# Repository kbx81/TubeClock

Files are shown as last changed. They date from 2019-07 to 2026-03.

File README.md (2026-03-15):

# kbx's Nixie Clock

Nixie Clock project files - PCB and source

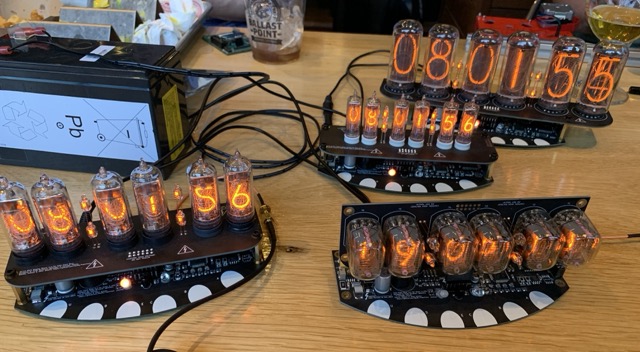
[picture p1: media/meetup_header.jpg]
Nixie clocks!


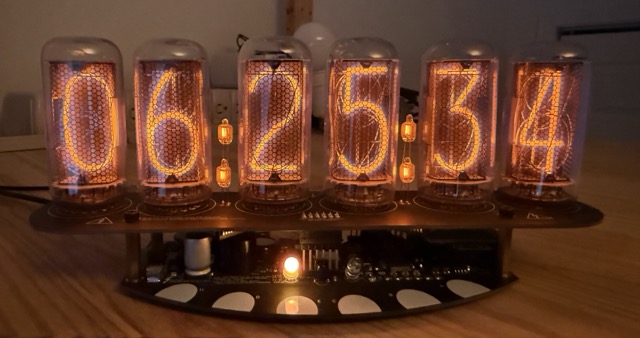
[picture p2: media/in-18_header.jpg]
IN-18


For more pictures, see the [gallery](GALLERY.md).

## Another nixie tube clock? Why?

I have to start by giving credit where credit is due. The
[Boldport Club](http://boldport.club), over the last couple of years, has
motivated me to dwell back into the world of electronics, at least as a
hobbyist. Both the kits themselves and the other members in the club are
amazing and helped inspire me to make something...so I began working on this
project. Some inspiration is taken from
[Touchy, BPC Project #7](https://www.boldport.com/products/touchy); this kit
enabled me to learn more about and actually experiment with capacitive touch.
It was clear early on that this would be a nice touch (pun intended) to add to
this project; visually, it is cleaner, it reduces the number of parts and, as a
result, it reduces the cost.

That said, the world probably doesn't need another tube clock. There are
plenty of them--all different shapes and sizes--so why build another one?

Last year, I built this lovely
[binary clock](https://github.com/kbx81/RGBBinaryClock). Some ten-plus years
ago I had built some IN-18 nixie clocks. Earlier this year (2019) one of them
became a little troublesome. I fixed it but, in the interim, became motivated
to build my own. As I already had a wonderful foundation for some clock
hardware, this seemed a natural progression. Overall I'm quite happy with the
results if I may say so myself. :)

_Sooo...another nixie clock? What's special about it?_

**Time & display**
- Shows time, date, and temperature — with a timer/counter mode, too
- 12/24-hour format and °C/°F selectable
- Smooth digit crossfades with configurable animations and effects
- Auto-dims based on ambient light — great for a bedside clock :)

**Time sources** _(all optional — mix and match)_
- GPS sync via a soldered-on LIV3F module or an
  [Adafruit GPS breakout](https://www.adafruit.com/product/746)
- External DS3234 precision RTC
- CR2032 battery or supercapacitor backup to keep time through a power outage

**Control & connectivity**
- Capacitive touch keys
- IR remote control
- [Serial remote protocol](docs/SERIAL_API.md) over UART or USB (CDC-ACM
  virtual serial port)
- Optional Wi-Fi add-on board for wireless control -- I even built an
  [ESPHome external component](https://github.com/kbx81/esphome_external_components/tree/main/components/tube_clock)
- DMX-512 via RS-485 — control each tube individually from a lighting console

**Alarms & audio**
- Up to 8 configurable alarm times with optional display blink
- Hourly binary chime — hear the time from another room!
- RTTTL melody playback
- External alarm trigger via expansion pin header

## What makes it tick?

The brain is an **STM32F072** microcontroller — capable enough on its own, but
with optional add-ons for those who want more:

- **DS3234** — high-accuracy external RTC (also has a built-in temperature sensor)
- **DS1722 / LM74** — dedicated external temperature sensors
- **LIV3F** or **[Adafruit GPS module](https://www.adafruit.com/product/746)**
  for synchronizing time from GPS

The display boards use **HV5622** high-voltage shift registers to drive the
tubes, an **RGB status LED** for at-a-glance info, and a **piezo beeper**
capable of playing RTTTL tunes. An onboard phototransistor handles ambient
light sensing for automatic brightness control.

## How do I get or build one?

In this repository you'll find everything needed to put one together. It is
divided into two major parts: hardware and software (source). The `hardware`
directory contains the [KiCad](http://kicad.org) project files used to create
the printed circuit board. The `src` directory contains the source code needed
to compile and run the application on the microcontroller. It is built on top
of [libopencm3](http://libopencm3.org). Finally, then `bin` directory contains
compiled binary files you may flash directly onto the microcontroller...great
for folks who want to solder something together but don't want to be bothered
with compiling code!

Additional details regarding the hardware and software can be found in the
`README.md` files located in each respective directory.

**That's all for now...thanks for visiting!**

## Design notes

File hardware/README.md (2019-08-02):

# kbx's Tube Clock

Tube Clock PCB project files for KiCad (v5)

## How do I get PCBs made for this?

Detailing the process is a bit outside of what I plan to discuss here. There are
 plenty of resources out around the web already that will do a better job of
 explaining this process than I can. That said, there's not much to it -- the
 files you need are here and all you need to do (more or less) is upload them
 to your PCB fabricator of choice and, after a few days, they'll ship them
 to you. I've used [Elecrow](http://elecrow.com) for the prototypes and I can
 assure you that they've turned out fantastic boards given the price.

As the vast majority of the components on this board are surface-mount parts,
 hot air is a fun approach for soldering it all together. If you go this route
 (and especially if you plan to build more than one of them), you'll likely want
 to have a stencil made to help with the placement of solder paste onto the
 board. I ordered a stencil with my board from [Elecrow](http://elecrow.com).

## If I get boards made, how do I build it?

All the components are listed in the KiCad project files here; one will also
 find bill of materials (BoM) files named `TubeClock.BoM.md` or `IN-1x.BoM.md`
 containing these lists. For "unusual" parts (things that aren't resistors or
 capacitors) I've noted a suggested part number that should serve as a point of
 reference to help you find your own.

Before you order parts, be sure to read through the build notes below!

Once you have your boards and parts, there are at least a couple of different
 ways you can build the clock base. Below are build notes.

## Build notes

### Before you begin...

...you need to determine:
1. What will your time source be -- the STM32's RTC, the DS3234, or a GPS
 module? The GPS will provide the best accuracy, followed by the DS3234. That
 said, these ICs will add approximately $10 to $20 USD to the cost of the
 device. If you're purchasing them, double-check those part numbers before
 ordering!
1. What temperature sensor will you use -- the STM32's internal sensor, the
 DS3234's sensor, or a dedicated sensor? The DS1722 or LM74 dedicated sensors
 will provide the best accuracy; however, if one of these ICs is not installed
 but a DS3234 *is* installed, the app will use the DS3234's sensor. Note that,
 while the PCBs have footprints for more than one temperature sensor, only
 **one** of them may be installed at a time. Do not install both!
1. Solder-bridge/jumper settings. These are explained below...but don't forget
 about these!

Once you've settled on the items above, read on (below) for more detail and
 specifics regarding the build.

### Build details

#### GPS:

The clock's application will accept and decode NMEA sentences from an attached
 GPS module. The PCBs will accept a plug-in module from
 [Adafruit](https://www.adafruit.com/product/746) or a Teseo-LIV3F module can
 be installed for a more permanent solution. Testing reveals that both of these
 modules work extremely well and will provide the most accurate time for the
 clock. Note that the LIV3F module will require some additional components to
 operate; several of these parts are 0402-sized (which means that they are very,
 very tiny!) and, as such, are challenging to work with. This approach is best
 for experienced builders with tooling available to work on such tiny parts.

#### External RTC:

The external RTC--the DS3234--adds a level of precision to the clock that is
 likely difficult to achieve with the STM32's internal RTC alone. These RTC ICs
 are designed to drift less than two minutes _per year_. It's possible that your
 STM32 hardware could end up being this accurate, but such accuracy is unlikely.
 Install this IC if you want a clock that is as accurate as is reasonably
 possible without depending on GPS. Note that this IC also has a built-in
 temperature sensor (that's part of how it maintains its precision) that the
 application will use if it is installed and the other external temperature
 sensor (below) is _not_ installed.

If you install a DS3234 on your clock, **do not install** these components:
 - `C23`
 - `R16`

#### External temperature sensors:
**U6 and U7**

A challenge with using the STM32's internal temperature sensor is that the
 sensor typically reads a few degrees higher than the temperature around the
 MCU itself. This is because the die, where the sensor is located, is usually
 just a little bit warmer then the package around it. An easy workaround is to
 just subtract a few degrees from the reading -- hence the calibration item
 you'll find in the application's menu structure. It works, but it requires
 someone to tweak it as each chip is likely to be a little different. Naturally,
 this takes away from its accuracy.

Installing an external temperature sensor is a great solution to this problem.
 The application will prefer an external sensor if one is installed; it first
 prefers one of the dedicated temperature sensors. If not installed, it will try
 to use the sensor integrated into the DS3234, should one be installed. If these
 all fail, it will use the STM32's internal sensor as a last resort.

**IMPORTANT NOTE: the PCBs (all hardware versions) have footprints for two
 external temperature sensor ICs. ONLY INSTALL ONE of them. DO NOT INSTALL
 BOTH.** If you install both, neither of them will work and you may cause damage
 to them or to other ICs on the board.

#### RS-485 transceiver:
**U8**

This part will enable the the second USART in the STM32 MCU to be used to
 communicate on an RS-485 bus. The original intention for this feature was to
 enable the device to receive a DMX-512 signal from an entertainment lighting
 console. With some development, it could also be used (for example) to
 synchronize a number of clocks with each other. This interface is more of a toy
 and has no impact on how the clock itself will function. You'll likely want to
 leave it off of the board unless you have a specific plan to use it for
 something.

#### Infrared (IR) receiver module:
**U4**

If the infrared remote control is not needed, this component may be left off of
 the board.

#### Buzzer/beeper components:
**BZ1, D6, Q6, R29**

If you don't want your clock to be able to make any noise at all, it is safe to
 leave these parts off of your board. It'll be sad, but it'll work just fine.

#### Status LED components:
**LED1, LED2, Q3 through Q5, R23 through R28**

The status LED is not typically used during normal operation, however it can be
 enabled as an AM/PM indicator if/when the clock is set in 12-hour mode. It can
 also provide troubleshooting information if your clock doesn't seem to be
 working. That said, it's not necessary unless you like LEDs as much as I do.

#### Reset/Boot buttons:

The reset and boot buttons are of course not required, but it is convenient if
 you plan to do any development with this platform on your own.

### Other requirements

#### 32.768 kHz crystal installation and connection:

A footprint for a 32.768 kHz crystal exists on the PCB. It is used to drive the
 STM32's internal RTC mechanism. This crystal is particularly important if the
 DS3234 IC is **not** installed; in this case, it must be connected to the MCU
 by creating a solder bridge across the appropriate two pads on `SB2`. Failure
 to do so--and if the DS3234 is not installed--means the clock won't run
 (although things otherwise may seem to work).

If the DS3234 **is** installed, `SB2` may be bridged so as to connect the
 DS323x's 32.768 kHz signal output to the STM32's OSC32 input. This is not
 required but it is recommended so that this MCU input isn't left floating. In
 addition, if `SB2` is bridged in this manner, the 32.768 kHz crystal (and its
 drive capacitors) should **not** be installed.

#### Phototransistor series resistors:
 **Q2, RV2, R7 and R10**

The phototransistor enables the application to determine the amount of ambient
 light around the clock so it can adjust the overall display intensity
 accordingly. There is a variable resistor in series with a fixed resistor which
 allows some manual adjustment over the sensitivity of this mechanism. There is
 also a single fixed resistor in parallel with this configuration. It is not
 necessary to install all of these, however it won't hurt anything if you do.
 If the specified phototransistor is used, a single 100K to 150K resistor
 installed for `R10` will probably work well.

#### Status LED:

If installing a status LED, install only LED1 **or** LED2. Do not install both.

### Solder Bridge Jumpers

#### Pulse-Per-Second (PPS) input selection
**SB1**

This jumper determines which peripheral will provide the pulse-per-second input
 to the processor (and application). This enables more precise refreshing of the
 display and allows the application to operate more efficiently. If neither of
 these peripherals is installed, this jumper is not used.

#### 32.768 kHz Oscillator jumper
**SB2**

This jumper determines if the 32.768 kHz oscillator or the DS3234's 32.768 kHz
 output pin is connected to the STM32's OSC32_IN pin. If a DS3234 is **not**
 installed on the board, it must be bridged so that the crystal's pin is
 connected to the OSC32_IN pin. Otherwise, it's best to bridge it to the
 DS3234's 32.768 kHz output pin. Labels on the PCB indicate which position is
 which.

#### USART 1/USB VBUS jumpers
**SB3, SB4**

These jumpers allow the configuration of which USART1 pin on the MCU is
 connected to the six-pin serial header. Because the processor's USB hardware
 expects USB VBUS on PA9, if you plan to use the USB port, SB4 should be bridged
 and SB3 should be bridged to put PB6 on the on the six-pin header. If you do
 not want/need to use the USB port and wish to flash the MCU via the six-pin
 header, SB4 must be left **open** and SB3 should be bridged to put PA9 on the
 six-pin header.

#### Reset Supervisor jumper
**SB5**

 This jumper determines if the DS3234's reset supervisor output pin is connected
  to the STM32's NRST (not-reset) pin. This should be connected if the DS3234 is
  installed, however it sometimes causes issues with flashing the MCU. If you
  installed a DS3234 and are having difficulty flashing the MCU, try
  disconnecting this jumper until the flashing process is complete. Don't forget
  to reconnect it, though!

#### RS-485 Terminator jumper
**SB6**

Bridge this jumper to connect the terminating resistor across the RS-485
 transceiver's input/output pins. This is useful if the board is at the end of
 a RS-485 link.

#### GPS receive and transmit lines
**SB7, SB8**

Bridge these jumpers to connect the GPS module's receive (Rx) and transmit (Tx)
 lines to the STM32 processor's USART1 interface. These jumpers are provided as
 a convenient way to disconnect the serial data lines in the event that USART1
 must be used for programming or debugging after the board has been built,
 particularly with the LIV3F module.

## Before powering it on for the first time...

WAIT! you didn't plug it in yet, did you? Let's do some pre-flight checks to get
 ready to bring up your board!

It's important that we go over the board with a DMM (or at least a continuity
 tester) and check for any nasty shorts. Solder bridges and poor part placement
 are the typical causes of this and it's not uncommon to have them, particularly
 with so many surface-mount parts. We don't want our brand-new clock to let out
 the magic smoke before we even get to use it, do we? :)

Generally, it will suffice to check a few key areas for shorts. Since these are
 surface-mount ICs, it's not uncommon to have solder bridges between some of the
 pins after you've soldered it all together. Don't worry, we can get away
 without checking _all_ of them, but we _do_ need to check a few. Let's make a
 list so we can check them off:
* **Check for shorts between the output of the LDO and ground.** Put one of your
 DMM probes on the power connector's ground pin and the other on the LDO's
 heatsink (the top fin soldered to the board -- this is its 3.3-volt output). If
 you see they're shorted, you'll have to go hunting for the short. Start by
 checking the power pins around the STM32 processor. All of its Vcc and ground
 pins are right next to each other so this is the best place to look first.
* **Check for shorts on the display pin header.** Note that there are multiple
 ground pins on this header so they will naturally appear to be shorted. It is
 important to check for shorts between the pins that supply the various voltages
 to the display board (3.3, 12, and 170 volts). Shorts between any of these pins
 will be disastrous!
* **Check that the solder bridge "jumpers" are set correctly.** You didn't
 forget to bridge these as appropriate, did you? :) See the "Jumpers" section
 above for information on how they should be set.

Once you've confirmed everything above looks good, it should be reasonably safe
 to proceed to the next step -- flashing the firmware onto the STM32 processor!
 After we do this, we'll be able to more effectively identify any other
 soldering-related issues that could be affecting the clock's operation.

After you power on your board for the first time--and if nothing blows
 up--you'll need to flash the firmware onto the STM32 MCU. Use either the USB
 interface, the SWD connection on P1, or the serial interface on J5. You'll need
 an appropriate adapter and/or cable to do so. You will find the source code and
 flashing instructions in the `src` folder one level up in the repo's hierarchy.
 The `bin` directory contains complied binary files for folks who do not wish to
 compile the source code. With the right tools in hand, this can be done in a
 couple of minutes.

If you're having trouble flashing the MCU, please see the next section.

## Troubleshooting

What's that? You couldn't flash the MCU? Or maybe it isn't working perfectly
 after you flashed the MCU? Uh oh...

As I've built...a few...of these to date, here is a list of common issues I've
 stumbled across as well as some notes on how to fix them.

If you're having trouble flashing the MCU, check these items first:
* If a DS3234 is installed, is the reset supervisor jumper bridged? If so, this
 may be holding the STM32 in a reset state too long and your programmer is
 giving up. Open this jumper and try again.
* If there is no DS3234 installed and/or the jumper is already open, check the
 data lines between the port you're using (six-pin serial, USB, or SWD) and the
 processor. Perhaps there is another nasty solder bridge somewhere that's
 shorting one or more of the lines to Vcc, ground, or another adjacent pin. If
 you're using the USB interface, take a close look at D5 and the physical USB
 port itself, as well. The pins on the USB connector are prone to bridging.

If you flashed the MCU and it's now doing...something...but it doesn't seem
 right, here are some more common symptoms and how to fix them:

* **Status LED blinks orange/off but the tubes are blank or flickering
 erratically.** This is indicative of some soldering problem on the SPI1 pins
 of the MCU or on one or more of the HV5622 drivers. Take a close look at these
 pins and rework them as necessary. Also be sure the socket on the display board
 is seated sufficiently onto the logic board's display pin header.
* **One or more of the touch keys don't work.** Check the 1K resistors that sit
 between the touch keys and the MCU as well as the 47 nF sense capacitors.
 Again, also check the relevant pins on the MCU itself for shorts to adjacent
 pins (this is the most common issue).
* **It keeps making a ticking sound.** There's a problem with one or more of the
 touch keys -- see the item above.
* **The status LED alternates red and yellow.** You did not install a DS3234 (or
 maybe you did and it's not working) and the STM32's RTC/LSE oscillator did not
 start within the expected amount of time. Check that `SB2` is bridged correctly
 and that the 32.768 kHz crystal and its bypass capacitors are installed and
 soldered correctly. Also check that the respective pins on the STM32 processor
 aren't shorted to adjacent pins (or to each other).

## Known Issues and Noteworthy Items

Heat from the boost converter (the part that generates the high voltage for the
 tubes) or GPS module can skew the temperature reading from the sensor on the
 board. This becomes more noticeable as the tubes become brighter. The PCBs
 include footprints for additional 2.54mm pin headers which could be used for
 mounting the temperature sensor(s) off of the main board.

## Legal stuff and License

The circuit schematics and PCBs found here are licensed under the
 [Creative Commons Attribution-ShareAlike 4.0 International License](http://creativecommons.org/licenses/by-sa/4.0/).



_Happy building!_

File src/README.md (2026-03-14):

# kbx's Tube Clock

Tube Clock firmware source files

## What's going on here?

Here you will find the C++ source code files for the Tube Clock. It is
modularized so that its various parts can be broken out and potentially re-used
for other projects. It's not perfect but it works well and the plan is to
continue to update and improve it over time.

The firmware implements all of the clock's functionality from the simple display
of the time and date through animation selection and management, alarms, and
even DMX-512 control for the display tubes. It could be easily modified to
provide a variety of other capabilities if desired.

## More specifics

The code is written for the STM32F072 microcontroller used on the Tube
clock. With a little effort, it should be relatively easy to port it to another
STM32Fx-series MCU. It relies on [libopencm3](http://libopencm3.org) as the
underlying platform to interface with the MCU. If you wish to do some hacking
with this platform, a nice guide can be found
[here](https://github.com/libopencm3/libopencm3-examples#reuse) which explains
how to clone libopencm3 for (re)use within your own (or this) project. Note
that if you do so, it may be necessary to tweak some paths in the Makefile(s),
but otherwise things should work without much trouble. You'll also (of course)
need a (gcc) compiler to build the code base. (At the time of this writing,
I've been building it with gcc on macOS.)

The STM32F072 microcontroller is a rich device with a lot of peripherals. Many
of these peripherals are leveraged in the code to enable it work as efficiently
as possible. For posterity, here is a list of the peripherals used:

- ADC - the analog to digital converter, used for sensing light level from the
  attached phototransistor
- CRC - used to compute a checksum for settings data stored in FLASH
- DMA - direct memory access controller, used to speedily move data to/from
  other I/O peripherals such as I2C, SPI, and USARTs
- FLASH controller - erases and writes settings to a dedicated block of FLASH so
  settings are retained across power failures and do not depend on the battery
- GPIO - because how else do you toggle pins on/off or read input signals?
- IWDG - the watchdog timer makes sure the MCU gets reset in the event of some
  catastrophic software crash/failure
- NVIC - none of this would be possible without interrupts.
- RTC - the real time clock is used if the DS3234 is not installed. Since it's a
  clock, you need a clock...sooooo...
- SPI - this is the interface (via DMA) to the tube driver ICs. It is also the
  interface to the DS3234 and other temperature sensors.
- Timers - Timers 1 and 3 are used to generate PWM for the buzzer and for the
  status LEDs, respectively. Timers 15 and 16 are used to supervise DMX-512
  communication. Timer 7 times pulses from the IR receiver and timer 2 generates
  an interrupt (at ~15.4 KHz) to trigger a refresh of the tubes, emulating PWM
  and thus enabling the digit dimming/fading effect.
- TSC - the touch sensing controller is used to sense touches on the touch keys.
- USARTs:
  - USART1 is a general serial interface connected to an optional GPS module; it
    also participates in the [serial remote control protocol](../docs/SERIAL_API.md)
    (see below).
  - USART2 is connected to an RS-485 transceiver; the firmware receives DMX-512
    signals on USART2 so that the tubes can be individually controlled remotely.
  - USART3 (RX) and USART4 (TX) form a secondary serial interface which supports
    the clock's bidirectional [serial remote control protocol](../docs/SERIAL_API.md).
  - Serial remote commands and responses are handled on both the USART1 and
    USART3/4 interfaces simultaneously. The same serial remote control protocol
    is also accessible via a USB CDC-ACM (virtual serial port) interface. See
    the [Serial Remote Control API](../docs/SERIAL_API.md) for the full protocol
    reference.

## Important!

When compiling (with gcc), you'll need to add `-DHARDWARE_VERSION=X` to the
command line, where `X` is the major version number of the hardware (PCB)
you're targeting. At the time of this writing, there is only one major hardware
version. Note that this switch has already been added to the included
Makefile. Please be aware of this if you choose to build it yourself and/or do
some hacking!

## I want to hack. Where do I start?

`TubeClock.cpp` is where it all begins. This connects the various
interrupts to the appropriate functions for processing them, initializes the
hardware, initializes the main application, then passes control to the main
application loop. See `Application.cpp` and `Hardware.cpp` and work your way
through the rest from there.

To build the code, there is a basic Makefile in the `src/v1` directory; simply
run `make` and it'll build what you need. Then, you can write the resulting
binary to the STM32 via an ST-Link with:

```shell
st-flash write TubeClock.bin 0x08000000
```

For more advanced debugging, you can use GDB. Run `st-util --n` followed by
`arm-none-eabi-gdb TubeClock.elf --init-eval-command="target remote 127.0.0.1:4242"`
to connect.

Please don't hesitate to reach out with any questions or comments -- it is nice
to hear feedback. Happy hacking!

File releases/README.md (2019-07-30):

# kbx's Tube Clock

Tube Clock compiled binary files

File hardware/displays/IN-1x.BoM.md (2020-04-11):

# Nixie Tube Display Board Bill of Materials (BoM)

## Parts

|Reference |Quantity|Value |Footprint |
|---|---|---|---|
|C2 C1 C3 C4 C5 |5 |100 nF, 16 V |Capacitor_SMD:C_0805_2012Metric |
|D1 |1 |1N4148 |Diode_SMD:D_SOD-123 |
|J1 |1 |Conn_02x06_Odd_Even |Connector_PinSocket_2.54mm:PinSocket_2x06_P2.54mm_Vertical|
|J2 |1 |Conn_02x06_Odd_Even |Connector_PinHeader_2.54mm:PinHeader_2x06_P2.54mm_Vertical|
|NE4 NE3 NE1 NE2 |4 |Lamp_Neon |Connector_PinHeader_2.54mm:PinHeader_1x02_P2.54mm_Vertical|
|R10 R9 R8 R7 |4 |470K |Resistor_SMD:R_1206_3216Metric |
|R11 R12 R13 R14 R15 R16 R17 R18 R19 R20 R21 R22 R23 |13 |10K |Resistor_SMD:R_0805_2012Metric |
|R6 R3 R5 R4 R2 R1 |6 |10K (2K2 for IN-18) .25 W|Resistor_SMD:R_1206_3216Metric |
|T1 T2 T3 T4 T5 T6 |6 |IN-1x_Nixie_Tube |TubeClock:Nixie_IN-1x |
|U1 |1 |CD40109B |Package_SO:SOIC-16W_5.3x10.2mm_P1.27mm |
|U2 U3 U4* |3 |HV5622 |Package_LCC:PLCC-44_16.6x16.6mm_P1.27mm |

## Additional parts you may need

For IN-12 and IN-18 boards, machine pin sockets are highly recommended -- **do not** solder the tubes into the boards! `Mill-Max` part number `0327-0-15-01-34-27-10-0` is a perfect fit for these tubes!

For the seperator/colon indicator lamps (NE1 through NE4), any "A1B" neon indicator lamp should suffice. I used `VCC` part number `A1B`. Some `INS-1` tubes should also work well, particularly on the IN-12 boards.

## IMPORTANT!

**Pay extra super close attention to the polarity of D1!** Bad things will happen if it is installed backwards. :(

### Notes

For IN-12 and IN-18 tubes, use machine pin sockets suggested above. Since IN-14 and IN-16 tubes have wire leads, they should be soldered directly into the boards.

*U4 is not present on IN-18 display boards. On the other boards, it is not required if you don't care about the lovely decimal points in the smaller tubes. :) **Bridge the solder jumper if U4 is *not* installed** on these boards.

R12 through R23 are additional series resistors for tube decimal points. They are not present on IN-18 boards and are otherwise not necessary if decimal points will not be used.

## Are you shopping?

I've created an [Octopart](https://www.octopart.com) BoM [here](https://octopart.com/bom-tool/LsrgprMy)!

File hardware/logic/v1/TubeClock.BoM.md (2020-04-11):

# Tube Clock Logic Board Bill of Materials (BoM)

## Parts

|Reference |Quantity|Value |System Component |Datasheet |Part Number |Notes |Suggested Part |Manufacturer|Footprint |
|---|---|---|---|---|---|---|---|---|---|
|BT1 |1 |CR2032 |Backup Power |[Datasheet](http://www.keyelco.com/product.cfm/product_id/719) |103 | |3034 |Keystone |TubeClock:BatteryHolder_Keystone_3034_1x20mm |
|BZ1 |1 |Buzzer |Alarm |[Datasheet](https://product.tdk.com/en/search/sw_piezo/sw_piezo/em-buzzer/info?part_no=SD1614TT-B1) |TDK SD1614TT-B1 | | | |TubeClock:Buzzer_16x14RM7.6 |
|C1 |1 |100 uF 16 V | |[Datasheet](https://industrial.panasonic.com/ww/products/capacitors/polymer-capacitors/os-con/svf/25SVF100M) |25SVF100M | | | |Capacitor_SMD:CP_Elec_8x10 |
|C10 |1 |100 uF 6.3 V | | | | | | |Capacitor_SMD:CP_Elec_5x5.3 |
|C12 |1 |470 mF 5 V | |[Datasheet](http://www.cooperindustries.com/content/dam/public/bussmann/Electronics/Resources/product-datasheets/Bus_Elx_DS_4327_KR_Series.pdf) |KR-5R5C474-R | | | |TubeClock:CP_Radial_D13.0mm_P5.00mm_HD1.5mm |
|C13 |1 |10 nF | | | | | | |Capacitor_SMD:C_0805_2012Metric |
|C14 |1 |1 uF | | | | | | |Capacitor_SMD:C_0805_2012Metric |
|C16 C20 |2 |4.7 uF | | | | | | |Capacitor_SMD:C_0805_2012Metric |
|C2 |1 |100 uF 20 V |Boost converter | | |Tantalum, EU 7343 case, polarized |TPSD107M020R0085 | |Capacitor_Tantalum_SMD:CP_EIA-7343-31_Kemet-D |
|C21 C22 |2 |47 nF | | | | | | |Capacitor_SMD:C_0805_2012Metric |
|C24 C25 |2 |10 pF | | | | | | |Capacitor_SMD:C_0805_2012Metric |
|C26 C27 |2 |12.5 pF | | | | | | |Capacitor_SMD:C_0805_2012Metric |
|C3 |1 |4.7 uF 250 V |Boost converter | | |Electrolytic, polarized, up to 10 uF is ok |EEV-EB2E100Q | |Capacitor_SMD:CP_Elec_10x10 |
|C33 C43 |2 |1 nF |GPS antenna power/FE | | | | | |Capacitor_SMD:C_0805_2012Metric |
|C34 C35* C36* |3 |120 pF |GPS antenna power/FE | | |GPS antenna front end | | |Capacitor_SMD:C_0402_1005Metric |
|C38 C37 C39 C40 C41 |5 |3.9 pF |GPS antenna front end | | |DNF! (Do Not Fit) | | |Capacitor_SMD:C_0402_1005Metric |
|C4 |1 |10 uF 25 V |Boost converter | | |Tantalum, EU 7343 case, polarized |TPSD106K035R0300 | |Capacitor_Tantalum_SMD:CP_EIA-7343-31_Kemet-D |
|C7 |1 |100 nF 250 V |Boost converter | | |Optional |ECWU2104KC9 | |TubeClock:C_2420_HandSoldering |
|C8 C11 C5 C6 C23 C17 C15 C18 C19 C28 C29 C31 C32 C30 |14 |100 nF | | | | | | |Capacitor_SMD:C_0805_2012Metric |
|C9 C42 |2 |10 uF | | | | | | |Capacitor_SMD:C_0805_2012Metric |
|D1** |1 |S3A |Reverse polarity protection |[Datasheet](http://www.onsemi.com/pub/Collateral/S3N-D.PDF) |S3A | | | |Diode_SMD:D_SMC |
|D2 |1 |ES2F |Boost converter | | | | | |Diode_SMD:D_SMB |
|D3 |1 |BAT64-04 |Backup Power |[Datasheet](https://www.infineon.com/dgdl/Infineon-BAT64SERIES-DS-v01_01-en.pdf?fileId=db3a304314dca3890115191757980ead) | | | | |Package_TO_SOT_SMD:SOT-23 |
|D4 |1 |BAT64-02V |Backup Power |[Datasheet](https://www.infineon.com/dgdl/Infineon-BAT64SERIES-DS-v01_01-en.pdf?fileId=db3a304314dca3890115191757980ead) | | | | |Diode_SMD:D_0603_1608Metric |
|D5 |1 |USBLC6 |USB | | | | | |Package_TO_SOT_SMD:SOT-23-6 |
|D6 |1 |1N4148 |Alarm |[Datasheet](https://www.diodes.com/assets/Datasheets/ds30086.pdf) | | | | |Diode_SMD:D_SOD-123 |
|F1 |1 |~500mA | |[Datasheet](http://m.littelfuse.com/~/media/electronics/datasheets/resettable_ptcs/littelfuse_ptc_2920l_datasheet.pdf.pdf) |2920L050DR | | | |Fuse:Fuse_2920_7451Metric |
|FL1 |1 |B39162B4327P810 |GPS antenna front end |[Datasheet](https://en.rf360jv.com/inf/40/ds/ae/B4327.pdf) | |GPS antenna front end* | | |TubeClock:Filter_1411-5_1.4x1.1mm |
|J1 |1 |Jack-DC | | | | | | |Connector_BarrelJack:BarrelJack_Horizontal |
|J2 |1 |Conn_02x08_Odd_Even |GPIO | | | | | |Connector_PinHeader_2.54mm:PinHeader_2x08_P2.54mm_Vertical |
|J3 |1 |Conn_02x05_Odd_Even |GPIO-SPI | | | | | |Connector_PinHeader_2.54mm:PinHeader_2x05_P2.54mm_Vertical |
|J4 |1 |Conn_02x06_Odd_Even |Display header | |DW-06-09-T-D-500 |~14 mm height, board stacking connector |DW-06-09-T-D-500 |Samtec |Connector_PinHeader_2.54mm:PinHeader_2x06_P2.54mm_Vertical |
|J5 |1 |Conn_01x06 |USART1 header | | | | | |Connector_PinHeader_2.54mm:PinHeader_1x06_P2.54mm_Vertical |
|J6 |1 |Conn_02x03_Odd_Even |RS-485 header | | | | | |Connector_PinHeader_2.54mm:PinHeader_2x03_P2.54mm_Vertical |
|J7 |1 |Conn_01x07 |GPS plug-in module | | | | | |Connector_PinSocket_2.54mm:PinSocket_1x07_P2.54mm_Vertical |
|J8 |1 |Conn_Coaxial |GPS antenna | | | | | |Connector_Coaxial:U.FL_Molex_MCRF_73412-0110_Vertical |
|L1 |1 |100µH 2A |Boost converter | | |SMT power inductors |Epcos B82479-A1-104M| |TubeClock:L_EPCOS_B82479A1_Handsoldering |
|L2 |1 |100 nH |GPS antenna power | |LQG15HNR10J02D |GPS antenna front end |LQG15HNR10J02D |Murata |Inductor_SMD:L_0402_1005Metric |
|L3 |1 |5.6 nH |GPS antenna front end | |0402CS-5N6XJLU |GPS antenna front end* |0402CS-5N6XJLU |CoilCraft |Inductor_SMD:L_0402_1005Metric |
|LED1 |1 |LED_RGB_COMMON_ANODE|Status LED |[Datasheet](https://www.adafruit.com/product/302) | |Install LED1 **or** LED2. Do not install both! | | |LED_THT:LED_D5.0mm-4_RGB |
|LED2 |1 |LED_Dual_AACC |Status LED |[Datasheet](https://www.vcclite.com/product/led-smt-1206-1-72-1v-20ma-redgreen-2k/) |CMD1522SRUGCTR8 |Install LED1 **or** LED2. Do not install both! | | |LED_SMD:LED_Cree-PLCC4_3.2x2.8mm_CCW |
|P1 |1 |STM32_SWD_USART |SWD header |[Datasheet](https://www.harwin.com/products/M50-3600542R/) |M50-3600542R | | | |Connector_PinHeader_1.27mm:PinHeader_2x05_P1.27mm_Vertical_SMD|
|P2 |1 |CONN_MICRO_USB_B |USB | | | | | |Connector_USB:USB_Micro-B_Molex-105017-0001 |
|Q1 |1 |IRF644PBF |Boost converter |[Datasheet](http://www.vishay.com/docs/91039/sihf644.pdf) | | | | |Package_TO_SOT_THT:TO-220-3_Horizontal_TabDown |
|Q2 |1 |Q_Photo_NPN |ALS |[Datasheet](https://www.vishay.com/docs/84768/tept5600.pdf) |TEPT5600 | | | |LED_THT:LED_D5.0mm_Clear |
|Q4 Q3 Q6 Q5 |4 |2N7002 |Alarm, Status LEDs |[Datasheet](https://www.diodes.com/assets/Datasheets/ds11303.pdf) | | | | |Package_TO_SOT_SMD:SOT-23 |
|R1 R32 |2 |100K | | | |Use any generic resistor | | |Resistor_SMD:R_0805_2012Metric |
|R10 R23 R24 R29 R25 |5 |1M | | | | | | |Resistor_SMD:R_0805_2012Metric |
|R17 |1 |68K |USB | | | | | |Resistor_SMD:R_0805_2012Metric |
|R18 |1 |47K |USB | | | | | |Resistor_SMD:R_0805_2012Metric |
|R2 |1 |1.5M | | | |1 watt 5% | | |Resistor_SMD:R_2512_6332Metric |
|R21 |1 |120 |RS-485 | | | | | |Resistor_SMD:R_0805_2012Metric |
|R22 |1 |0 |RS-485 | | | | | |Resistor_SMD:R_0805_2012Metric |
|R3 |1 |56Ω 0.5W |Backup Power | | | | | |Resistor_SMD:R_0805_2012Metric |
|R30 R31 |2 |0 |GPS antenna FE bypass | | |GPS antenna front end | | |Resistor_SMD:R_0402_1005Metric |
|R4 R16 R13 R14 R7 R15 R20 R19 R33 |9 |10K | | | |Use any generic resistor | | |Resistor_SMD:R_0805_2012Metric |
|R5 R6 R8 R9 R11 R12 R27 R26 R28 |9 |1K | | | | | | |Resistor_SMD:R_0805_2012Metric |
|RSENSE1 |1 |.05 |Boost converter | | |2A current rating - 1 Watt in a 2010 package |Welwyn LR2010-R05FW | |Resistor_SMD:R_2010_5025Metric |
|RV1 |1 |5K |Boost converter | | |Multi-turn - Any similar will do |Bourns 3214W-1-502E | |Potentiometer_SMD:Potentiometer_Bourns_3214W_Vertical |
|RV2 |1 |100K |ALS |[Datasheet](http://www.bourns.com/docs/Product-Datasheets/TC33.PDF) |TC33X-2-104E | | | |Potentiometer_SMD:Potentiometer_Vishay_TS53YJ_Vertical |
|SW2 SW1 |2 |SW_Push | |[Datasheet](https://www.ckswitches.com/media/1479/kmr2.pdf) |KMR221G LFS | | | |Button_Switch_SMD:SW_Push_1P1T_NO_CK_KMR2 |
|U1 |1 |MAX1771 |Boost converter | | | | | |Package_SO:SOIC-8_3.9x4.9mm_P1.27mm |
|U10 |1 |Teseo-LIV3F |GPS module |[Datasheet](https://www.st.com/resource/en/datasheet/teseo-liv3f.pdf) | |GPS receiver | |ST |TubeClock:LCC-18 |
|U11 |1 |TPS22943 |GPS antenna power |[Datasheet](http://www.ti.com/lit/ds/symlink/tps22929d.pdf) | |GPS antenna front end | | |Package_TO_SOT_SMD:SOT-353_SC-70-5 |
|U2 |1 |LD1117DT33CTR | |[Datasheet](http://www.st.com/content/ccc/resource/technical/document/datasheet/a5/c3/3f/c9/2b/15/40/49/CD00002116.pdf/files/CD00002116.pdf/jcr:content/translations/en.CD0000211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)|LD1117DT33CTR | | | |Package_TO_SOT_SMD:TO-252-2 |
|U3 |1 |STM32F072RBTx |Processor | | | | | |Package_QFP:LQFP-64_10x10mm_P0.5mm |
|U4 |1 |TSOP382xx |Infrared Remote |[Datasheet](http://www.vishay.com/docs/82491/tsop382.pdf) | | | | |OptoDevice:Vishay_MINICAST-3Pin |
|U5 |1 |DS3234 |RTC |[Datasheet](https://datasheets.maximintegrated.com/en/ds/DS3234.pdf) | |Optional; fit for better long-term accuracy | |Maxim |Package_SO:SO-20_12.8x7.5mm_P1.27mm |
|U6 |1 |LM74 |Temperature sensor |[Datasheet](http://www.ti.com/lit/ds/symlink/lm74.pdf) |LM74CIMX-3/NOPB |Optional; install U6 **or** U7. Do not install both!| | |Package_SO:SOIC-8_3.9x4.9mm_P1.27mm |
|U7 |1 |DS1722 |Temperature sensor |[Datasheet](https://datasheets.maximintegrated.com/en/ds/DS1722.pdf) | |Optional; install U6 **or** U7. Do not install both!| | |Package_SO:SOIC-8_3.9x4.9mm_P1.27mm |
|U8 |1 |MAX485E |RS-485 |[Datasheet](http://www.st.com/content/ccc/resource/technical/document/datasheet/81/93/fa/ed/87/47/46/00/CD00003136.pdf/files/CD00003136.pdf/jcr:content/translations/en.CD0000313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)|ST1480ACDR | | | |Package_SO:SOIC-8_3.9x4.9mm_P1.27mm |
|U9 |1 |BGA824N6 |GPS antenna front end |[Datasheet](https://www.infineon.com/dgdl/Infineon-BGA824N6-DS-v03_00-en.pdf?fileId=db3a30433f764301013f7b53cdd02721) | |GPS antenna front end* | | |TubeClock:TSNP-6-2_1.2x0.8mm |
|Y1 |1 |8 MHz | |[Datasheet](http://www.abracon.com/Resonators/abm3b.pdf) |ABM3B-8.000MHZ-10-1UT| | | |Crystal:Crystal_SMD_5032-4Pin_5.0x3.2mm |
|Y2 |1 |32.768 KHz | |[Datasheet](https://www.ecsxtal.com/store/pdf/ECX-.327-CDX-1293.pdf) |ECX-.327-CDX-1293 |Not required if DS3234 (U5) is installed | | |Crystal:Crystal_SMD_3215-2Pin_3.2x1.5mm |

## Notes

*Parts flagged with a `*` are optional based on desired GPS configuration

**Carefully check polarity when installing -- the silkscreen on the board may be reversed!

Capacitors `C1`, `C5`, `C6` and `C8` must be rated for 16 to 25 volts! Other capacitors may be rated for 6.3 to 10 volts unless otherwise noted.

## Additional recommended items

* The [Adafruit Ultimate GPS Module](https://www.adafruit.com/product/746) may be used as an easy "plug and go" alternative to the `LIV3F` solder-on GPS module (and related components). This makes assembly quicker and easier for folks who do not wish to contend with the tiny 0402 parts necessary (only four are required!) to accommodate the GPS antenna front end required for the LIV3F module. **See the [TubeClock.GPS.md](TubeClock.GPS.md) file for more detail.**
* Any GPS module will require an antenna. Active antennas will yield the best performance (and might even work indoors!). Adafruit's [GPS antenna](https://www.adafruit.com/product/960) and the `Taoglas AA.162.301111` both work very well with either suggested module. A [u.FL to SMA adapter](https://www.adafruit.com/product/851) cable will be necessary to use either of these. If the LNA, SAW filter and related components are installed, it is possible to use a passive antenna; a DC blocker is recommended in this case.
* For infrared (IR) remote control, the [Adafruit Mini Remote Control](https://www.adafruit.com/product/389) is recommended. Other remotes may be used, however it may be necessary to modify the source code to accommodate them. `U4` might also need to be replaced if different modulation is used.

## Are you shopping?

I've created an [Octopart](https://www.octopart.com) BoM [here](https://octopart.com/bom-tool/HoR7eT6U)!

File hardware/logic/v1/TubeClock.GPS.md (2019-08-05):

# Tube Clock Logic Board GPS Build Guide

## Why GPS on a clock?

While explaining how GPS works is a bit outside of the scope of this document,
 it should suffice to say that, due to how it works, the GPS is an extremely
 accurate source of time. See this
 [brief article](http://www.physics.org/article-questions.asp?id=55) for a bit
 more detail. If nothing else, it allows your clock to set itself!

## Build Options

The tube clock logic board and application have the ability to decode NMEA
 messages sent into the USART1 serial interface. There are three possible ways
 to accomplish this:
1. Connect an external GPS module/device to the six-pin serial interface. Note
   that the USART1 receive line on the STM32's PA10 pin is a 5-volt tolerant
   pin. Therefore, the connected GPS device may output a 5-volt maximum signal.
   **Do not connect a device that outputs an RS-232-level signal!**
1. Connect the [Adafruit Ultimate GPS Module](https://www.adafruit.com/product/746)
   to the pin header on `J7`. This is arguably the easiest path.
1. Install the Teseo LIV3F module on the `U10` footprint.

## Which GPS option is right for me?

For most builders, the determining factor will be their ability to work with
 extremely tiny parts (the ones you need a microscope for). If this isn't for
 you, the [Adafruit Ultimate GPS Module](https://www.adafruit.com/product/746)
 is likely the best approach.

For builders with appropriate tooling, experience, and willingness, (or perhaps
 you're feeling a little crazy and just want to try your hand at these super
 small parts) the on-board LIV3F module is a less expensive approach. There are
 two possible build configurations when using the LIV3F module:
1. Active antenna only: this requires four 0402-sized surface mount parts to be
   soldered onto the underside of the logic board -- one capacitor, one
   inductor, and two zero-ohm jumpers. As these are not polarity-sensitive
   parts, placing them and soldering them is a bit easier. Still, the process is
   more tedious than it is with the larger parts on the top side of the board.
1. Active or passive antenna support: this requires a full suite of components
   on the underside of the board, including a LNA and a SAW filter. The LNA and
   SAW filter are more challenging to place as they have multiple pins and must
   be oriented correctly. A microscope of some sort will be required to identify
   the pin-1 marking on the LNA. Ideally testing equipment is also available to
   confirm its operation after soldering, although continuity testing is likely
   sufficient.

## What parts are necessary on the BoM for my chosen GPS configuration?

### For the Adafruit Ultimate GPS module

None of the parts flagged as "GPS" on the BoM are necessary. Only the pin header
 for `J7` is required so that the module may be plugged in. These parts are:
 `J8`, `C33` through `C43`, `L2`, `L3`, `U9`, `U10`, `U11`, `FL1`, and `R30`
 through `R33`. Do not install these if using this module.

### For the LIV3F module with active antenna support only

Only the following parts are required: `J8`, `C34`, `C42`, `C43`, `L2`, `U10`,
 `U11`, and `R30` through `R33`.

### For the LIV3F module with active or passive antenna support

The following parts are all required: `J8`, `C33` through `C43`, `L2`, `L3`,
 `U9`, `U10`, `U11`, `FL1`, and `R30` through `R33`.

## Anything else I should know?

A word of caution for those who wish to use the LIV3F module with active and
 passive antenna support: The LNA and SAW filter have pins that are *under* the
 device (somewhat similar to a BGA-style package). They simply cannot be
 soldered with a soldering pencil. Soldering them will require either a hot-air
 soldering station or a reflow oven.

While the tiny parts are challenging to work with, it's quite satisfying to see
 them operating after completing the build. They're so tiny! The end result is
 quite pleasing and worth the effort, if you dare!

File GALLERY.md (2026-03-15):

# kbx's Tube Clock — Gallery



## PCBs/Assembly

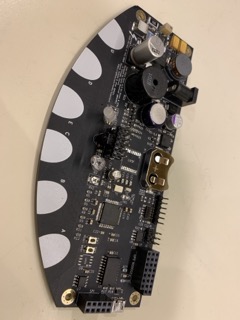
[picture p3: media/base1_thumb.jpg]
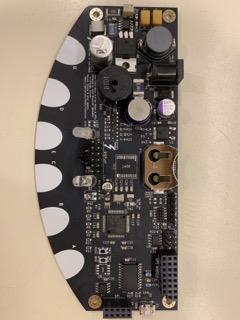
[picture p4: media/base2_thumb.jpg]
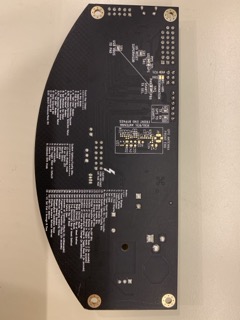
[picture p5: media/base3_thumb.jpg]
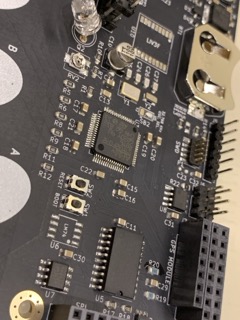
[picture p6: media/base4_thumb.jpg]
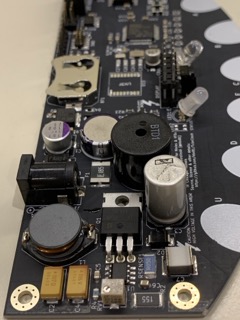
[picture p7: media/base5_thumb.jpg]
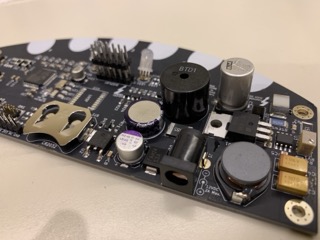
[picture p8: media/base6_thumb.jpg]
     

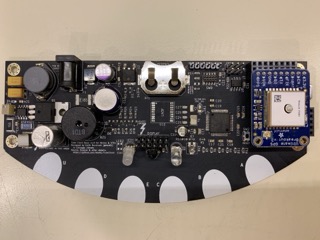
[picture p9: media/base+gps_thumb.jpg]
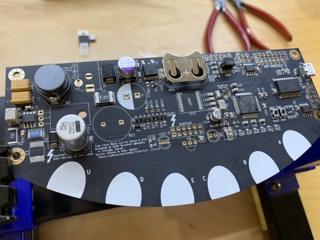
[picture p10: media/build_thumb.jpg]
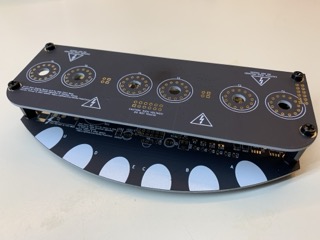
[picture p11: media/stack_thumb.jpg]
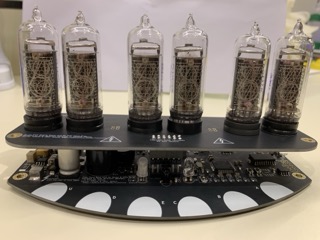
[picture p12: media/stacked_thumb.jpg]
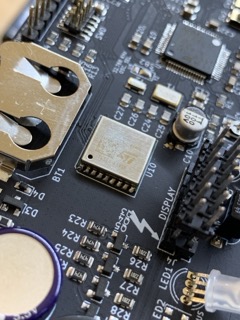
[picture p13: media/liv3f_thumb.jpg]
    

## PCBs

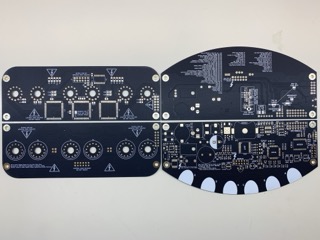
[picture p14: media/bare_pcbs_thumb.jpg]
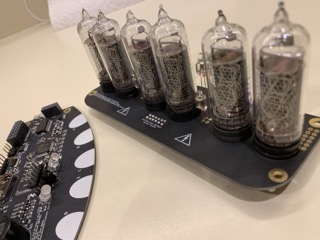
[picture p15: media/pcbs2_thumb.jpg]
 

## IN-12 Tubes

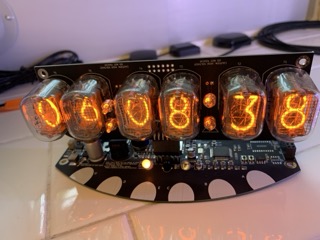
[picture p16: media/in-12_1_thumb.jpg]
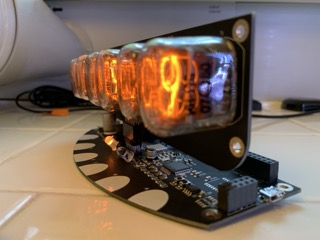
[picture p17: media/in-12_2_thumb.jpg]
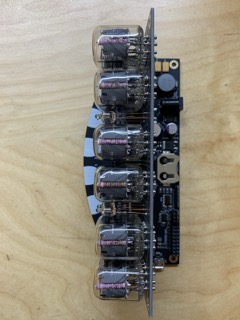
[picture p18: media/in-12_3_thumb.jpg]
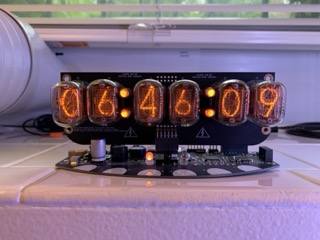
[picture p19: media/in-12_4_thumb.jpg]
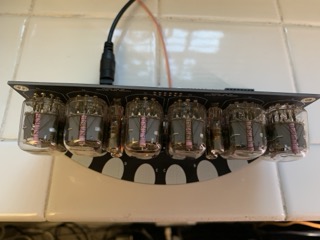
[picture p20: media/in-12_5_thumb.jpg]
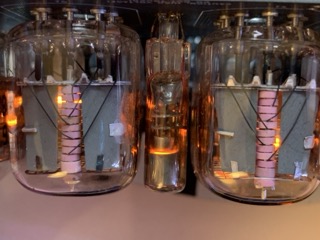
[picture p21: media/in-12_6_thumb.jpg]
     

## IN-14 Tubes

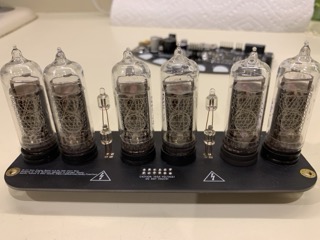
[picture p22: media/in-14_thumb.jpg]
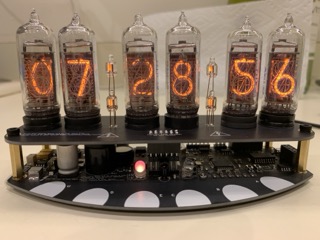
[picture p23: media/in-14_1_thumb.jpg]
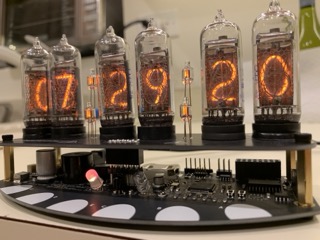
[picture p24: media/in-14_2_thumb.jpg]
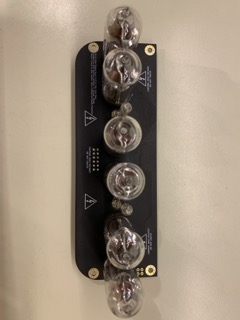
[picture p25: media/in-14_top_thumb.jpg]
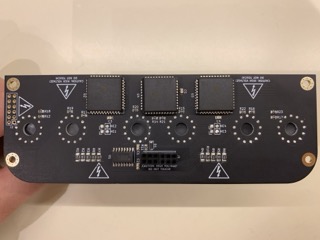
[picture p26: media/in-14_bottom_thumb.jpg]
     

## IN-18 Tubes

 

## Features



  



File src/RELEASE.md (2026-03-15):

# Release Process

## Versioning

Releases use calendar-based versioning: `YY.MM.patch`

- **Major** — 2-digit year (e.g. `26`)
- **Minor** — month, no leading zero (e.g. `3` for March)
- **Patch** — sequential release within the month, starting at `1`

Version is defined in [src/v1/version.h](src/v1/version.h).

## Cutting a Release

1. **Update the version** in `src/v1/version.h` if needed (bump `FIRMWARE_VERSION_PATCH`, or major/minor for a new month/year).

2. **Commit any outstanding changes** — the release script requires a clean working tree.

3. **Run the release script** from the project root:
   ```
   ./scripts/release.sh
   ```
   The script will:
   - Build all four profiles cleanly (`make clean && make PROFILE=N`)
   - Copy the `.bin` files into `releases/<version>/`
   - Create a git commit and tag

4. **Review the output** in `releases/<version>/`:
   | File | Profile |
   |------|---------|
   | `TubeClock-<version>-us.bin` | 0 — US/North America (12h, °F, DST) |
   | `TubeClock-<version>-eu.bin` | 1 — European (24h, °C, no DST) |
   | `TubeClock-<version>-minimal.bin` | 2 — Minimal (silent, basic display) |
   | `TubeClock-<version>-kbx.bin` | 3 — kbx preferred |

5. **Push** the commit and tag:
   ```
   git push && git push --tags
   ```

## Flashing

Flash the appropriate `.bin` to the STM32F072 using your preferred SWD/JTAG tool. For example:

```
st-flash write releases/<version>/TubeClock-<version>-us.bin 0x08000000
```

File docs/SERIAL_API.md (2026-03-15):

# Serial Remote Control API

This document describes the serial protocol used to monitor and control the TubeClock from an external microcontroller (for example, ESP32 or RP2040). The interface enables remote access to all major clock functions: display mode selection, time/date, temperature, intensity, settings, hardware status, and key events.

## Physical Layer

| Parameter | Value |
|---|---|
| Baud rate | 115200 |
| Data bits | 8 |
| Parity | None |
| Stop bits | 1 |
| Logic level | 3.3V |

### USART Channels

The clock uses three USARTs for the serial remote interface:

| USART | Direction | Pin | Notes |
|---|---|-----|---|
| USART1 | TX + RX | TX: PB6, RX: PA10 | Shared with GPS. GPS uses `$GP` prefix; serial remote uses `$TC`. Both parsers operate independently on every received byte. |
| USART3 | RX only | PB10 | Dedicated serial remote input. Uses `USART_CR2_SWAP` (PB10 is normally a TX pin but is hardware-swapped to function as RX). |
| USART4 | TX only | PA0 | Dedicated serial remote output. |

**Recommended wiring:** Connect the external MCU's TX to USART3 RX (PB10) and the external MCU's RX to USART4 TX (PA0). This avoids contention with GPS traffic on USART1. USART1 may also be used for bidirectional communication if GPS is not connected.

All responses are transmitted simultaneously on both USART1 TX and USART4 TX.

## Protocol Format

The protocol uses NMEA-style ASCII sentences:

```
$TC{C|S}<category><action>[<data>]*XX\n
```

| Field | Description |
|---|---|
| `$TC` | Protocol header (4 bytes including direction) |
| `C` | **Command** -- external MCU to clock |
| `S` | **Status** -- clock to external MCU (solicited response or unsolicited notification) |
| `<category>` | Single character identifying the command category |
| `<action>` | Category-specific action and data |
| `*` | Checksum delimiter |
| `XX` | XOR checksum as two uppercase hex digits |
| `\n` | Sentence terminator (newline, 0x0A) |

### Checksum Calculation

The checksum is the XOR of all bytes between `$` (exclusive) and `*` (exclusive). For example, for the sentence `$TCCP*XX\n`, the checksum covers the bytes `T`, `C`, `C`, `P`.

```
checksum = 'T' ^ 'C' ^ 'C' ^ 'P'
         = 0x54 ^ 0x43 ^ 0x43 ^ 0x50
         = 0x54 ^ 0x50       (0x43 ^ 0x43 = 0x00)
         = 0x04
```

Result: `$TCCP*04\n`

Sentences received without a checksum (terminated by `\n` before `*`) are also accepted.

### Error Responses

When a `$TC` command is received but the category character is not recognized, or the payload is too short to parse, the clock sends an error response:

```
$TCSE<category>*XX\n
```

where `<category>` is the unrecognized category character echoed back. If the payload is too short to contain a category, `?` is used instead.

Examples:
```
-> $TCCZTEST*XX\n      (unknown category 'Z')
<- $TCSE Z*XX\n

-> $TCC*XX\n           (payload too short)
<- $TCSE?*XX\n
```

If a checksum is present but does not match, the clock sends a checksum error response:

```
$TCSECHK*XX\n
```

Malformed headers and other framing errors are silently discarded with no response.

### Numeric Values

All numeric values in commands and responses are decimal ASCII. Leading zeros may be present in fixed-width fields (for example, time: `093015` for 09:30:15). Negative values are prefixed with `-`.

## Command Reference

### P -- Page/Mode

Controls the clock's current display mode (operating mode) and optional sub-page (view mode).

#### Get Current Page

```
-> $TCCP*04\n
<- $TCSP1*42\n
```

The response includes the current operating mode number. If the view mode (sub-page) is non-zero, it is appended:

```
<- $TCSP8P2*XX\n     (page 8, sub-page 2)
```

#### Set Page

```
-> $TCCP3*XX\n        (switch to page 3)
<- $TCSP3*XX\n        (confirmation)
```

#### Set Page with Sub-Page

```
-> $TCCP8P1*XX\n      (switch to page 8, sub-page 1)
<- $TCSP8P1*XX\n      (confirmation)
```

#### Operating Mode Values

| Value | Mode | Description |
|---|---|---|
| 0 | MainMenu | Main menu navigation |
| 1 | FixedDisplay | Fixed time/date/temp display |
| 2 | ToggleDisplay | Auto-toggling display |
| 3 | TimerCounter | Timer/counter |
| 4 | Dmx512Display | DMX-512 controlled display |
| 5 | SetClock | Set time |
| 6 | SetDate | Set date |
| 7 | SetTimerResetValue | Set timer reset value |
| 8 | SystemStatusView | System status/diagnostics |
| 9 | SetSystemOptions | System options (binary flags) |
| 10 | SlotBeepConfig | Per-slot beep enable/disable |
| 11 | SlotBlinkConfig | Per-slot blink enable/disable |
| 12 | SlotOnOffConfig | Per-slot color change enable/disable |
| 13 | SlotPMIndicatorRGBConfig | PM indicator LED RGB color |
| 14 | SetDurationClock | Clock display duration |
| 15 | SetDurationDate | Date display duration |
| 16 | SetDurationTemp | Temperature display duration |
| 17 | SetDurationFade | Digit fade duration |
| 18 | DstBeginMonth | DST start month |
| 19 | DstBeginDowOrdinal | DST start day ordinal |
| 20 | DstEndMonth | DST end month |
| 21 | DstEndDowOrdinal | DST end day ordinal |
| 22 | DstSwitchDayOfWeek | DST switch day of week |
| 23 | DstSwitchHour | DST switch hour |
| 24 | SetEffectDuration | Display effect duration |
| 25 | SetEffectFrequency | Display effect frequency |
| 26 | SetMinimumIntensity | Minimum display intensity |
| 27 | SetBeeperVolume | Beeper volume |
| 28 | SetTempCalibration | Temperature calibration |
| 29 | SetIdleTimeout | Idle timeout |
| 30 | SetDateFormat | Date format |
| 31 | SetTimeZone | Time zone |
| 32 | SetColonBehavior | Colon/separator behavior |
| 33 | SetDMX512Address | DMX-512 address |
| 34-41 | Slot1Time-Slot8Time | Set slot 1-8 time |

#### View Mode (Sub-Page) Values

| Value | Mode |
|---|---|
| 0 | ViewMode0 (default) |
| 1 | ViewMode1 |
| 2 | ViewMode2 |
| 3 | ViewMode3 |
| 4 | ViewMode4 |
| 5 | ViewMode5 |
| 6 | ViewMode6 |
| 7 | ViewMode7 |
| 8 | ViewMode8 |
| 9 | ViewMode9 |

The meaning of each view mode is context-dependent on the active operating mode.

---

### K -- Keys

Queries the current state of the capacitive touch keys.

#### Get Key State

```
-> $TCCK*XX\n
<- $TCSK<bitmask>*XX\n
```

The response is a decimal bitmask of currently pressed keys:

| Bit | Key |
|-----|-----|
| 0 (1) | U (Up) |
| 1 (2) | D (Down) |
| 2 (4) | E (Enter/Exit) |
| 3 (8) | C |
| 4 (16) | B |
| 5 (32) | A |

Example: `$TCSK5*XX\n` means keys U (1) and E (4) are pressed simultaneously.

A response of `$TCSK0*XX\n` means no keys are pressed.

---

### H -- Hardware

Hardware status queries and control.

#### Get ADC Data

```
-> $TCCHADC*XX\n
<- $TCSHADC<light>,<vdda>,<vbatt>*XX\n
```

Returns three comma-separated decimal values:
- **light**: Ambient light level (raw ADC, phototransistor)
- **vdda**: VddA supply voltage in millivolts
- **vbatt**: Battery voltage in millivolts

Example: `$TCSHADC1782,3300,2791*XX\n`

This response is also sent as an **unsolicited status notification** whenever a new ADC reading is obtained and at least one value has changed. See [ADC Update](#adc-update) in the Unsolicited Notifications section.

#### Get Connected Components

```
-> $TCCHCON*XX\n
<- $TCSHCON<bitmask>*XX\n
```

Returns a decimal bitmask of detected hardware:

| Bit | Component |
|-----|---|
| 0 (1) | DS3234 temperature sensor |
| 1 (2) | DS1722 temperature sensor |
| 2 (4) | LM74 temperature sensor |
| 3 (8) | GPS connected |
| 4 (16) | GPS fix valid |

Example: `$TCSHCON24*XX\n` means GPS connected (8) + GPS valid (16).

#### Get HV State

```
-> $TCCHV*XX\n
<- $TCSHV<0|1>*XX\n
```

Returns the current state of the high-voltage supply: `1` = enabled, `0` = disabled.

#### HV Power On

```
-> $TCCHVON*XX\n
<- $TCSHV1*XX\n
```

Enables the high-voltage supply for the Nixie tubes.

#### HV Power Off

```
-> $TCCHVOF*XX\n
<- $TCSHV0*XX\n
```

Disables the high-voltage supply for the Nixie tubes.

#### Bootloader Control

```
-> $TCCHBOOT0*XX\n      Disable: clear bootloader-on-next-boot flag
-> $TCCHBOOT1*XX\n      Enable:  set flag; bootloader runs on next reset
-> $TCCHBOOT2*XX\n      Enter:   set flag then reset immediately

<- $TCSHBOOT0*XX\n
<- $TCSHBOOT1*XX\n
<- $TCSHBOOT2*XX\n      (ACK sent before reset fires)
```

Controls entry into the STM32F072 factory bootloader. The clock may be
re-flashed via USART1 (PA9 TX / PA10 RX) or USART2 (PA14 TX / PA15 RX)
using the standard STM32 bootloader protocol.

- **BOOT0** clears the bootloader flag, cancelling a previously armed BOOT1.
- **BOOT1** arms the flag. The clock operates normally until the next reset (for example,
  via the external MCU asserting NRST), at which point it jumps to the bootloader
  instead of running the application.
- **BOOT2** arms the flag and triggers a system reset immediately after the ACK
  is transmitted. Equivalent to BOOT1 followed by a NRST pulse.

Normal operation resumes on the next power cycle or reset with BOOT0 low.

---

### T -- Time

Get or set the current date and time.

#### Get Time

```
-> $TCCT*XX\n
<- $TCST<HHMMSSYYYYMMDD>*XX\n
```

Returns 14 digits: hours (2), minutes (2), seconds (2), year (4), month (2), day (2).

Example: `$TCST234520260211*XX\n` = 23:45:20 on 2026-02-11.

#### Set Time

```
-> $TCCT<HHMMSSYYYYMMDD>*XX\n
<- $TCST<HHMMSSYYYYMMDD>*XX\n
```

Sets the clock to the specified time and date. The response confirms the new time.

Example: `$TCCT120000202602120A*XX\n` sets the time to 12:00:00 on 2026-02-12.

The payload must contain exactly 14 digits starting at the data position:
- `HH` -- Hours (00-23)
- `MM` -- Minutes (00-59)
- `SS` -- Seconds (00-59)
- `YYYY` -- Year (for example, 2026)
- `MM` -- Month (01-12)
- `DD` -- Day (01-31)

---

### M -- Temperature

Get or set the current temperature. Responses include a value for every sensor type.

#### Get Temperature

```
-> $TCCM*XX\n
<- $TCSM<adc>,<ds3234>,<ds1722>,<lm74>,<external>*XX\n
```

Returns temperatures from all sensor types as comma-separated signed decimal integers in **tenths of degrees Celsius** (Celsius x10). The fields correspond to the `TempSensorType` enum values in order:

| Index | Sensor | Notes |
|---|---|---|
| 0 | STM32ADC | STM32 internal ADC temperature (always present) |
| 1 | DS3234 | DS3234 RTC integrated temperature sensor |
| 2 | DS1722 | External DS1722 SPI temperature sensor |
| 3 | LM74 | External LM74 SPI temperature sensor |
| 4 | ExternalSerial | Externally set via Set Temperature command |

Undetected or unavailable sensors report `32767` (sentinel value).

Example: `$TCSM235,237,32767,32767,32767*XX\n` (internal ADC reads 23.5°C, DS3234 reads 23.7°C, no other sensors detected).

This response is also sent as an **unsolicited status notification** whenever a new temperature reading is obtained from hardware.

#### Set Temperature

```
-> $TCCM<value>*XX\n
<- $TCSM<adc>,<ds3234>,<ds1722>,<lm74>,<external>*XX\n
```

Sets the temperature from an external source. The value is in **tenths of degrees Celsius** (Celsius x10, signed). Once set, this external value takes precedence over all auto-detected hardware temperature sensors (DS1722, LM74, DS3234, STM32 internal ADC) and persists until changed or until reboot.

The response returns all sensor values in the same format as Get Temperature.

Examples:
- `$TCCM235*XX\n` sets temperature to 23.5°C
- `$TCCM-50*XX\n` sets temperature to -5.0°C

Setting a temperature value automatically sets the temperature source to `ExternalSerial` (4).

#### Get Temperature Source

```
-> $TCCMS*XX\n
<- $TCSMS<n>*XX\n
```

Returns the active temperature sensor type as a decimal integer (see table below).

Example: `$TCSMS4*XX\n` (ExternalSerial is the active source).

#### Set Temperature Source

```
-> $TCCMS<n>*XX\n
<- $TCSMS<n>*XX\n       (success)
<- $TCSMSE*XX\n          (error: sensor not available)
```

Selects the temperature source. If the requested sensor was not detected at startup, an error response is returned and the source is not changed.

Example: `$TCCMS0*XX\n` switches to the internal STM32 ADC.

#### Temperature Source Values

| Value | Source | Notes |
|---|---|---|
| 0 | Internal STM32 ADC | Always available |
| 1 | DS3234 | Available if DS3234 RTC is connected |
| 2 | DS1722 | Available if detected at startup |
| 3 | LM74 | Available if detected at startup |
| 4 | ExternalSerial | Always available; temperature set via M command |

---

### L -- Status LED

Get or set the RGB status LED color, intensity, gamma mode, and auto-brightness state. Color values are 0–255 per channel; internally the LED uses 12-bit resolution (0–4095), so the serial interface scales by a factor of 16 in each direction. Intensity is 0–255. The LED has its own auto-brightness flag, independent of the nixie tube auto-brightness (see [I -- Intensity](#i----intensity)).

#### Get LED State

```
-> $TCCL*XX\n
<- $TCSL<i>,<r>,<g>,<b>,<gamma>,<auto>*XX\n
```

Returns six comma-separated values:
- **i**: LED intensity (0–255)
- **r**, **g**, **b**: Red, green, blue channel values (0–255 each)
- **gamma**: Gamma correction mode — `1` = firmware applies gamma correction; `0` = values are already gamma-corrected (correction skipped)
- **auto**: LED auto-adjust enabled (`1`) or disabled (`0`)

Example: `$TCSL128,255,0,0,1,0*XX\n` (red LED at intensity 128, gamma correction on, auto-adjust off).

#### Set LED State

```
-> $TCCL<i>,<r>,<g>,<b>[,<gamma>[,<auto>]]*XX\n
<- $TCSL<i>,<r>,<g>,<b>,<gamma>,<auto>*XX\n
```

Sets the LED intensity and color. The optional `<gamma>` field (`0` or `1`) controls whether the firmware applies gamma correction to the received values. The optional trailing `<auto>` field (`0` or `1`) sets the LED auto-brightness flag. The response confirms the new state.

- `gamma=1` (default when omitted): color values are linear; the firmware applies `gammaCorrect12bit()` during rendering for perceptually linear brightness.
- `gamma=0`: color values are already gamma-corrected; the firmware skips its internal gamma correction step. Use this when your controller has pre-applied gamma (for example, from a lighting control system).

**Note:** The gamma flag applies only to the values in this command. Any subsequent write to the LED — from an internal view or a new TCCL command — resets to `gamma=1` (apply correction) unless explicitly specified otherwise.

Example: `$TCCL255,255,128,0*XX\n` sets the LED to orange at full intensity (gamma applied by firmware).
Example: `$TCCL200,186,0,0,0*XX\n` sets the LED to red at intensity 200 with pre-corrected values (firmware skips gamma).
Example: `$TCCL50,0,255,0,1,1*XX\n` sets the LED to green at intensity 50, gamma on, auto-adjust enabled.

**Note:** Setting the LED intensity with this command disables LED auto-adjust (unless the optional `<auto>` field is included and set to `1`). Tube auto-adjust is not affected.

**Breaking change:** The `<auto>` field has shifted from position 5 to position 6. Senders using the old `$TCCL<i>,<r>,<g>,<b>,<auto>` form must insert the `<gamma>` field before `<auto>`.

#### Set LED Auto-Adjust

```
-> $TCCLA<0|1>*XX\n
<- $TCSL<i>,<r>,<g>,<b>,<gamma>,<auto>*XX\n
```

Enables (`1`) or disables (`0`) automatic LED intensity adjustment based on ambient light. This flag is independent of tube auto-adjust (`$TCCIA`). The response reports the current LED state.

Example: `$TCCLA1*XX\n` enables LED auto-adjust.

**Note:** When LED auto-adjust is enabled, the LED intensity tracks the nixie tube intensity as the ambient light changes. When the AM/PM indicator feature is enabled (`StatusLedAsAmPm` system option), the clock manages LED auto-adjust automatically: it is enabled during PM time and disabled when the indicator is off (AM or non-time display), preventing auto-brightness from turning the LED on when it should be off.

**Note:** The LED color and intensity set via this command persist until a view that manages the LED internally changes the color (for example, a PM indicator transition in `TimeDateTempView`, or entering `MainMenuView`).

This response is also sent as an **unsolicited status notification** whenever the LED color, intensity, gamma mode, or auto-adjust state changes from any source (internal views, external commands, or auto-brightness).

---

### B -- Buzzer (RTTTL Playback)

Play, stop, or query RTTTL (Ring Tone Text Transfer Language) melodies through the clock's buzzer.

[RTTTL format](https://en.wikipedia.org/wiki/Ring_Tone_Transfer_Language): `Name:d=<dur>,o=<oct>,b=<bpm>:<notes>`

| Field | Description |
|---|---|
| `Name` | Song name (up to ~15 characters, ignored during playback) |
| `d=` | Default note duration: 1=whole, 2=half, 4=quarter, 8=eighth, 16=sixteenth, 32=thirty-second |
| `o=` | Default octave (4–7) |
| `b=` | BPM (beats per minute, in quarter notes) |
| notes | Comma-separated sequence of `[dur][note][#][oct][.]` |

Note characters: `c`, `d`, `e`, `f`, `g`, `a`, `b` (or `h`), `p` (pause). Append `#` for sharp, a digit for octave override, `.` for dotted (50% longer).

#### Play RTTTL

```
-> $TCCBPName:d=4,o=5,b=120:4e,4d,4c*XX\n
<- $TCSBP*XX\n
```

The RTTTL string begins immediately after the `P` action character. The response reports current playback status: `P` (playing) or `S` (stopped). If playback is already in progress, it is interrupted and the new song starts immediately.

Maximum RTTTL string length: 251 bytes (within the 255-byte payload limit, minus the 3-byte `CBP` prefix).

Example: play two notes (E and C in octave 5 at 120 BPM):
```
-> $TCCBPTwo:d=4,o=5,b=120:e,c*XX\n
<- $TCSBP*XX\n
```

#### Stop Playback

```
-> $TCCBS*XX\n
<- $TCSBS*XX\n
```

Stops RTTTL playback immediately. The current note (already in the hardware tone queue) may finish playing. The response reports `S` (stopped).

#### Play Hourly Chime

```
-> $TCCBC*XX\n           (play chime for current displayed hour)
-> $TCCBC<hh>*XX\n       (play chime for hour hh, 0–23)
<- $TCSBP*XX\n
```

Plays the hourly chime melody. With no argument, uses the current displayed hour — identical to the chime that fires automatically at the top of each hour. With an explicit `hh` argument (0–23), encodes that hour as the chime; the 12-hour display setting is applied when active (for example, `0` → 12, `13` → 1).

The chime encodes the hour as a binary sequence of beeps (LSb first): a low note for a 0-bit and a high note for a 1-bit, with 16th-note rests between notes. Hour 0 produces a single low beep.

If playback is already in progress, it is interrupted and the chime starts immediately. The response reports current buzzer playback status (same as [Query Status](#query-status)).

#### Query Status

```
-> $TCCBQ*XX\n
<- $TCSB<status>*XX\n
```

Returns the current playback status: `P` (playing) or `S` (stopped).

#### RTTTL Playback Complete Notification

```
<- $TCSBOK*XX\n
```

Sent as an unsolicited notification when RTTTL playback completes. This fires when the last note has been accepted into the hardware tone queue; the final note(s) may still be audible for a short time after the notification is received.

---

### I -- Intensity

Get or set the nixie tube display brightness. The status LED has its own independent intensity and auto-brightness flag, both controlled via the [L -- Status LED](#l----status-led) command.

#### Get Intensity

```
-> $TCCI*XX\n
<- $TCSI<intensity>,<auto>*XX\n
```

Returns two comma-separated values:
- **intensity**: Current brightness level (0-255)
- **auto**: Auto-adjust enabled (`1`) or disabled (`0`)

Example: `$TCSI128,1*XX\n` = intensity 128, auto-adjust on.

#### Set Intensity

```
-> $TCCI<nnn>*XX\n
<- $TCSI<intensity>,<auto>*XX\n
```

Sets the display intensity to `nnn` (0-255). The response confirms the new state.

Example: `$TCCI200*XX\n` sets intensity to 200.

**Note:** Setting intensity with this command disables automatic brightness adjustment (`auto` will be `0` in the response). Use `$TCCIA1*XX\n` to re-enable it.

#### Set Auto-Adjust

```
-> $TCCIA<0|1>*XX\n
<- $TCSI<intensity>,<auto>*XX\n
```

Enables (`1`) or disables (`0`) automatic intensity adjustment based on ambient light.

Example: `$TCCIA1*XX\n` enables auto-adjust.

**Note:** `$TCCIA` controls tube auto-adjust only. For LED auto-adjust, use `$TCCLA`. When tube auto-adjust is active and the intensity changes automatically, an unsolicited `$TCSI` notification is sent. See [Intensity Change](#intensity-change) in the Unsolicited Notifications section.

---

### S -- Settings

Get or set individual clock settings by index number.

#### Get Setting

```
-> $TCCS<nn>*XX\n
<- $TCSS<nn>,<value>*XX\n
```

Returns the current value of setting `nn`.

Example: `$TCCS10*XX\n` queries setting 10 (FadeDuration); response: `$TCSS10,500*XX\n`.

#### Set Setting

```
-> $TCCS<nn>,<value>*XX\n
<- $TCSS<nn>,<value>*XX\n
```

Sets setting `nn` to `value` (unsigned 16-bit integer). The response confirms the new value. After setting a value, the clock's active settings are refreshed immediately.

Example: `$TCCS20,5*XX\n` sets BeeperVolume (20) to 5.

**Note:** Set Setting updates the in-memory settings only. Use Save Settings to persist changes across power cycles.

#### Save Settings

```
-> $TCCSW*XX\n
<- $TCSSW<result>*XX\n
```

Saves the current in-memory settings to flash. To prevent unnecessary flash wear, the write is skipped if the in-memory settings are identical to the copy already stored in flash (compared by CRC).

- **result**: `1` = saved successfully (or already up to date), `0` = flash write error

Example: `$TCSSW1*XX\n` — settings saved (or unchanged).

#### Erase Settings (Factory Reset)

```
-> $TCCSERASE*XX\n
<- $TCSSERASE<result>*XX\n
```

Erases the settings flash area, removing all user preferences. On the next reboot the clock will load factory defaults.

- **result**: `1` = erased successfully, `0` = erase error

**Note:** The in-memory settings are not modified by this command. The clock continues running with its current in-memory settings until restarted. To apply factory defaults immediately, reset the clock.

Example: `$TCSSERASE1*XX\n` — settings flash erased.

#### Setting Index Reference

| Index | Setting | Description |
|---|---|---|
| 0 | SystemOptions | Bitfield of system option flags (see below) |
| 1 | BeepStates | Per-slot beep enable bitmask |
| 2 | BlinkStates | Per-slot blink enable bitmask |
| 3 | OnOffStates | Per-slot on/off enable bitmask |
| 4 | PMIndicatorRedValue | PM indicator LED red channel (0–4095) |
| 5 | PMIndicatorGreenValue | PM indicator LED green channel (0–4095) |
| 6 | PMIndicatorBlueValue | PM indicator LED blue channel (0–4095) |
| 7 | TimeDisplayDuration | Duration of time display (toggle mode) |
| 8 | DateDisplayDuration | Duration of date display (toggle mode) |
| 9 | TemperatureDisplayDuration | Duration of temperature display (toggle mode) |
| 10 | FadeDuration | Digit crossfade duration |
| 11 | DstBeginMonth | DST start month |
| 12 | DstBeginDowOrdinal | DST start day-of-week ordinal |
| 13 | DstEndMonth | DST end month |
| 14 | DstEndDowOrdinal | DST end day-of-week ordinal |
| 15 | DstSwitchDayOfWeek | DST switch day of week |
| 16 | DstSwitchHour | DST switch hour |
| 17 | EffectDuration | Display effect duration |
| 18 | EffectFrequency | Display effect frequency |
| 19 | MinimumIntensity | Minimum display intensity |
| 20 | BeeperVolume | Beeper volume |
| 21 | TemperatureCalibrationSTM32 | Temperature calibration offset (STM32 internal ADC) |
| 22 | TemperatureCalibrationDS3234 | Temperature calibration offset (DS3234) |
| 23 | TemperatureCalibrationDS1722 | Temperature calibration offset (DS1722) |
| 24 | TemperatureCalibrationLM74 | Temperature calibration offset (LM74) |
| 25 | IdleTimeout | Idle timeout (seconds, 10–600) |
| 26 | DateFormat | Date format |
| 27 | TimeZone | Time zone offset |
| 28 | ColonBehavior | Colon/separator behavior during time display |
| 29 | TimerResetValue | Timer/counter reset value |
| 30 | DmxAddress | DMX-512 base address |

#### SystemOptions Bit Flags (Setting 0)

| Bit | Flag | Description |
|-----|---|---|
| 0 | Display12Hour | 12-hour time format |
| 1 | StatusLedAsAmPm | Use status LED for AM/PM indication |
| 2 | HourlyChime | Enable hourly chime |
| 3 | DstEnable | Enable automatic DST adjustment |
| 4 | DisplayFahrenheit | Display temperature in Fahrenheit |
| 5 | AutoAdjustIntensity | Enable auto brightness adjustment |
| 6 | StartupToToggle | Boot into toggle display mode |
| 7 | DmxExtended | DMX-512 extended mode |
| 8 | MSDsOff | Turn off most-significant digits when zero |
| 9 | TriggerEffectOnRotate | Trigger display effect on time/date/temperature toggling |

---

### A -- Alarm Slot Time

Get or set the time for alarm slots 1–8. These are the time-of-day triggers used by `AlarmHandler`. Only the time portion (HH, MM, SS) is stored; the date is ignored during alarm comparison.

#### Get Alarm Slot Time

```
-> $TCCA<n>*XX\n
<- $TCSA<n>,<HHMMSS>*XX\n
```

Returns the current alarm time for slot `n` (1–8) as 6 digits.

Example: `$TCCA1*XX\n` → `$TCSA1,013000*XX\n` (slot 1 set to 01:30:00)

#### Set Alarm Slot Time

```
-> $TCCA<n>,<HHMMSS>*XX\n
<- $TCSA<n>,<HHMMSS>*XX\n
```

Sets the alarm time for slot `n` (1–8). The response confirms the new value.

- `n`: Slot number, 1–8
- `HH`: Hours (00–23)
- `MM`: Minutes (00–59)
- `SS`: Seconds (00–59)

Invalid slot numbers or out-of-range time values produce no response.

Example: `$TCCA3,083000*XX\n` sets slot 3 to 08:30:00.

**Note:** This command updates in-memory settings only. Use `$TCCSSW*XX\n` to persist changes across power cycles. Whether each slot triggers a beep and/or display blink is controlled by the `BeepStates` (setting 1) and `BlinkStates` (setting 2) bitmasks.

---

### R -- Timer/Counter

Control the timer/counter (operating mode 3: `TimerCounter`). All commands except `RA` (clear alarm) automatically switch to `OperatingModeTimerCounter`.

#### Run Up

```
-> $TCCRU*XX\n
<- $TCSRU,<value>*XX\n
```

Sets count direction to up and starts the timer counting from its current value. The response includes the state character and current timer value (see Response Format below).

#### Run Down

```
-> $TCCRD*XX\n
<- $TCSRD,<value>*XX\n
```

Sets count direction to down and starts the timer counting from its current value.

#### Stop

```
-> $TCCRS*XX\n
<- $TCSRS,<value>*XX\n
```

Pauses the timer at its current value.

#### Reset

```
-> $TCCRR*XX\n
<- $TCSRR,<value>*XX\n
```

Reloads the timer from the `TimerResetValue` setting (index 29): if counting up, resets to 0; if counting down, resets to the setting value. Same behavior as pressing key C. The response state will be `R` briefly (timer is in reset sub-mode), then the view transitions to stopped.

#### Reset to N Seconds

```
-> $TCCRR<seconds>*XX\n
<- $TCSRS,<seconds>*XX\n
```

Loads an arbitrary value `<seconds>` into the timer (range 0–999999) and stops without changing the current count direction. The response state is `S` (stopped).

Example: `$TCCRR30*XX\n` loads 30 into the timer and stops.

#### Clear Alarm

```
-> $TCCRA*XX\n
<- $TCSRA<0|1>*XX\n
```

Clears any active timer/counter alarm. Does **not** change the operating mode. The response value is:
- `1` — alarm was active and has been cleared
- `0` — no alarm was active

#### Response Format

Timer command responses (U/D/S/R actions):

```
$TCSR<state>,<value>*XX\n
```

| Field | Description |
|---|---|
| `<state>` | `U` = running up, `D` = running down, `S` = stopped, `R` = reset (transient) |
| `<value>` | Current timer value as a decimal integer (live at dequeue time) |

Examples:
```
$TCSRU,45*XX\n    (running up, timer at 45)
$TCSRD,30*XX\n    (running down, timer at 30)
$TCSRS,0*XX\n     (stopped at 0)
```

---

### D -- Diagnostics

Read-only queries for system health and identity. These commands return live state at the time the response is sent; none modify any clock state except `DOTR` (on-time reset).

#### Get Firmware Version

```
-> $TCCDF*XX\n
<- $TCSDF<version>,<build>*XX\n
```

Returns the firmware version string and build number. The response fields are identical to those in the `$TCSBOOT` notification sent at startup.

| Field | Type | Description |
|---|---|---|
| `version` | string | Calendar-based version `"YY.MM.PP"` (always 8 characters, zero-padded) |
| `build` | decimal | Monotonically incrementing build counter (uint16) |

Example:
```
-> $TCCDF*5C\n
<- $TCSDF26.03.01,42*XX\n
```

#### Get HV On-Time (Tube Lifetime)

```
-> $TCCDOT*XX\n
<- $TCSDOT<seconds>*XX\n
```

Returns the total number of seconds the HV (high-voltage nixie tube supply) has been active. The counter persists across power cycles via the RTC backup register and DS3234 SRAM (if available). Can be reset with `$TCCDOTR`.

| Field | Type | Description |
|---|---|---|
| `seconds` | decimal | Accumulated HV on-time in seconds (uint32) |

Example:
```
-> $TCCDOT*XX\n
<- $TCSDOT432000*XX\n   (120 hours)
```

#### Reset HV On-Time Counter

```
-> $TCCDOTR*XX\n
<- $TCSDOTR*XX\n
```

Resets the HV on-time counter to zero and acknowledges the reset. This is the same reset triggered by pressing C in the System Status view.

#### Get RTC Info

```
-> $TCCDRTC*XX\n
<- $TCSDRTC<type>,<startResult>*XX\n
```

Returns the active RTC source and the result of RTC initialization at startup.

| Field | Type | Description |
|---|---|---|
| `type` | decimal | Active RTC: `0` = STM32 internal, `1` = DS323x external |
| `startResult` | decimal | Startup result: `0` = UnknownError, `1` = Ok, `2` = OscStopped (reinitialized), `3` = OscTimeout |

Example (DS3234 found, started normally):
```
-> $TCCDRTC*XX\n
<- $TCSDRTC1,1*XX\n
```

#### Get Settings Load Source

```
-> $TCCDS*XX\n
<- $TCSDS<source>*XX\n
```

Returns which source settings were loaded from at the last boot.

| Field | Type | Description |
|---|---|---|
| `source` | decimal | `0` = Compiled-in defaults (no stored settings found), `1` = Flash, `2` = DS3234 SRAM |

Example:
```
-> $TCCDS*XX\n
<- $TCSDS1*XX\n   (loaded from flash)
```

#### Get GPS Status

```
-> $TCCDGPS*XX\n
<- $TCSDGPS<connected>,<valid>,<sats>*XX\n
```

Returns detailed GPS receiver status. `connected` indicates the module is responding (GPRMC sentences received); `valid` indicates an active position fix with a valid date/time. Note: this is a more granular view of the GPS data already partially exposed via `$TCCHCON`.

This response is also sent as an **unsolicited status notification** whenever any GPS status field changes. See [GPS Status Change](#gps-status-change) in the Unsolicited Notifications section.

| Field | Type | Description |
|---|---|---|
| `connected` | `0`/`1` | GPS module is responding (valid or invalid fix character received) |
| `valid` | `0`/`1` | GPS has a valid fix and date/time (`GPRMC` status `A`) |
| `sats` | decimal | Number of satellites currently in view (uint8) |

Example (connected, fix acquired, 8 satellites):
```
-> $TCCDGPS*XX\n
<- $TCSDGPS1,1,8*XX\n
```

---

## Unsolicited Notifications

The clock sends these notifications automatically when state changes occur, without a preceding command. Notifications are buffered in a transmit queue and sent when the TX path becomes idle (after both USART output channels finish transmitting the previous message). Unsolicited notification types are coalesced — at most one pending entry per type is kept in the queue, so only the latest state is sent when the queue drains. Key events are an exception and are never coalesced; each press and release is individually queued. If the queue is full (capacity 8), new entries are silently dropped. The external MCU can always poll for current state if a notification is missed.

### Boot

```
<- $TCSBOOT<version>,<build>*XX\n
```

Sent once immediately after the clock finishes initialization, before any other unsolicited notifications. `<version>` is the firmware version string. Calendar-based versioning is used: `YY.MM.patch` with each field having two-digits, zero-padded when necessary. `<build>` is the monotonically incrementing build counter.

Example: `$TCSBOOT26.03.01,12*XX\n`

---

### Mode Change

```
<- $TCSP<nn>*XX\n
<- $TCSP<nn>P<m>*XX\n     (with non-zero view mode)
```

Sent when the operating mode or view mode changes (for example, user navigates menus, alarm triggers a mode switch).

### Key Event

```
<- $TCSK<bitmask>*XX\n
```

Sent whenever the set of pressed keys changes. **bitmask** is a decimal bitmask of **all currently pressed keys** (see Keys table above). A value of `0` means all keys have been released. The external MCU can compare successive bitmasks to determine which keys were pressed or released.

Example sequence for pressing U and E simultaneously, then releasing both:
```
<- $TCSK5*XX\n      (U=1 and E=4 both pressed, bitmask=5)
<- $TCSK0*XX\n      (all keys released)
```

Example sequence for pressing U, then also pressing E, then releasing U:
```
<- $TCSK1*XX\n      (U pressed)
<- $TCSK5*XX\n      (E also pressed; bitmask now 5 = U+E)
<- $TCSK4*XX\n      (U released; E still held, bitmask=4)
<- $TCSK0*XX\n      (E released)
```

### LED State Change

```
<- $TCSL<i>,<r>,<g>,<b>,<auto>*XX\n
```

Sent whenever the LED color, intensity, or auto-adjust state changes, whether from an external `$TCCL`/`$TCCLA` command, an internal view (for example, AM/PM indicator), or automatic brightness adjustment. Format is identical to the `L` command response. See the L command for field descriptions.

### Temperature Change

```
<- $TCSM<adc>,<ds3234>,<ds1722>,<lm74>,<external>*XX\n
```

Sent whenever a new temperature reading is obtained from hardware and at least one sensor value has changed. Format is identical to the `M` command response. See the M command for field descriptions.

### Intensity Change

```
<- $TCSI<intensity>,<auto>*XX\n
```

Sent when the display intensity changes due to automatic brightness adjustment. Not sent in response to an explicit `$TCCI` or `$TCCIA` command (the command response provides that confirmation). Format is identical to the `I` command response. See the I command for field descriptions.

### ADC Update

```
<- $TCSHADC<light>,<vdda>,<vbatt>*XX\n
```

Sent whenever new ADC readings are obtained and at least one value (light level, VddA, or VBatt) has changed. Format is identical to the `H/ADC` command response. See the H command for field descriptions.

### RTTTL Playback Complete

```
<- $TCSBOK*XX\n
```

Sent when RTTTL playback finishes. Fires when the last note has been accepted into the hardware tone queue; the final note(s) may still be audible briefly. This notification is suppressed if playback is stopped via the `$TCCBS` command.

### HV State Change

```
<- $TCSHV<0|1>*XX\n
```

Sent when the HV supply state is toggled via the IR remote (Play/Pause key). `1` = enabled, `0` = disabled. Format is identical to the `H/HV` command response. This notification is coalesced.

**Note:** This notification is not sent for HV state changes triggered by serial `$TCCHVON`/`$TCCHVOF` commands — those are confirmed by the command response.

---

### Setting Changed

```
<- $TCSS<nn>,<value>*XX\n
```

Sent whenever a setting is changed via the clock's local UI (capacitive touch keys/menu navigation). Format is identical to the `S` command response — see the [Setting Index Reference](#setting-index-reference) for field descriptions.

Unlike other unsolicited notifications, setting change events are **not coalesced**: each setting that changes produces its own notification. The value reflects the live setting state at the time the notification is transmitted. If the notification queue is full, entries are silently dropped (see [TX notification queue](#implementation-notes)).

**Note:** This notification is not sent for settings changed via the serial `$TCCS` command — those are confirmed by the command response.

### GPS Status Change

```
<- $TCSDGPS<connected>,<valid>,<sats>*XX\n
```

Sent whenever any GPS status field changes: `connected` (module responding), `valid` (fix active), or `sats` (satellite count). Format is identical to the `D/GPS` command response. See the D command for field descriptions. This notification is coalesced.

---

### Alarm Active

```
<- $TCSRALM*XX\n
```

Sent (unsolicited) whenever any alarm transitions from inactive to active (rising edge). This fires for the timer/counter alarm when the countdown reaches zero (count-down mode) or the target value (count-up mode). Only the rising edge is reported; no further notification is sent while the alarm remains active.

After receiving this notification, send `$TCCRA*XX\n` to clear the alarm.

---

## Implementation Notes

- **Interrupt-driven I/O**: USART3 and USART4 use interrupt-driven I/O (not DMA). All DMA channels are allocated to other peripherals.
- **Double-buffered RX**: The ISR fills one receive buffer while the main loop processes the other. This prevents data loss if a new sentence arrives while processing.
- **Shared TX buffer**: Both USART1 and USART4 transmit from the same buffer with independent per-USART progress tracking. USART1 and USART4 may complete transmission at different times.
- **GPS coexistence**: On USART1, both the GPS parser and the serial remote parser see every received byte independently. The GPS parser ignores `$TC` sentences and the serial remote parser ignores `$GP` sentences. No special multiplexing is needed.
- **Command processing**: Commands are processed in the main application loop (not in ISR context). One command is processed per loop iteration.
- **TX notification queue**: Command responses and unsolicited notifications share a transmit queue (capacity 8). Messages are held in the queue and sent when both USART output channels are idle. Unsolicited notification types are coalesced in the queue (at most one pending entry per type, so only the latest state is sent). Key events are not coalesced. New entries are silently dropped when the queue is full — an uncommon condition in normal use.
- **Payload size limit**: Maximum payload length between `$TC` header and `*` checksum marker is 255 bytes.
- **Response size limit**: Maximum total response size (including header, checksum, and newline) is 48 bytes.

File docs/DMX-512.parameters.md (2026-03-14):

# kbx's Tube Clock

This document summarizes how DMX-512 channels may be used to control the clock's
display LEDs and beeper.

## Tube Clock DMX-512 parameter list

### Standard mode
- Channel 1: Master intensity
  - 0%: Shut (blackout)
  - 1%-100%: Dim -> Bright
- Channel 2: Tube 1 value (0 -> 9)
- Channel 3: Tube 2 value (0 -> 9)
- Channel 4: Tube 3 value (0 -> 9)
- Channel 5: Tube 4 value (0 -> 9)
- Channel 6: Tube 5 value (0 -> 9)
- Channel 7: Tube 6 value (0 -> 9)

### Extended mode
- Channel 1: Display control
  - 0%-12%: Display DMX-512 per-tube/dot (as below)
  - 13%-24%: Display time
  - 25%-36%: Display date
  - 37%-48%: Display temperature
  - 49%-60%: Display timer/counter (stop)
  - 61%-72%: Display timer/counter (run/count up)
  - 73%-84%: Display timer/counter (run/count down)
  - 85%-100%: Display timer/counter (reset)
- Channel 2: Beeper volume control
  - 0%: Beeper/tone off/muted
  - 1%-100%: Beeper volume low -> high
- Channel 3: Beeper pitch/tone control
  - 0%-100%: Beeper pitch/tone low -> high
- Channel 4: Display Strobe
  - 0%: Strobing off/display normal
  - 1%-100%: Strobe fast -> strobe slow
- Channel 5: Fade rate
  - 0%-100%: Fade fast -> fade slow
- Channel 6: Master intensity
  - 0%: Shut (blackout)
  - 1%-100%: Dim -> Bright
- Channel 7: Tube 1 value (0 -> 9)
- Channel 8: Tube 2 value (0 -> 9)
- Channel 9: Tube 3 value (0 -> 9)
- Channel 10: Tube 4 value (0 -> 9)
- Channel 11: Tube 5 value (0 -> 9)
- Channel 12: Tube 6 value (0 -> 9)
- Channel 13: Tube 1 intensity
- Channel 14: Tube 2 intensity
- Channel 15: Tube 3 intensity
- Channel 16: Tube 4 intensity
- Channel 17: Tube 5 intensity
- Channel 18: Tube 6 intensity
- Channel 19: Dot (colon, lower right)
- Channel 20: Dot (colon, upper right)
- Channel 21: Dot (colon, lower left)
- Channel 22: Dot (colon, upper left)
- Channel 23: Dot (Tube 1, right)
- Channel 24: Dot (Tube 1, left)
- Channel 25: Dot (Tube 2, right)
- Channel 26: Dot (Tube 2, left)
- Channel 27: Dot (Tube 3, right)
- Channel 28: Dot (Tube 3, left)
- Channel 29: Dot (Tube 4, right)
- Channel 30: Dot (Tube 4, left)
- Channel 31: Dot (Tube 5, right)
- Channel 32: Dot (Tube 5, left)
- Channel 33: Dot (Tube 6, right)
- Channel 34: Dot (Tube 6, left)

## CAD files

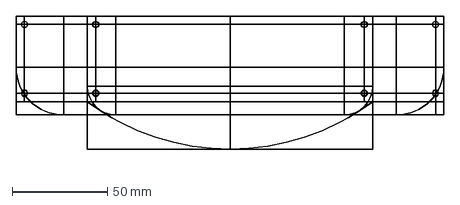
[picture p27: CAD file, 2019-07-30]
hardware/Base.dxf
225.0 x 78.3 mm

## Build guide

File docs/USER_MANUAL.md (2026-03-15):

# kbx's Tube Clock

_So...I built one (or someone gave me one), loaded the firmware and...now what?_

Congratulations! Read on...

## Getting started with your Tube Clock

After confirming everything is working, using the clock is pretty simple! Here's
how it works:

When powered on, the clock is either set or it is not set (such as if the
battery/capacitor drained or this is the first time you've powered it on).
- If the clock is set, it will resume displaying the time (and date and
  temperature, if the "Default to Toggle mode" option is enabled. More on this
  later on).
- If the clock is not set, display animations will run continuously (so the
  digits will just keep changing).

### It's working! Now what?

If you've powered it on and are looking at continuously rotating digits, you'll
first need to set the time and date. To do so, start by touching the `E` touch
key. This will exit the time/date/temperature view and enter into the main menu
view. Alternatively, if your clock has a GPS module installed or connected,
just wait for the GPS device to get a fix and your clock will set itself!

#### The Main Menu view

You can identify the main menu view as you'll see the right-most two digits lit
with a single dot to their right (the lower of the two left colon indicator
lamps) with the selected menu item number displayed on the left two tubes.
Press the `U` key to increase or the `D` key to decrease the selected
menu item number as indicated by the LEDs. To make your selection, touch the
`E` key again to enter into the selected mode/menu item. (Perhaps you are
starting to build the connection that `E` means "Enter"/"Exit".)

#### Setting the time and date

If, when you started, the time and date were not set, entering the main menu
view will automatically select option 5, the "set time" function. If option 5
is not selected, use the `U` and/or `D` keys to select it. Touch the `E` key to
enter into the set time/date view to set the time.

Once you've entered into mode 5, you'll see the set time/date view. This is the
standard view used to set times and dates. In this view, the touch keys work as
follows:

- `U` increases the selected value
- `D` decreases the selected value
- `C` moves the selection left
- `B` moves the selection right
- `A` applies the date/time as set
- `E` exits to the main menu

Use the keys to adjust the values to the correct time and touch the `A` key to
commit the time shown on the display to the clock's hardware. When you're done,
touch the `E` key to exit back to the main menu.

**Important:** You must touch the `A` key to save the time/date as set! If you
do not, the selected values will be lost upon exiting the set time/date view.

Once the time has been set, the date must be set. Upon exiting mode 5 (set
time), mode 6 will be automatically selected if the date has not been set
(that is, if the year is equal to zero, which...yeah...). In any event, mode 6
is the "set date" mode and, once it is selected in the main menu, touch the `E`
key again to enter that mode to set the date.

Setting the date works exactly the same way as setting the time does in terms of
the user interface. Note that, by default, the display shows **year**,
**month**, **day** (see footnote below). Use the keys as described above to
make the appropriate selections and then press the `A` key to apply them. The
`E` key exits back to the main menu view.

#### I set my clock! What's next?

Congratulations! You've now got a working, set clock! At this point, use the
main menu to select either mode 1 (fixed time/date/temperature display) or
mode 2 (auto-toggle time/date/temperature displays) to see the time, date,
and/or temperature.

At this point, we're left with...

## Advanced topics and settings

Your Tube Clock can do more than just show you the time, date, and temperature.
Let's dig in and take a closer look!

### Views

The Tube Clock has a number of configuration options that may be changed,
allowing some customization of the clock's behavior. If you've just gone
through the process of setting the time and date, you've already begun using
some of its simple menu system and "views".

Configuration options/settings are changed by using a number of different views.
These views provide a way to access the various settings so that they may be
modified. Each setting is really nothing more than a number, but this number
determines something: the volume of the beeper, the behavior of the colons when
displaying the time, or the hour in which DST takes effect, as some examples.
The various views simply display this information in a way that makes sense
while providing a means by which to modify the settings.

Entering into any given mode activates a view. Each view presents information on
the display a little differently. In addition, the touch keys are used somewhat
differently in each view. Let's describe the views now, as, later on when we
discuss the various modes, we'll refer back to the views to describe the
expected behavior (what you'll see on the display, what the touch keys will do,
etc.) upon entering into any given mode.

#### Main Menu View

If you've gone through the process to set the time and date, you've already seen
this view. You can identify the main menu view as you'll see only the two
left-most tubes lit along with the lower dot on the left colon. The touch keys
are used as follows:

- `U` increases the selected mode number
- `D` decreases the selected mode number
- `C` enters Time/Date/Temperature view in toggle mode (aka mode 2)
- `B` enters Time/Date/Temperature view in fixed mode (aka mode 1)
- `E` enters into the selected mode (as indicated by the tubes)

#### Time/Date/Temperature View

This is the view that--you guessed it--displays the time, date, and temperature.
This same view is used whether the clock is in mode 1 (fixed display) or mode 2
(toggle/rotate display). This is the view in which your Tube Clock will spend
the vast majority of its time. In this view, the touch keys are used as follows:
- `U` increases the display intensity (if automatic adjustments are disabled)
- `D` decreases the display intensity (if automatic adjustments are disabled)
- `C` displays the temperature
- `B` displays the date
- `A` toggles display of time (hours, minutes, seconds) and seconds-since-midnight
- `E` exits to the main menu

#### Timer/Counter View

This is the view that displays the timer/counter. In this view, the touch keys
work as follows:

- When the timer/counter is stopped:
  - `U` increases the timer/counter value
  - `D` decreases the timer/counter value
- When the timer/counter is running:
  - `U` counts up at next start
  - `D` counts down at next start
- `C` resets the timer/counter
- `B` stops the timer/counter
- `A` starts the timer/counter
- `E` exits to the main menu

#### DMX-512 View

This view displays data being sent to the clock via DMX-512. If no DMX-512
signal is present on the RS-485 serial interface, this view does nothing and
will not activate. See the DMX-512 parameters document for more information.

#### Set Time/Date View

If you've already set your clock, you've seen this view; it was also described
above. This is the view used to set times and dates. The existing values are
shown when the view is entered. One pair of tubes will be "highlighted" at a
time and the value on the highlighted block is what will be modified by
touching the `U` and `D` touch keys. In this view, the touch keys work as
follows:

- `U` increases the selected value
- `D` decreases the selected value
- `C` moves the selection left
- `B` moves the selection right
- `A` applies the date/time as set
- `E` exits to the main menu

#### Set Bits View

This view is used to modify settings that are either on/enabled/`1` or
off/disabled/`0`. This view will display the setting number on the middle pair
of tubes while its state (enabled/disabled) is shown on the right-most tube.
The existing settings are shown when the view is entered. The touch keys can be
used to toggle the various settings on and off as follows:

- `U` selects the next bit
- `D` selects the previous bit
- `C` sets/turns on the bit
- `B` clears/turns off the bit
- `A` applies (saves) the settings
- `E` exits to the main menu

#### Set Value View

This view allows adjusting of various settings values. The existing value is
shown when the view is entered and it appears on the right side of the display.
The mode number is shown on the left side of the display. The touch keys work
as follows:

- `U` increases the displayed value
- `D` decreases the displayed value
- `C` sets the displayed value to the maximum allowed value for the setting
- `B` sets the displayed value to the minimum allowed value for the setting
- `A` applies (saves) the selected value
- `E` exits to the main menu

When this view is used for a group of related settings (for example, RGB color channels
or temperature sensor calibrations), the item number appears on tube 4 and
`B`/`C` cycle through items rather than jumping to the minimum/maximum:

- `C` selects the next item
- `B` selects the previous item
- `A` applies (saves) all values

#### System Status View

This view is unique and is explained in more detail later on below.

### Time Slots

The Tube Clock has the ability to store up to eight "times of significance" --
you can think of it as an alarm clock with eight different alarm times that you
can set. Moving forward, we'll refer to each of these times as a "time slot".

Each of these eight time slots can be configured to trigger any (combination) of
three events:

- An audible alarm
- A blinking display
- Turn the tubes on or off

The timer/counter and external alarm inputs can also trigger the audible alarm
or display blinking.

The first is probably self-explanatory -- when the time matches the time that
was set into the time slot, the alarm will sound. It's just like an alarm clock.

The second is similar to the audible alarm, but instead of beeping, it'll cause
the display to switch to full brightness and blink at 1 Hz.

The third is a bit more unique -- it allows the tubes to be shut down for a time
interval. As an example, this feature could be used to turn the tubes off
during the day while no one is home to view the clock. In theory, this
preserves the life of the tubes and will also save some energy.

### Other modes

At this point, you should have a feel for how to select a given mode by using
the main menu view. (If not, scroll up and (re)read the Main Menu view section
above.) On the back of the PCB you'll find a listing of all of the
clock's various operating modes; the numbers seen in that list correspond
directly to what you can select in the main menu view. Let's go through them
now.

#### Modes 1 and 2: Time/Date/Temperature view

These modes were mentioned briefly above, but left out some detail.

The only difference between these two modes is that mode 2 will automatically
rotate the display between the time, date, and temperature. That aside, they
behave the same, as they both use the Time/Date/Temperature view as described
above.

In mode 2, it is possible to adjust how long the time, date, and temperature
each appear. The duration for each is configured by adjusting the values set in
modes 20, 21, and 22. The values are in seconds and the defaults are 24 (time),
3 (date), and 3 (temperature).

#### Mode 3: Timer/Counter

Mode three allows the use of the clock as a timer or counter. It can count up or
down in seconds. See the Timer/Counter View section above.

An alarm can be triggered when the timer reaches either zero (if counting down)
or the reset value (if counting up). The timer/counter reset value is
determined by the value set in mode 7. This value is applied when the
timer/counter is reset and the timer is set to count down; if set to count up,
resetting the timer sets it to zero.

#### Mode 4: DMX-512 view

This mode displays data being sent to the clock via DMX-512. If no DMX-512
signal is present on the RS-485 serial interface, this mode does nothing and
cannot be selected. See the DMX-512 parameters document for more information.

#### Modes 5 and 6: Set time/date view

View: Set Time/Date View

These modes were described in the "Getting Started" and "Set Time/Date View"
sections above.

#### Mode 7: Set Timer/Counter reset value

View: Set Value View

This mode allows adjusting of the reset value for the timer/counter. Adjust the
value up or down as desired and touch the `A` key to save it; changes are lost
if not saved.

**Important:** You must touch the `A` key to save the new value! If you do not,
the new value will be lost upon exiting the set value view.

#### Mode 8: System Status View

This view is unique from all of the other views; its main purpose is to check
various aspects of the clock's hardware such as the tube lifetime counter.

When entering this mode for the first time after the clock is powered on, it
will display the time (normally in hours) that the tubes have been powered on.
Pressing the `C` touchkey will reset this timer. *For the first hour, the
tube-on time is shown in seconds.*

The `U` and `D` touchkeys may be used to display additional information. A
two-digit value will appear on the right-most pair of tubes as well as the left
colon:

- Mode 1: Displays peripherals the application found. Tube 1 = DS1722, Tube 2 =
  LM74, Tube 3 = DS3234, Tube 4 = GPS module
- Mode 2: Displays the number of satellites the GPS module is reporting.
- Mode 3: CPU voltage (3300 = 3.3 volts)
- Mode 4: Battery/super capacitor voltage (3000 = 3 volts)

Touch the `E` key to exit this view.

#### Mode 10: Set Options Bits

View: Set Bits View

This mode is where we configure a number of options that govern the clock's
behavior. These are options that can be either on or off (enabled or disabled).
As such, bits represent them nicely. Each bit's meaning is described on the
back of the PCB, but we'll document them here, as well:

- Bit 0: 12-hour mode - if set, the time is displayed as a 12-hour clock
  (AM/PM), otherwise it will display as a 24-hour clock.
- Bit 1: Status LED as PM indicator - if set, the status LED will illuminate
  when it is PM, otherwise it will remain off.
- Bit 2: Hourly Chime - if set, at the top of every hour, the clock will
  indicate the current hour in binary audibly using a series of high (1) and low
  (0) beeps.
- Bit 3: DST Enabled - if set, the clock will adjust itself automatically for
  daylight savings time (DST) based on values configured in settings 24 through
  29 (see below).
- Bit 4: Display Fahrenheit - temperature is shown in degrees Fahrenheit if set,
  Celsius otherwise.
- Bit 5: Automatic Intensity Adjustment - if set, the display brightness will
  automatically adjust based on the ambient light level. If clear, manual
  adjustment is enabled when the time, date, or temperature is displayed.
- Bit 6: Startup To Toggle - if set, the clock defaults to mode 2 when powered
  on or when the idle timeout elapses (see mode 35). Otherwise, mode 1 is the default.
- Bit 7: DMX-512 Extended mode - if set, additional DMX-512 channels are used
  enabling enhanced control of the clock via the control protocol.
- Bit 8: MSDs Off - when set, Tubes that would otherwise be leading zeros are
  turned off in the time, date, temperature, and timer/counter views.
- Bit 9: Trigger Effect on Rotate - if set, the clock run an animation to
  prevent cathode poisoning each time the display rotates in mode 2.

#### Modes 11 through 13: Time slot/Alarm behavior bits

View: Set Bits View

Each of these three modes allows enabling or disabling of each of the three
behaviors described in the "Time Slots" section above. Bits 0 through 7
correspond to time slots 1 through 8, bit 8 corresponds to the timer/counter,
and bits 9 and 10 correspond to the external alarm input pins (latching and
momentary, respectively).

Mode 11 allows enabling or disabling the audible alarms/beeping, mode 12 allows
enabling or disabling the display blinking, and mode 13 allows enabling or
disabling the tubes between the selected slot and the next slot.

By default, the tubes remain on for all eight time slots while the audible
alarms and display blinking are disabled for all eight time slots.

#### Mode 14: PM Indicator Color

View: Set Value View

This mode allows adjusting the color of the status LED when it is used as a PM
indicator (see Bit 1 in mode 10). The item number appears on tube 4: channel 1
is red, channel 2 is green, and channel 3 is blue. The selected channel's
intensity value (0–4095) appears on tubes 0–3. Use the `B` and `C` keys to
cycle through the three channels and `U` and `D` to adjust the selected
channel's value.

**Important:** You must touch the `A` key to save the values! If you do not,
the changes will be lost upon exiting.

#### Modes 20 through 22: Time, Date, and Temperature display durations

View: Set Value View

As was described above, these three modes allow the adjustment of how long (in
seconds) the time, date, and temperature will appear when the clock is
operating in mode 2.

#### Mode 23: Fade duration

View: Set Value View

This mode allows the adjustment of the duration of the fading that occurs as
digits change on the display. This effect is used in display modes 1, 2, and 3.
The value set describes the fade duration in milliseconds and the default is 100.

#### Modes 24 through 29: Daylight Savings Time (DST) settings

View: Set Value View

These modes allow the configuration of exactly when clock adjustments occur due
to DST beginning and ending. The default values correspond with DST changes
that occur in the US.

Mode 24 allows setting the month in which DST begins.

Mode 25 allows setting the day of week ordinal (first, second, third, fourth) in
which DST begins.

Mode 26 allows setting the month in which DST ends.

Mode 27 allows setting the day of week ordinal (first, second, third, fourth) in
which DST ends.

Mode 28 allows setting the day of the week on which the DST time change occurs.
Value from 0=Sunday, 1=Monday...6=Saturday.

Mode 29 allows setting the hour at which the DST time change occurs.

#### Mode 30: Effect duration

View: Set Value View

This mode allows the adjustment of the duration of animations that appear to
prevent cathode poisoning. The value is a time in milliseconds and it defaults
to 500.

#### Mode 31: Effect frequency

View: Set Value View

This mode allows the adjustment of the frequency of animations that appear to
prevent cathode poisoning. The value is a time in seconds and it defaults to 300.

#### Mode 32: Minimum Intensity

View: Set Value View

This mode allows the adjustment of the minimum intensity allowed when automatic
intensity adjustments are enabled (see mode 10). It is intended to keep the
display from dimming _too much_.

#### Mode 33: Beeper Volume

View: Set Value View

This mode allows adjusting of the beeper volume. Higher numbers mean a louder
beeper. This setting affects all sounds the beeper produces. Easy enough, yeah?

#### Mode 34: Temperature Calibration

View: Set Value View

This mode allows adjustment of the temperature calibration offset for each of
the supported temperature sensors. The sensor number appears on tube 4 (1–4
corresponding to STM32 ADC, DS3234, DS1722, and LM74) and the current sensor's
calibration offset appears on the right side of the display. The upper dot of
the right colon lights when the value is negative. Use the `B` and `C` keys to
cycle through sensors and `U` and `D` to adjust the offset (in tenths of a
degree Celsius).

#### Mode 35: Idle Timeout

View: Set Value View

This mode allows adjusting of the idle timeout — the duration of inactivity (in
seconds) after which the clock automatically returns to the default display
view (mode 1 or 2). The value may be set from 10 to 600 seconds; the default
is 120 seconds (two minutes).

#### Mode 36: Date Format

View: Set Value View

This mode allows adjusting of the way the year, month, and day are arranged on
the display when the date appears. The possible values are zero (the default),
one, or two, and they correspond to the following arrangements:

- 0: Year, Month, Day
- 1: Day, Month, Year
- 2: Month, Day, Year

Note that this setting affects how the date is displayed both when viewing the
date (mode 1 or 2) **and** when setting the date (in mode 6).

#### Mode 37: Time zone (time offset)

View: Set Value View

This mode allows setting of the local time zone. This value is only used when a
GPS module is attached to the clock. It may be specified in 15-minute
intervals. The upper left colon indicator lights to indicate a negative value.

#### Mode 38: Colon behavior

View: Set Value View

This mode allows adjusting of the colon behavior when the time is displayed. The
behavior is defined by the values as follows:

- 0 = On
- 1 = Off
- 2 = Blink
- 3 = Blink Upper
- 4 = Blink Lower
- 5 = Alternate Upper/Lower

#### Mode 39: DMX-512 Address

View: Set Value View

This mode allows setting of the clock's DMX-512 address. If DMX-512 is not in
use, this setting is irrelevant. See the DMX-512 parameters document for more
information.

#### Modes 40 through 47: Set Slot Times

View: Set Time/Date View

These modes allow setting of the time for each of the eight time slots. See the
"Time Slots" section above for more information.

---

**Footnote:** Yes, I said **year**, **month**, **day**, the way the date is
_supposed_ to be written/displayed. ;) If you don't like it, there is a setting
that can be modified to change it. You're welcome. :p

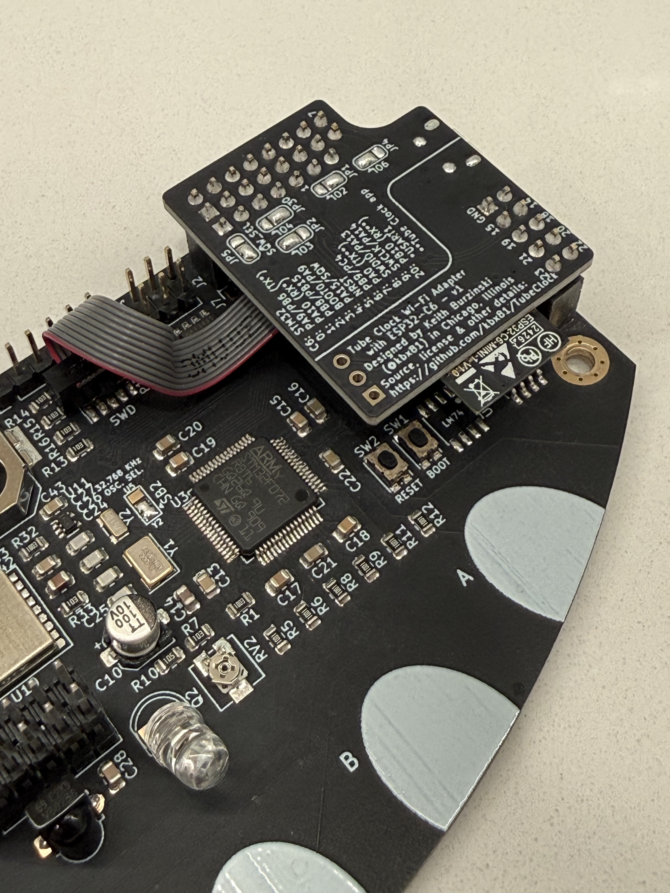
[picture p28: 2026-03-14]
media/wifi_pcb_installed.jpg

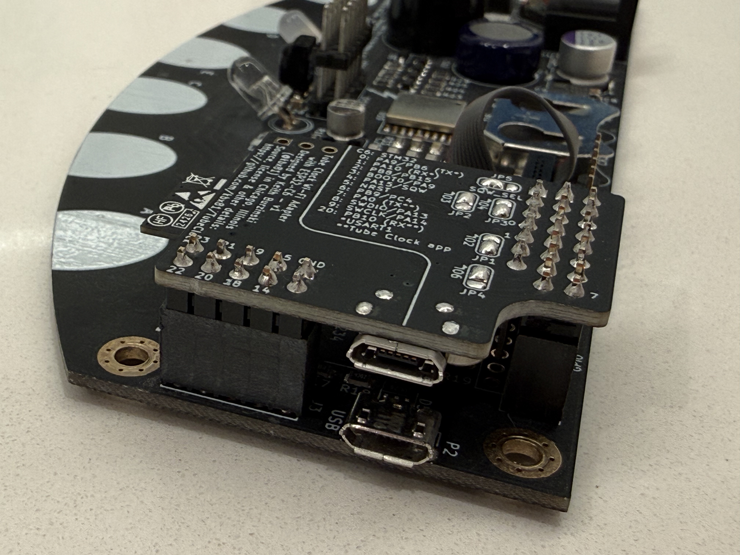
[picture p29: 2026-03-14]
media/wifi_pcb_installed_2.jpg

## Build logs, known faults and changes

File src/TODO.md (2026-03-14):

# kbx's Tube Clock

## TODO List

- [ ] Allow runtime user-defined IR remote control codes
- [ ] Direct digit entry from IR remote
- [ ] Send key presses via `SerialRemote`
- [ ] Animator as a View?
- [ ] More effects/animations
- [ ] Hardware version displayed in View/start-up?
- [ ] DMX-512 Standard mode testing (...and fixes?)
- [ ] Documentation!

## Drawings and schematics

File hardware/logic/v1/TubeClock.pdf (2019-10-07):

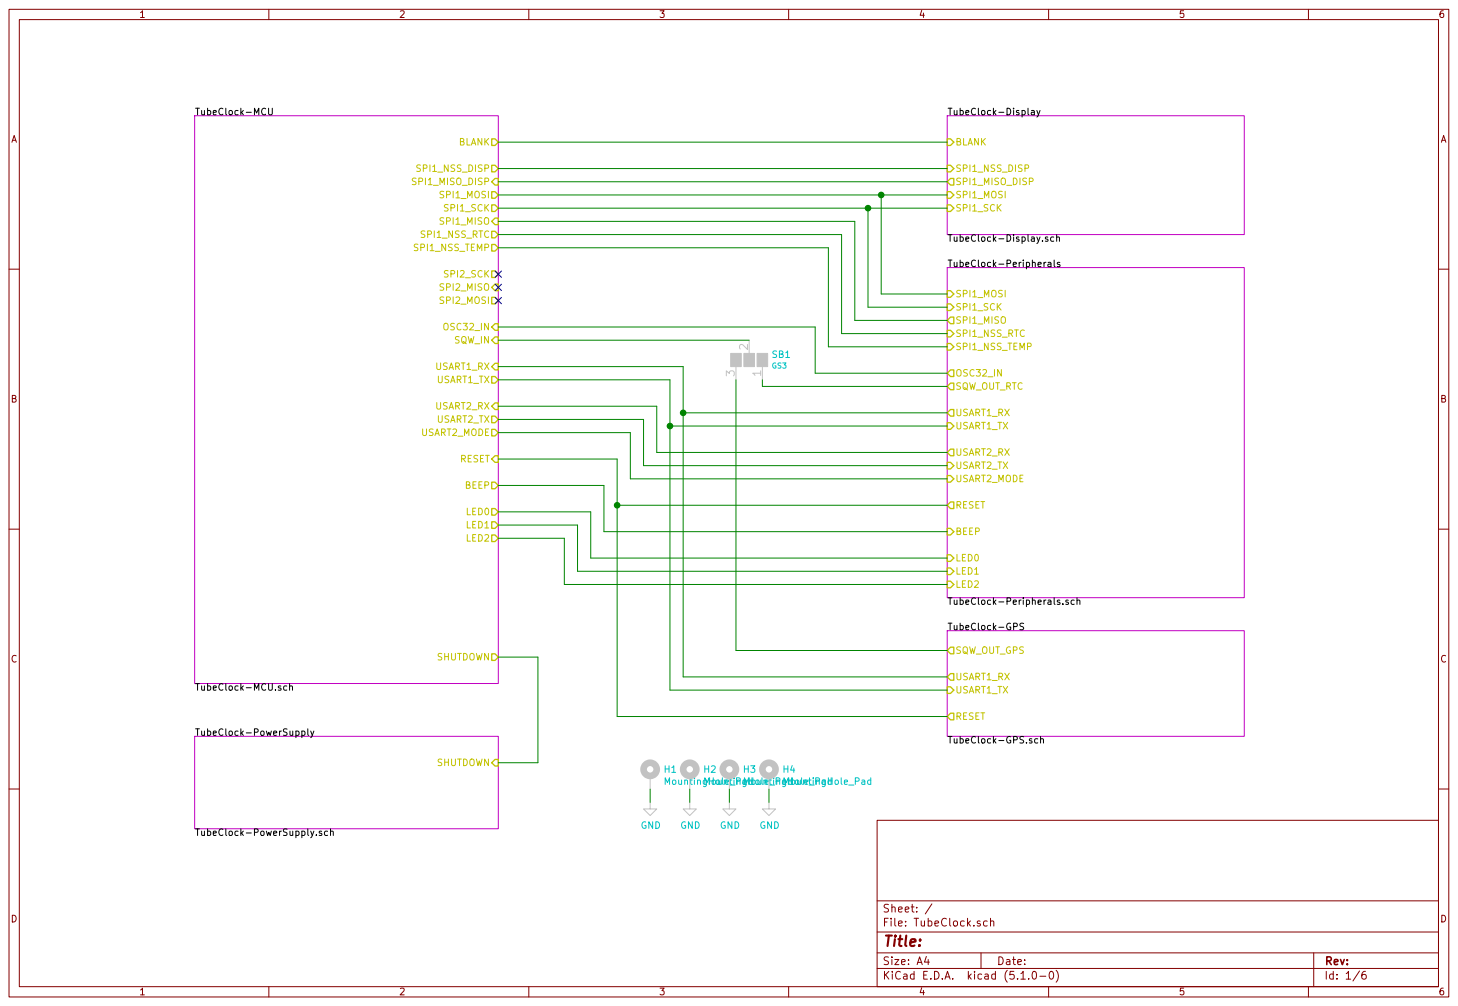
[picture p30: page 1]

TubeClock-GPS.sch RESET USART1_TX USART1_RX

Id: 1/6 Title: File: TubeClock.sch Sheet: / TubeClock-PowerSupply

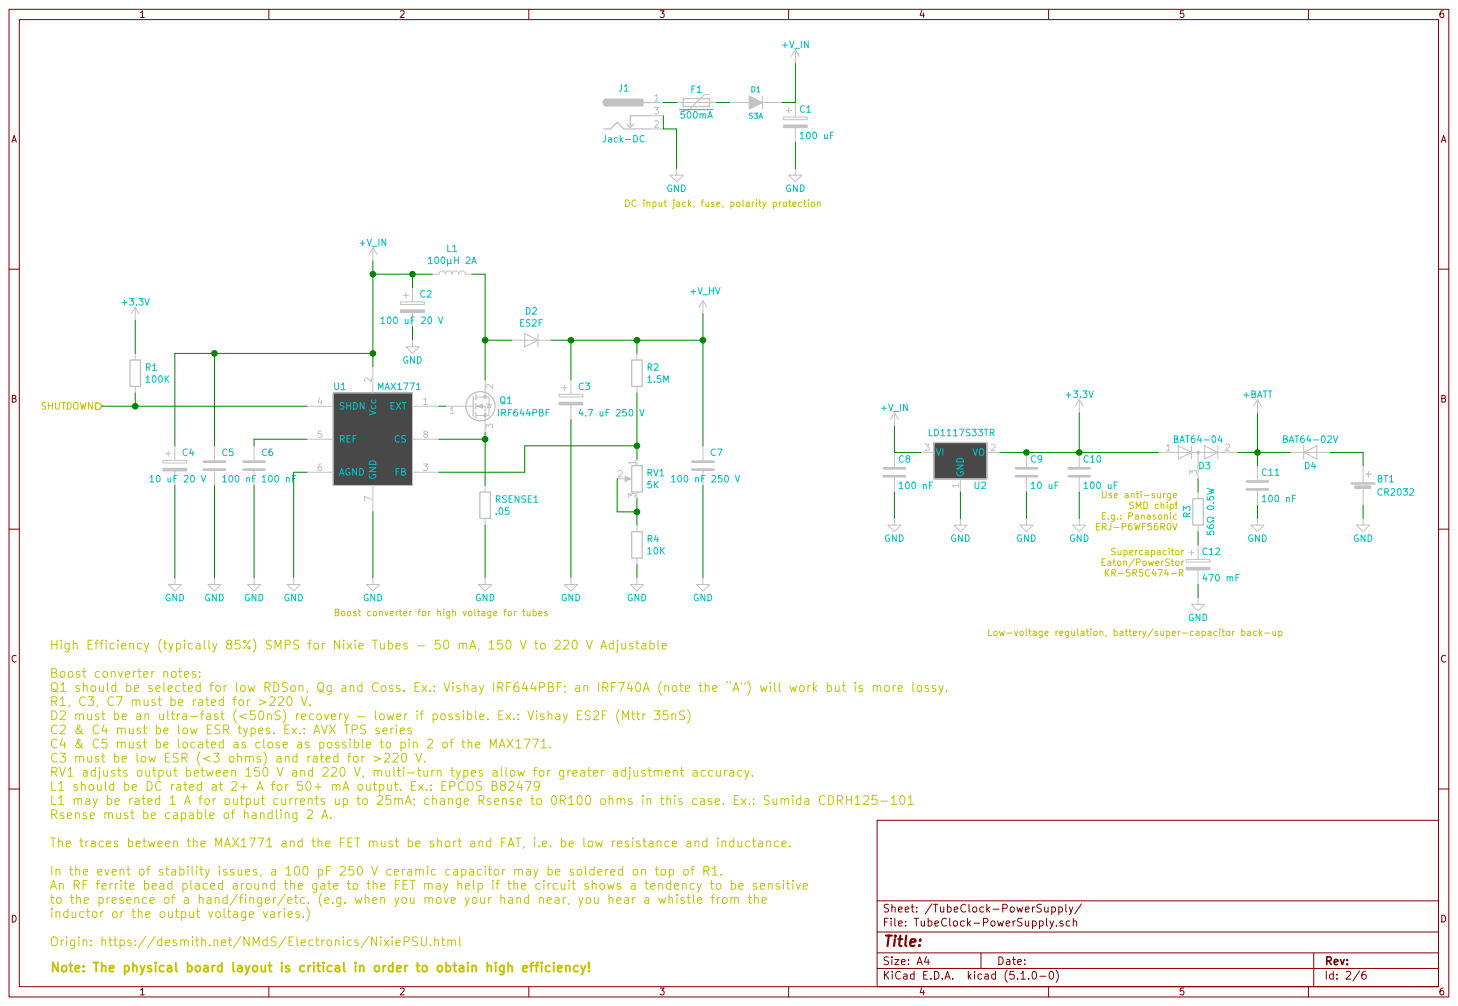
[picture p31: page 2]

DC input jack, fuse, polarity protection

7 CS 8 U1 MAX1771 Note: The physical board layout is critical in order to obtain high efficiency!
+V_IN High Efficiency (typically 85%) SMPS for Nixie Tubes - 50 mA, 150 V to 220 V Adjustable

Supercapacitor Eaton/PowerStor KR-5R5C474-R

Low-voltage regulation, battery/super-capacitor back-up

Boost converter notes:
Q1 should be selected for low RDSon, Qg and Coss. Ex.: Vishay IRF644PBF; an IRF740A (note the A) will work but is more lossy.
R1, C3, C7 must be rated for >220 V.
D2 must be an ultra-fast (<50nS) recovery lower if possible. Ex.: Vishay ES2F (Mttr 35nS)
C2 & C4 must be low ESR types. Ex.: AVX TPS series
C4 & C5 must be located as close as possible to pin 2 of the MAX1771.
C3 must be low ESR (<3 ohms) and rated for >220 V.
RV1 adjusts output between 150 V and 220 V, multi-turn types allow for greater adjustment accuracy.
L1 should be DC rated at 2+ A for 50+ mA output. Ex.: EPCOS B82479
L1 may be rated 1 A for output currents up to 25mA; change Rsense to 0R100 ohms in this case. Ex.: Sumida CDRH125-101
Rsense must be capable of handling 2 A.

The traces between the MAX1771 and the FET must be short and FAT, i.e. be low resistance and inductance.

In the event of stability issues, a 100 pF 250 V ceramic capacitor may be soldered on top of R1.
An RF ferrite bead placed around the gate to the FET may help if the circuit shows a tendency to be sensitive
to the presence of a hand/finger/etc. (e.g. when you move your hand near, you hear a whistle from the
inductor or the output voltage varies.)

Sheet: /TubeClock-PowerSupply/
File: TubeClock-PowerSupply.sch
Id: 2/6 Title:

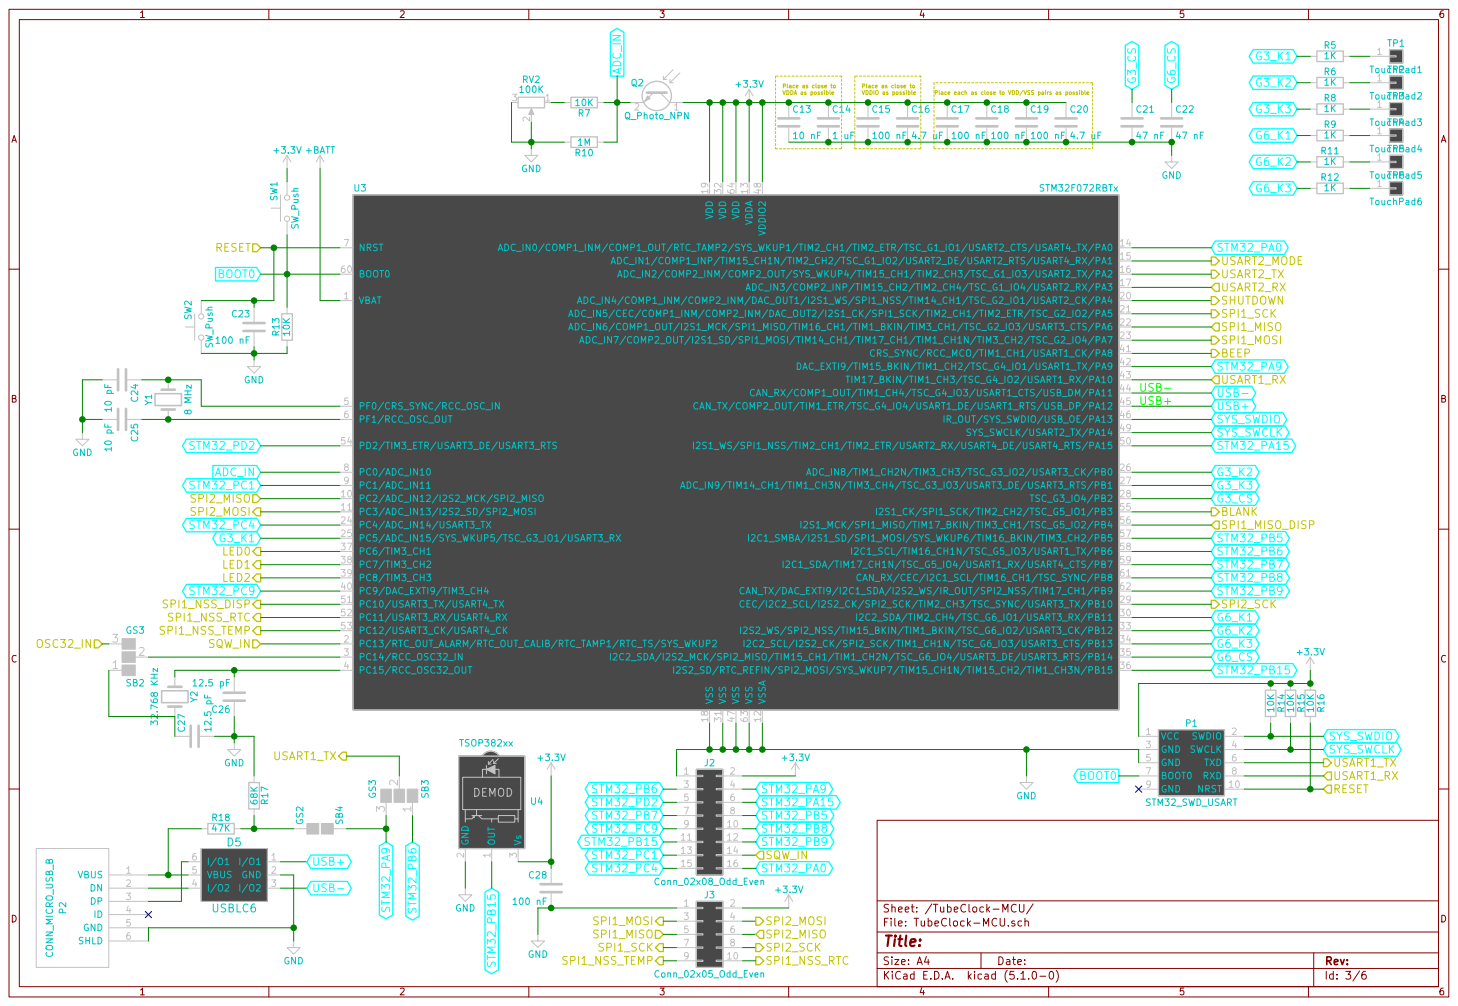
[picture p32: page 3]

Place each as close to VDD/VSS pairs as possible

Id: 3/6 Title: File: TubeClock-MCU.sch Sheet: /TubeClock-MCU/

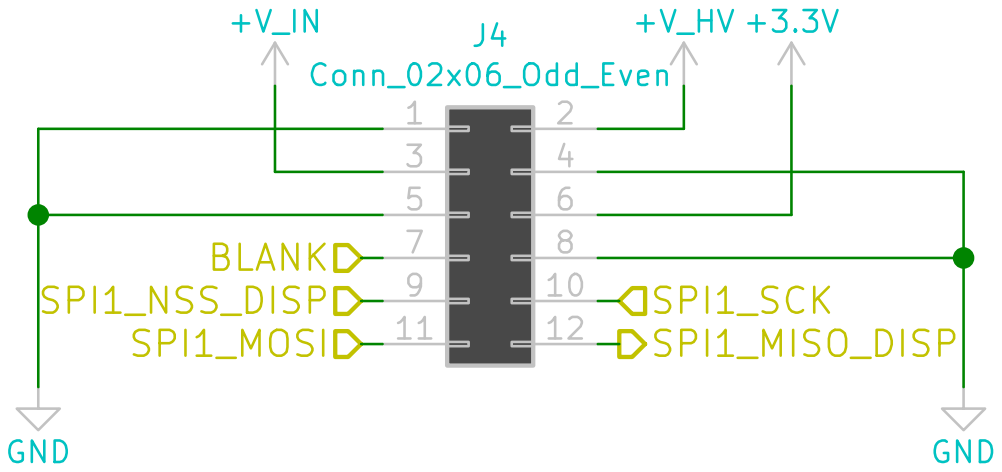
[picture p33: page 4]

Sheet: /TubeClock-Display/
File: TubeClock-Display.sch
Id: 4/6 Title:

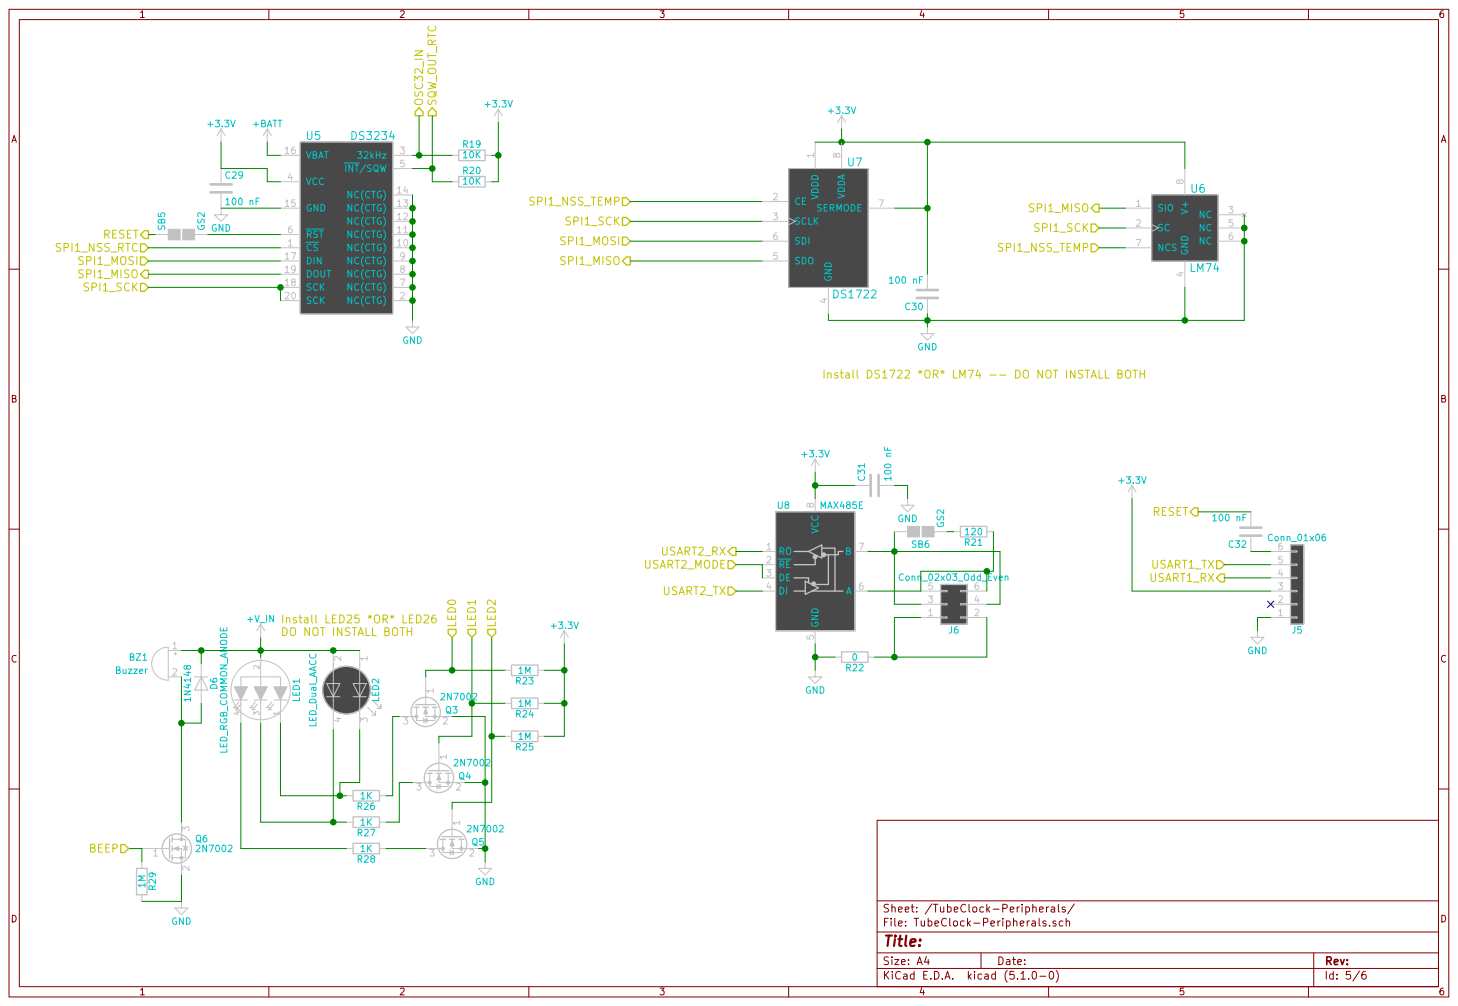
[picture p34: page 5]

4 SDO 5 SDI 6 SERMODE 7 VDDA

Install LED25 *OR* LED26
DO NOT INSTALL BOTH

File: TubeClock-Peripherals.sch
Id: 5/6 Title:

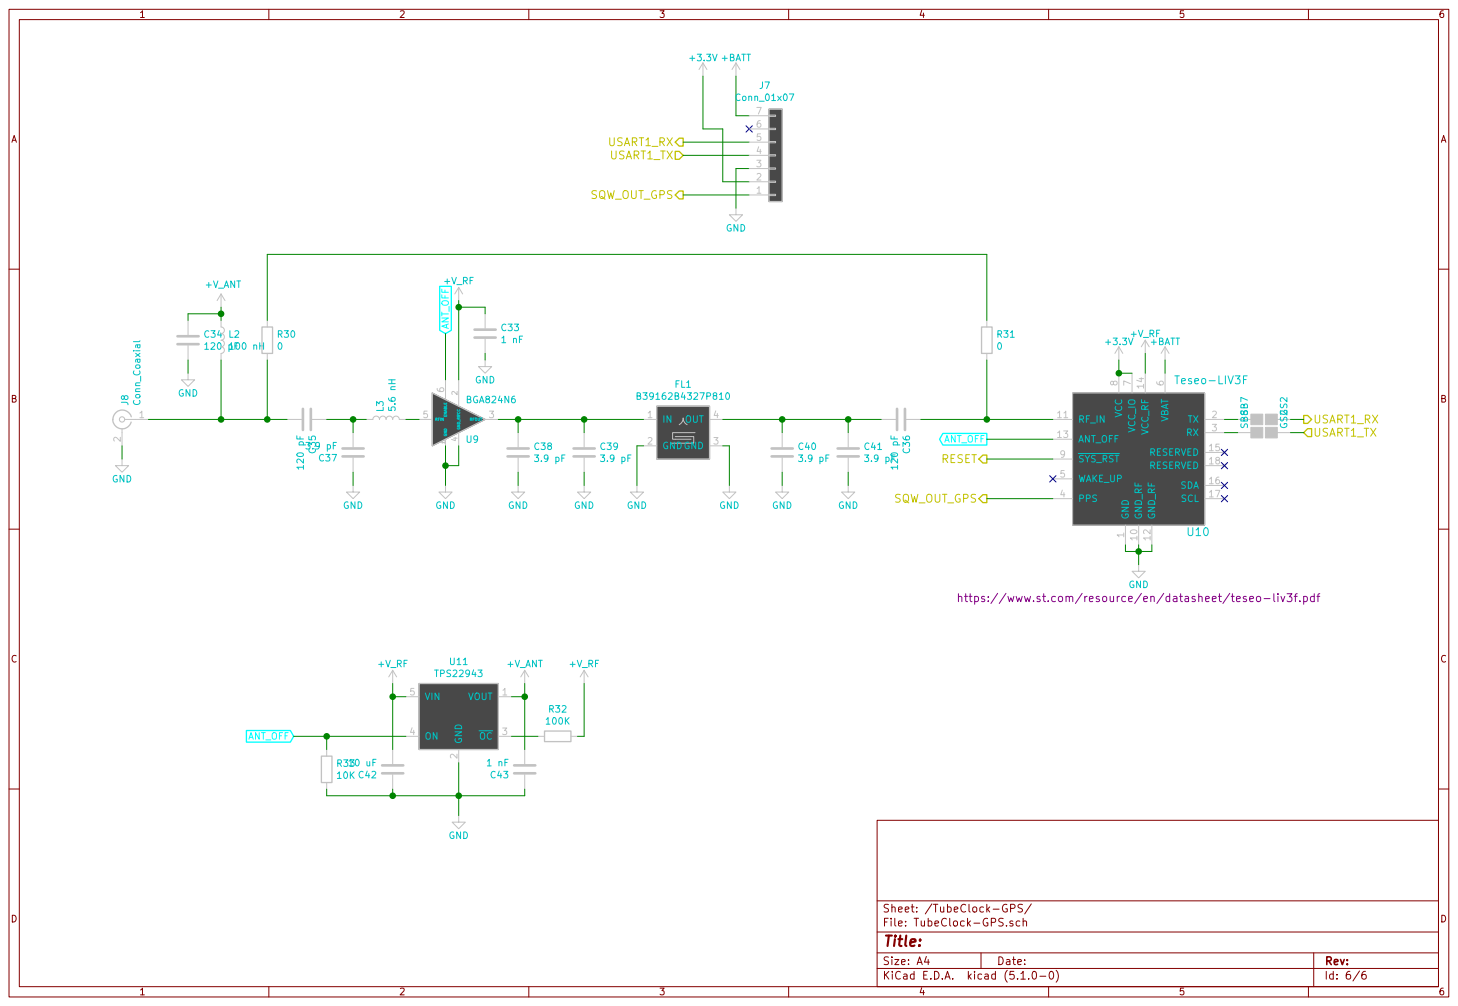
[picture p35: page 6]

1 GND_RF 10 RF_IN 11 GND_RF 12 ANT_OFF 13 VCC_RF 14 RESERVED 15 SDA 16 SCL 17 RESERVED 18 TX 2 RX 3 PPS 4 WAKE_UP 5 VBAT

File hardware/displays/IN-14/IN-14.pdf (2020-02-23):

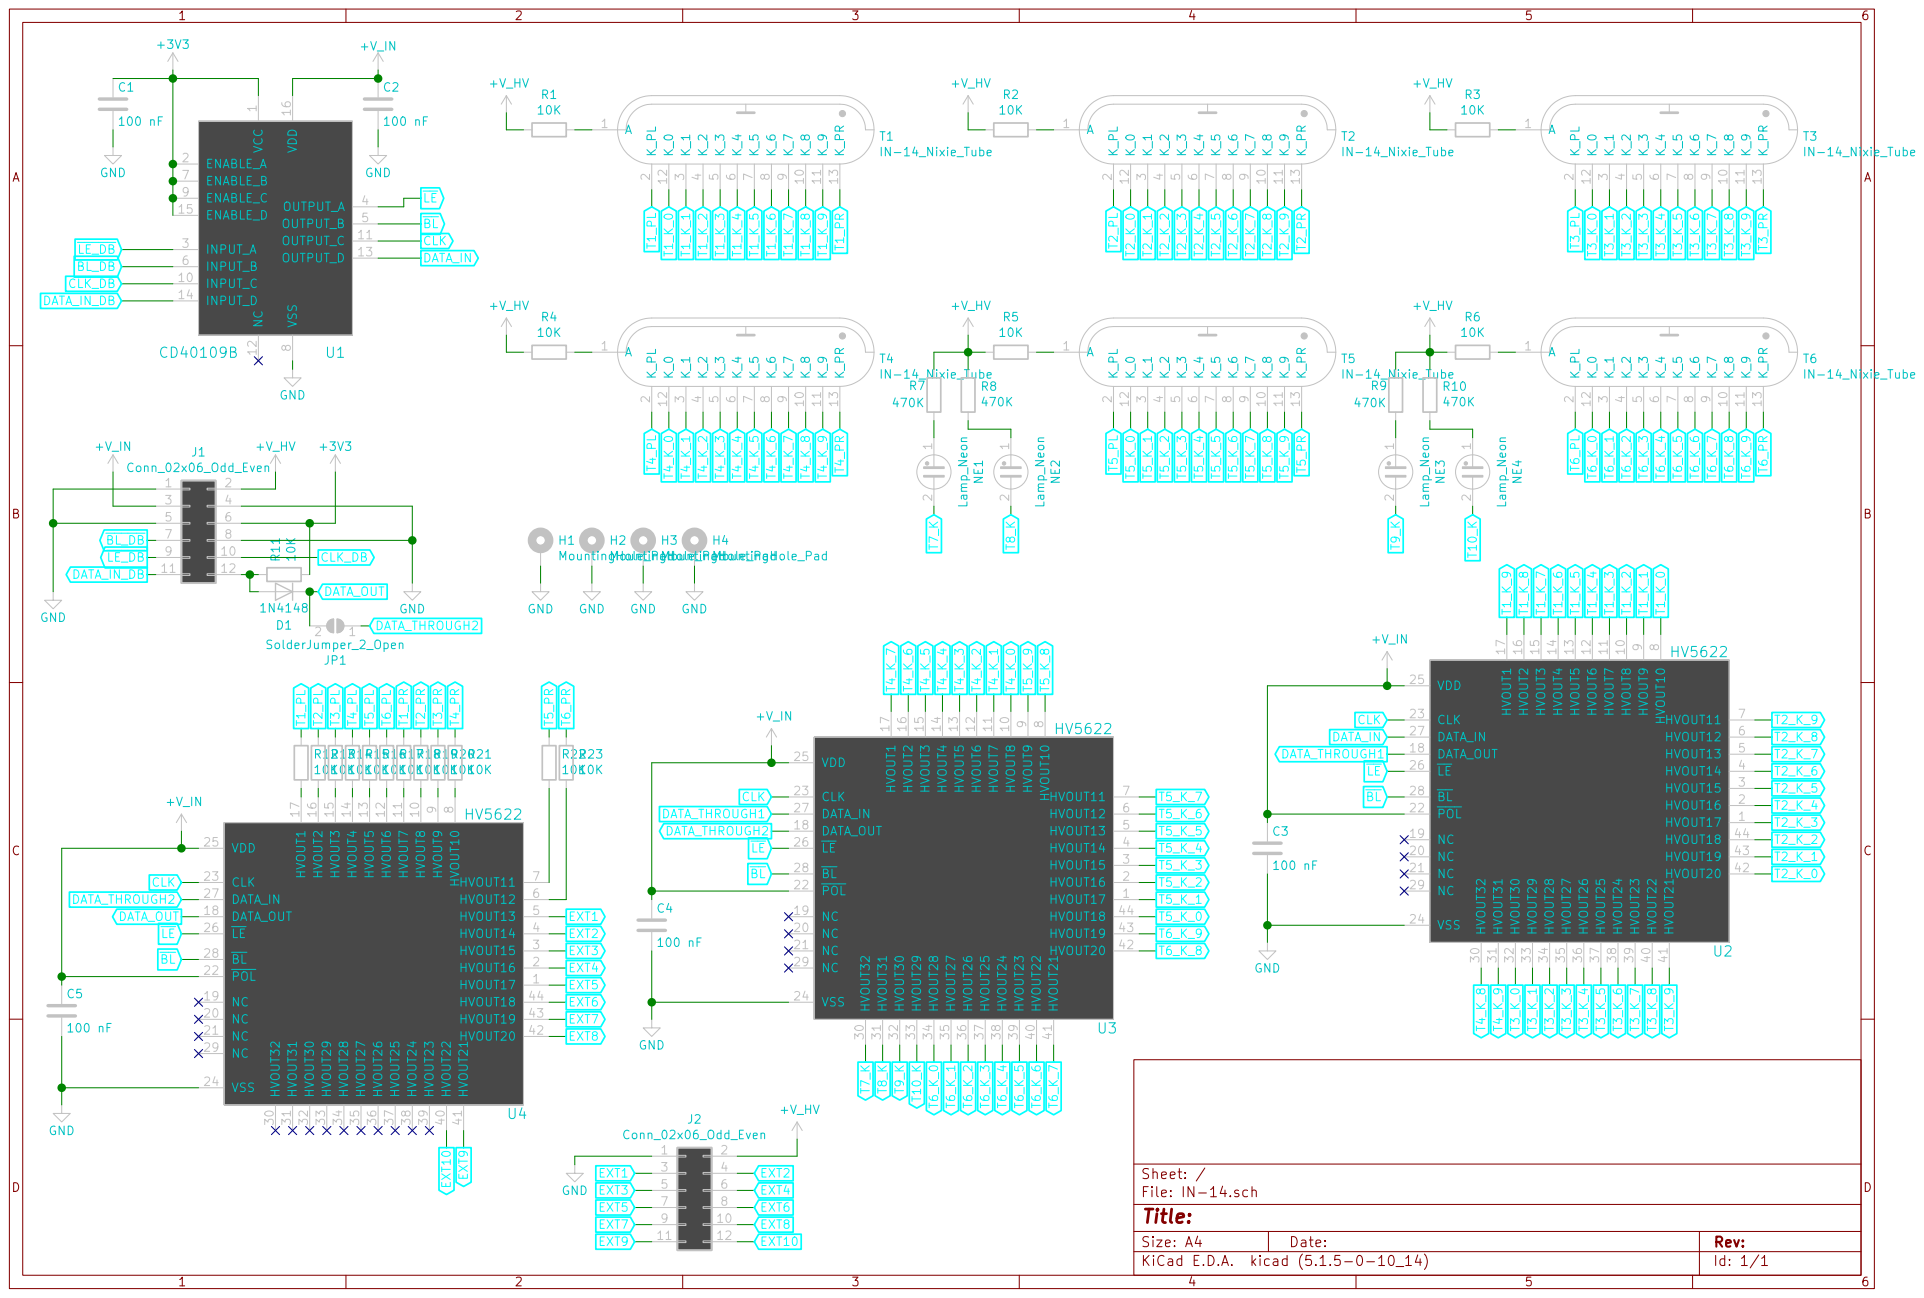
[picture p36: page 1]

Id: 1/1 Title: File: IN-14.sch Sheet: / R11 10K D1

9 U3 HV5622 HVOUT17 1 HVOUT8 10 HVOUT7 11 HVOUT6 12 HVOUT5 13 HVOUT4 14 HVOUT3 15 HVOUT2 16 HVOUT1 17 DATA_OUT 18 NC 19 HVOUT16 2 NC 20 NC 21 POL 22 CLK 23 VSS 24 VDD 25

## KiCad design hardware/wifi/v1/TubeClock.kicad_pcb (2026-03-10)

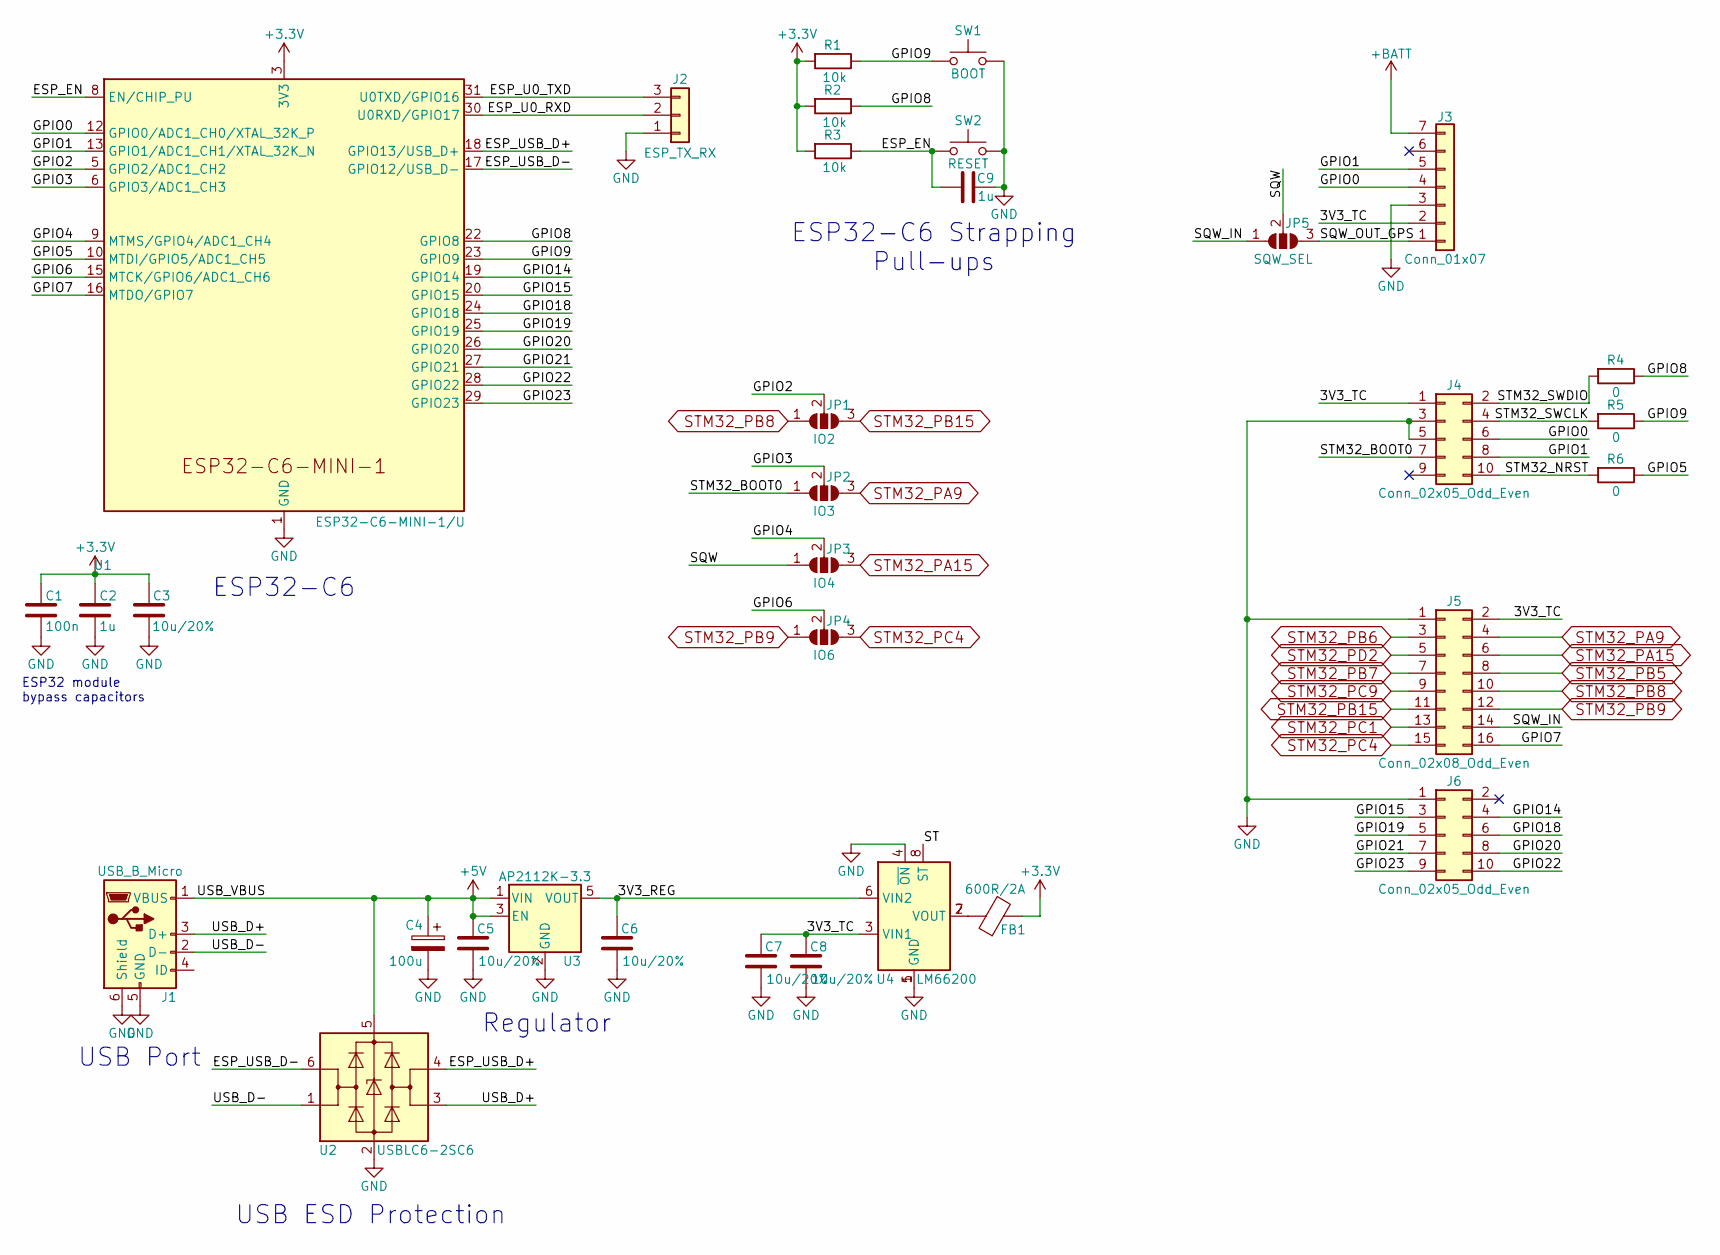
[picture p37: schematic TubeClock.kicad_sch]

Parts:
C1: 100n; C_0402_1005Metric; MPN1 CC0402KRX5R6BB104
C2, C9: 1u; C_0402_1005Metric; MPN1 CC0402KRX5R6BB105
C3, C5, C6, C7, C8: 10u/20%; C_0603_1608Metric; MPN1 CC0603MRX5R6BB106
C4: 100u; CP_Elec_5x5.4; MPN1 UWR1A101MCL1GB
FB1: 600R/2A; L_0603_1608Metric; MPN1 MPZ1608S221ATA00
J1: USB_B_Micro; USB_Micro-B_Molex-105017-0001
J2: ESP_TX_RX; PinSocket_1x03_P2.54mm_Vertical
J3: Conn_01x07; PinSocket_1x07_P2.54mm_Vertical
J4: Conn_02x05_Odd_Even; PinHeader_2x05_P1.27mm_Vertical_SMD
J5: Conn_02x08_Odd_Even; PinSocket_2x08_P2.54mm_Vertical
J6: Conn_02x05_Odd_Even; PinSocket_2x05_P2.54mm_Vertical
JP1: IO2; SolderJumper-3_P1.3mm_Open_RoundedPad1.0x1.5mm
JP2: IO3; SolderJumper-3_P1.3mm_Open_RoundedPad1.0x1.5mm
JP3: IO4; SolderJumper-3_P1.3mm_Open_RoundedPad1.0x1.5mm
JP4: IO6; SolderJumper-3_P1.3mm_Open_RoundedPad1.0x1.5mm
JP5: SQW_SEL; SolderJumper-3_P1.3mm_Open_RoundedPad1.0x1.5mm
R1, R2, R3: 10k; R_0402_1005Metric; MPN1 RC0402JR-0710KL
R4, R5, R6: 0; R_0402_1005Metric; MPN1 RC0402JR-070RL
SW1: BOOT; SW_Push_1P1T_NO_CK_KMR2; MPN1 KMR2
SW2: RESET; SW_Push_1P1T_NO_CK_KMR2; MPN1 KMR2
U1: ESP32-C6-MINI-1/U; ESP32-C6-MINI-1; MPN1 ESP32-C6-MINI-1
U2: USBLC6-2SC6; SOT-23-6; MPN1 USBLC6-2SC6
U3: AP2112K-3.3; SOT-23-5; MPN1 AP2112K-3.3TRG1
U4: LM66200; SOT-583-8; MPN1 LM66200

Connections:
+3.3V: C1.1, C2.1, C3.1, FB1.2, R1.2, R2.2, R3.2, U1.3 (3V3)
+5V: C4.1, C5.1, J1.1 (VBUS), U2.5 (VBUS), U3.1 (VIN), U3.3 (EN)
+BATT: J3.7
/3V3_REG: C6.1, U3.5 (VOUT), U4.6 (VIN2)
/3V3_TC: C7.1, C8.1, J3.2, J4.1, J5.2, U4.3 (VIN1)
/ESP_EN: C9.1, R3.1, SW2.1, U1.8 (EN/CHIP_PU)
/ESP_U0_RXD: J2.2, U1.30 (U0RXD/GPIO17)
/ESP_U0_TXD: J2.3, U1.31 (U0TXD/GPIO16)
/ESP_USB_D+: U1.18 (GPIO13/USB_D+), U2.4 (I/O2)
/ESP_USB_D-: U1.17 (GPIO12/USB_D-), U2.6 (I/O1)
/GPIO0: J3.4, J4.6, U1.12 (GPIO0/ADC1_CH0/XTAL_32K_P)
/GPIO1: J3.5, J4.8, U1.13 (GPIO1/ADC1_CH1/XTAL_32K_N)
/GPIO2: JP1.2 (C), U1.5 (GPIO2/ADC1_CH2)
/GPIO3: JP2.2 (C), U1.6 (GPIO3/ADC1_CH3)
/GPIO4: JP3.2 (C), U1.9 (MTMS/GPIO4/ADC1_CH4)
/GPIO5: R6.1, U1.10 (MTDI/GPIO5/ADC1_CH5)
/GPIO6: JP4.2 (C), U1.15 (MTCK/GPIO6/ADC1_CH6)
/GPIO7: J5.16, U1.16 (MTDO/GPIO7)
/GPIO8: R2.1, R4.1, U1.22 (GPIO8)
/GPIO9: R1.1, R5.1, SW1.1, U1.23 (GPIO9)
/GPIO14: J6.4, U1.19 (GPIO14)
/GPIO15: J6.3, U1.20 (GPIO15)
/GPIO18: J6.6, U1.24 (GPIO18)
/GPIO19: J6.5, U1.25 (GPIO19)
/GPIO20: J6.8, U1.26 (GPIO20)
/GPIO21: J6.7, U1.27 (GPIO21)
/GPIO22: J6.10, U1.28 (GPIO22)
/GPIO23: J6.9, U1.29 (GPIO23)
/SQW: JP3.1 (A), JP5.2 (C)
/SQW_IN: J5.14, JP5.1 (A)
/SQW_OUT_GPS: J3.1, JP5.3 (B)
/ST: U4.8 (ST)
/STM32_BOOT0: J4.7, JP2.1 (A)
/STM32_NRST: J4.10, R6.2
/STM32_SWCLK: J4.4, R5.2
/STM32_SWDIO: J4.2, R4.2
/USB_D+: J1.3 (D+), U2.3 (I/O2)
/USB_D-: J1.2 (D-), U2.1 (I/O1)
GND: C1.2, C2.2, C3.2, C4.2, C5.2, C6.2, C7.2, C8.2, C9.2, J1.5 (GND), J1.6 (Shield), J2.1, J3.3, J4.3, J4.5, J5.1, J6.1, SW1.2, SW2.2, U1.1 (GND), U1.2 (GND), U1.11 (GND), U1.14 (GND), U1.36 (GND), U1.37 (GND), U1.38 (GND), U1.39 (GND), U1.40 (GND), U1.41 (GND), U1.42 (GND), U1.43 (GND), U1.44 (GND), U1.45 (GND), U1.46 (GND), U1.47 (GND), U1.48 (GND), U1.49 (GND), U1.50 (GND), U1.51 (GND), U1.52 (GND), U1.53 (GND), U2.2 (GND), U3.2 (GND), U4.1 (GND), U4.4 (~ON), U4.5 (GND)
unnamed: FB1.1, U4.2 (VOUT), U4.7 (VOUT)
STM32_PA9: J5.4, JP2.3 (B)
STM32_PA15: J5.6, JP3.3 (B)
STM32_PB5: J5.8
STM32_PB6: J5.3
STM32_PB7: J5.7
STM32_PB8: J5.10, JP1.1 (A)
STM32_PB9: J5.12, JP4.1 (A)
STM32_PB15: J5.11, JP1.3 (B)
STM32_PC1: J5.13
STM32_PC4: J5.15, JP4.3 (B)
STM32_PC9: J5.9
STM32_PD2: J5.5

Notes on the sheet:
Regulator
ESP32 module bypass capacitors
ESP32-C6
USB Port
ESP32-C6 Strapping Pull-ups
USB ESD Protection

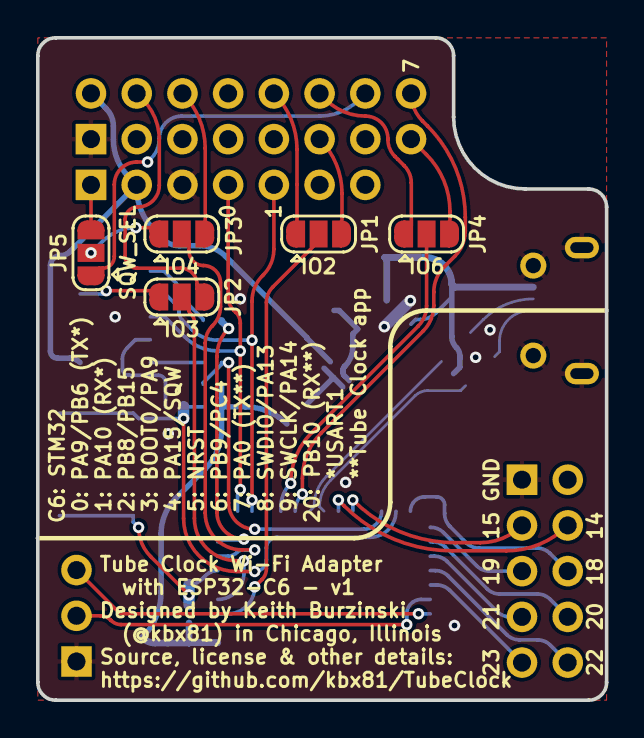
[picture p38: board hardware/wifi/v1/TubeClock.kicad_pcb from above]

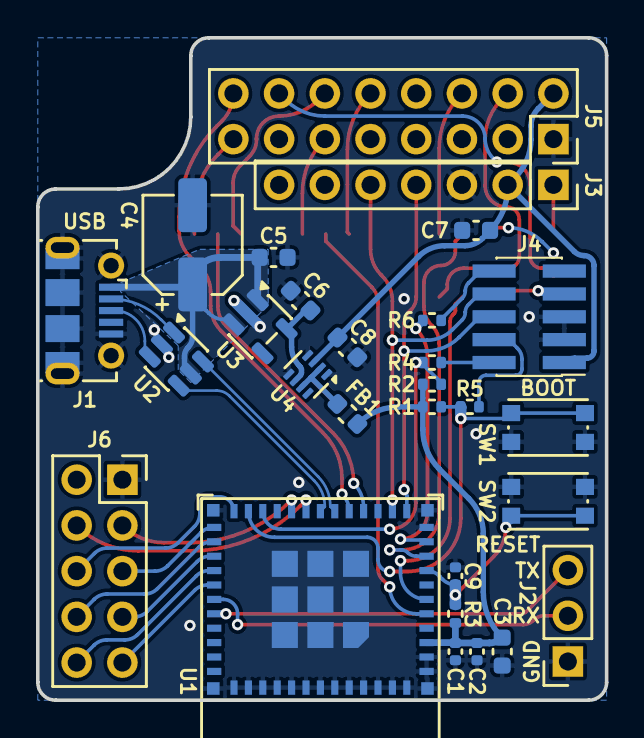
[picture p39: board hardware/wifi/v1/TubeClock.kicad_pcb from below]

Board: 2 copper layers, 31.6 x 36.8 mm, 33 parts (28 on the bottom side), 44 nets.

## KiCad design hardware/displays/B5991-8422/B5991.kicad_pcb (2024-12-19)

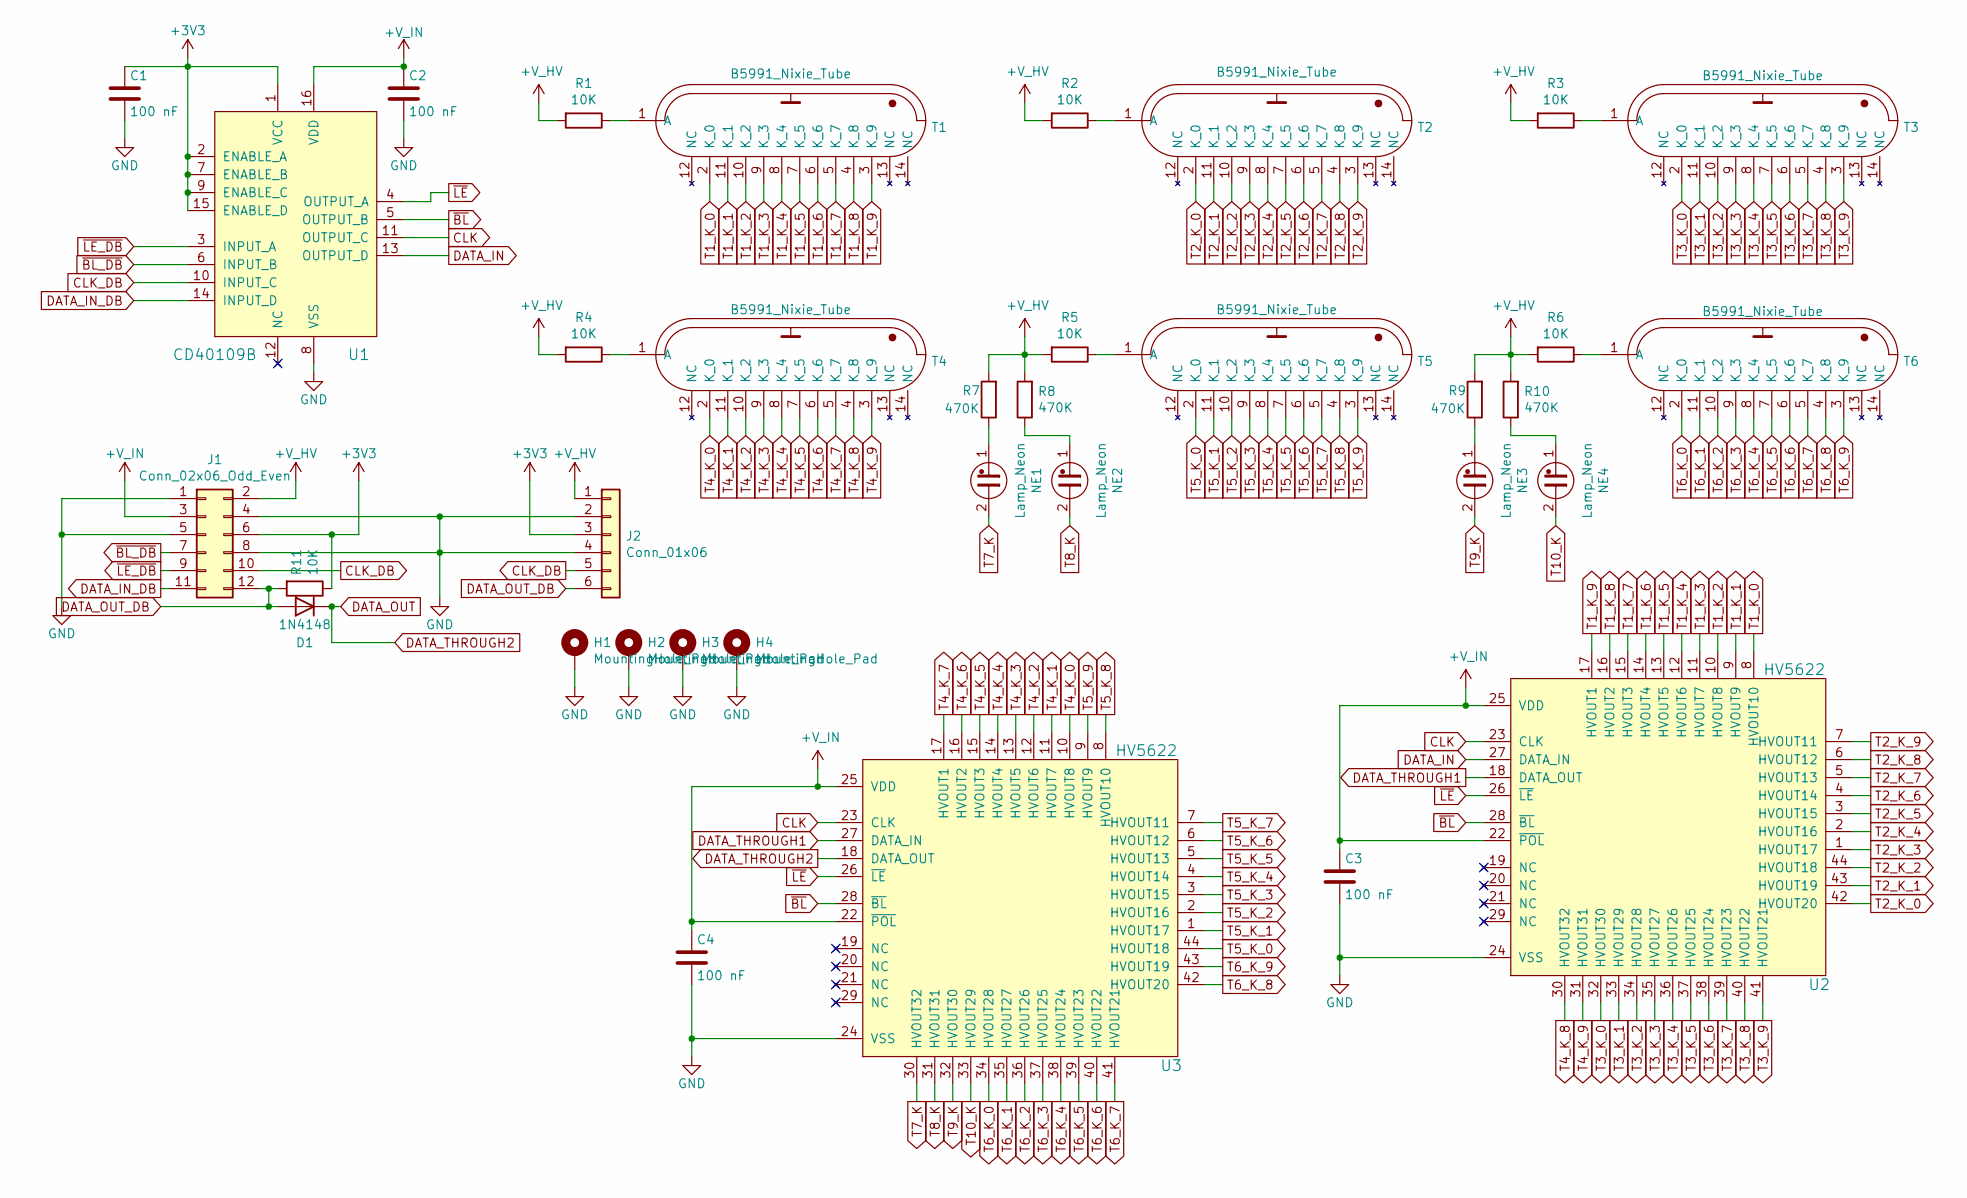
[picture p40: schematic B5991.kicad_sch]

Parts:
C1, C2, C3, C4: 100 nF; C_0805_2012Metric
D1: 1N4148; D_SOD-123
H1, H2, H3, H4: MountingHole_Pad; MountingHole_3.2mm_M3_Pad_Via
J1: Conn_02x06_Odd_Even; PinSocket_2x06_P2.54mm_Vertical
J2: Conn_01x06; PinSocket_1x06_P2.54mm_Vertical
NE1, NE2, NE3, NE4: Lamp_Neon; PinSocket_1x02_P2.54mm_Vertical
R1, R2, R3, R4, R5, R6: 10K; R_1206_3216Metric
R7, R8, R9, R10: 470K; R_1206_3216Metric
R11: 10K; R_0805_2012Metric
T1, T2, T3, T4, T5, T6: B5991_Nixie_Tube; Nixie_B5991
U1: CD40109B; SOIC-16W_5.3x10.2mm_P1.27mm
U2, U3: HV5622; PLCC-44_16.6x16.6mm_P1.27mm

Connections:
+3V3: C1.1, J1.6, J2.3, R11.1, U1.1 (VCC), U1.2 (ENABLE_A), U1.7 (ENABLE_B), U1.9 (ENABLE_C), U1.15 (ENABLE_D)
+V_HV: J1.2, J2.1, R1.2, R2.2, R3.2, R4.2, R5.2, R6.2, R7.2, R8.2, R9.2, R10.2
+V_IN: C2.1, C3.1, C4.1, J1.3, U1.16 (VDD), U2.22 (~POL), U2.25 (VDD), U3.22 (~POL), U3.25 (VDD)
CLK: U1.11 (OUTPUT_C), U2.23 (CLK), U3.23 (CLK)
CLK_DB: J1.10, J2.5, U1.10 (INPUT_C)
DATA_IN: U1.13 (OUTPUT_D), U2.27 (DATA_IN)
DATA_IN_DB: J1.11, U1.14 (INPUT_D)
DATA_OUT: D1.1 (K), U3.18 (DATA_OUT)
DATA_OUT_DB: D1.2 (A), J1.12, J2.6, R11.2
DATA_THROUGH1: U2.18 (DATA_OUT), U3.27 (DATA_IN)
GND: C1.2, C2.2, C3.2, C4.2, H1.1, H2.1, H3.1, H4.1, J1.1, J1.4, J1.5, J1.8, J2.2, J2.4, U1.8 (VSS), U2.24 (VSS), U3.24 (VSS)
unnamed: NE1.1, R7.1
unnamed: NE2.1, R8.1
unnamed: NE3.1, R9.1
unnamed: NE4.1, R10.1
unnamed: R1.1, T1.1 (A)
unnamed: R2.1, T2.1 (A)
unnamed: R3.1, T3.1 (A)
unnamed: R4.1, T4.1 (A)
unnamed: R5.1, T5.1 (A)
unnamed: R6.1, T6.1 (A)
T1_K_0: T1.2 (K_0), U2.8 (HVOUT10)
T1_K_1: T1.11 (K_1), U2.9 (HVOUT9)
T1_K_2: T1.10 (K_2), U2.10 (HVOUT8)
T1_K_3: T1.9 (K_3), U2.11 (HVOUT7)
T1_K_4: T1.8 (K_4), U2.12 (HVOUT6)
T1_K_5: T1.7 (K_5), U2.13 (HVOUT5)
T1_K_6: T1.6 (K_6), U2.14 (HVOUT4)
T1_K_7: T1.5 (K_7), U2.15 (HVOUT3)
T1_K_8: T1.4 (K_8), U2.16 (HVOUT2)
T1_K_9: T1.3 (K_9), U2.17 (HVOUT1)
T2_K_0: T2.2 (K_0), U2.42 (HVOUT20)
T2_K_1: T2.11 (K_1), U2.43 (HVOUT19)
T2_K_2: T2.10 (K_2), U2.44 (HVOUT18)
T2_K_3: T2.9 (K_3), U2.1 (HVOUT17)
T2_K_4: T2.8 (K_4), U2.2 (HVOUT16)
T2_K_5: T2.7 (K_5), U2.3 (HVOUT15)
T2_K_6: T2.6 (K_6), U2.4 (HVOUT14)
T2_K_7: T2.5 (K_7), U2.5 (HVOUT13)
T2_K_8: T2.4 (K_8), U2.6 (HVOUT12)
T2_K_9: T2.3 (K_9), U2.7 (HVOUT11)
T3_K_0: T3.2 (K_0), U2.32 (HVOUT30)
T3_K_1: T3.11 (K_1), U2.33 (HVOUT29)
T3_K_2: T3.10 (K_2), U2.34 (HVOUT28)
T3_K_3: T3.9 (K_3), U2.35 (HVOUT27)
T3_K_4: T3.8 (K_4), U2.36 (HVOUT26)
T3_K_5: T3.7 (K_5), U2.37 (HVOUT25)
T3_K_6: T3.6 (K_6), U2.38 (HVOUT24)
T3_K_7: T3.5 (K_7), U2.39 (HVOUT23)
T3_K_8: T3.4 (K_8), U2.40 (HVOUT22)
T3_K_9: T3.3 (K_9), U2.41 (HVOUT21)
T4_K_0: T4.2 (K_0), U3.10 (HVOUT8)
T4_K_1: T4.11 (K_1), U3.11 (HVOUT7)
T4_K_2: T4.10 (K_2), U3.12 (HVOUT6)
T4_K_3: T4.9 (K_3), U3.13 (HVOUT5)
T4_K_4: T4.8 (K_4), U3.14 (HVOUT4)
T4_K_5: T4.7 (K_5), U3.15 (HVOUT3)
T4_K_6: T4.6 (K_6), U3.16 (HVOUT2)
T4_K_7: T4.5 (K_7), U3.17 (HVOUT1)
T4_K_8: T4.4 (K_8), U2.30 (HVOUT32)
T4_K_9: T4.3 (K_9), U2.31 (HVOUT31)
T5_K_0: T5.2 (K_0), U3.44 (HVOUT18)
T5_K_1: T5.11 (K_1), U3.1 (HVOUT17)
T5_K_2: T5.10 (K_2), U3.2 (HVOUT16)
T5_K_3: T5.9 (K_3), U3.3 (HVOUT15)
T5_K_4: T5.8 (K_4), U3.4 (HVOUT14)
T5_K_5: T5.7 (K_5), U3.5 (HVOUT13)
T5_K_6: T5.6 (K_6), U3.6 (HVOUT12)
T5_K_7: T5.5 (K_7), U3.7 (HVOUT11)
T5_K_8: T5.4 (K_8), U3.8 (HVOUT10)
T5_K_9: T5.3 (K_9), U3.9 (HVOUT9)
T6_K_0: T6.2 (K_0), U3.34 (HVOUT28)
T6_K_1: T6.11 (K_1), U3.35 (HVOUT27)
T6_K_2: T6.10 (K_2), U3.36 (HVOUT26)
T6_K_3: T6.9 (K_3), U3.37 (HVOUT25)
T6_K_4: T6.8 (K_4), U3.38 (HVOUT24)
T6_K_5: T6.7 (K_5), U3.39 (HVOUT23)
T6_K_6: T6.6 (K_6), U3.40 (HVOUT22)
T6_K_7: T6.5 (K_7), U3.41 (HVOUT21)
T6_K_8: T6.4 (K_8), U3.42 (HVOUT20)
T6_K_9: T6.3 (K_9), U3.43 (HVOUT19)
T7_K: NE1.2, U3.30 (HVOUT32)
T8_K: NE2.2, U3.31 (HVOUT31)
T9_K: NE3.2, U3.32 (HVOUT30)
T10_K: NE4.2, U3.33 (HVOUT29)
~BL_DB: J1.7, U1.6 (INPUT_B)
~BL: U1.5 (OUTPUT_B), U2.28 (~BL), U3.28 (~BL)
~LE_DB: J1.9, U1.3 (INPUT_A)
~LE: U1.4 (OUTPUT_A), U2.26 (~LE), U3.26 (~LE)

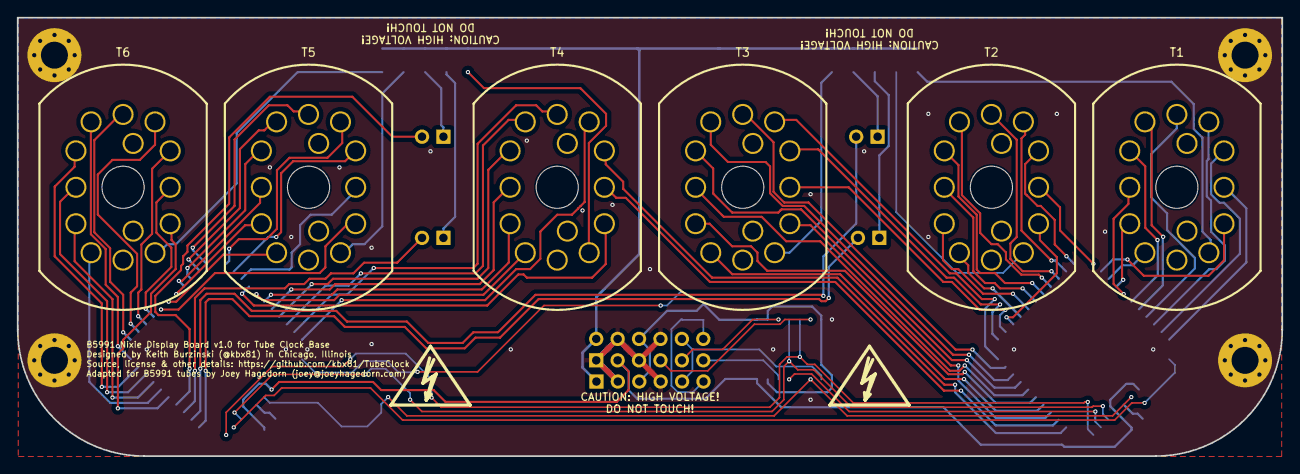
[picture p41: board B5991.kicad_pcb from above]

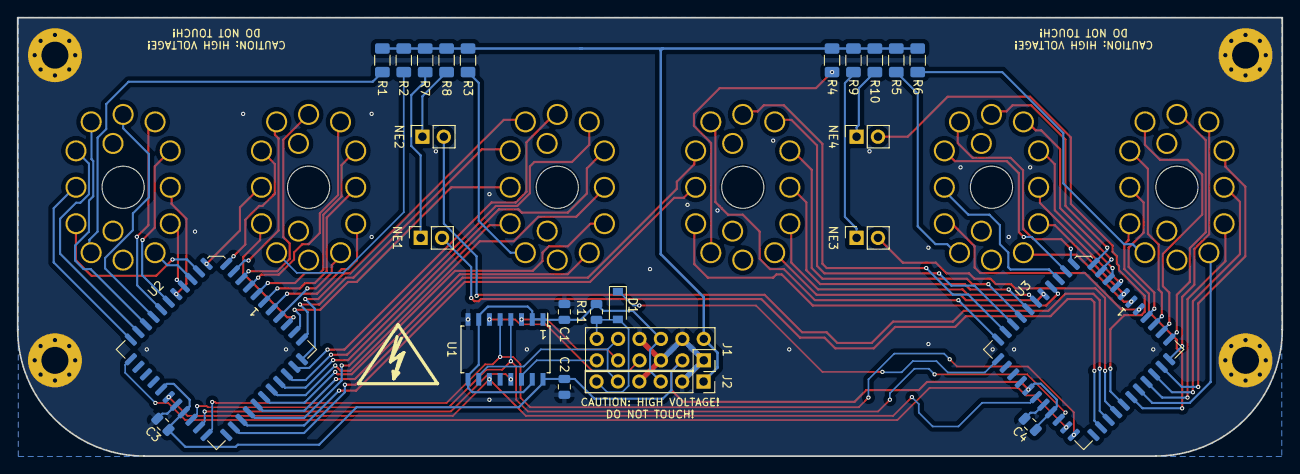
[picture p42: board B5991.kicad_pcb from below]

Board: 2 copper layers, 150.0 x 52.0 mm, 35 parts (25 on the bottom side), 89 nets.

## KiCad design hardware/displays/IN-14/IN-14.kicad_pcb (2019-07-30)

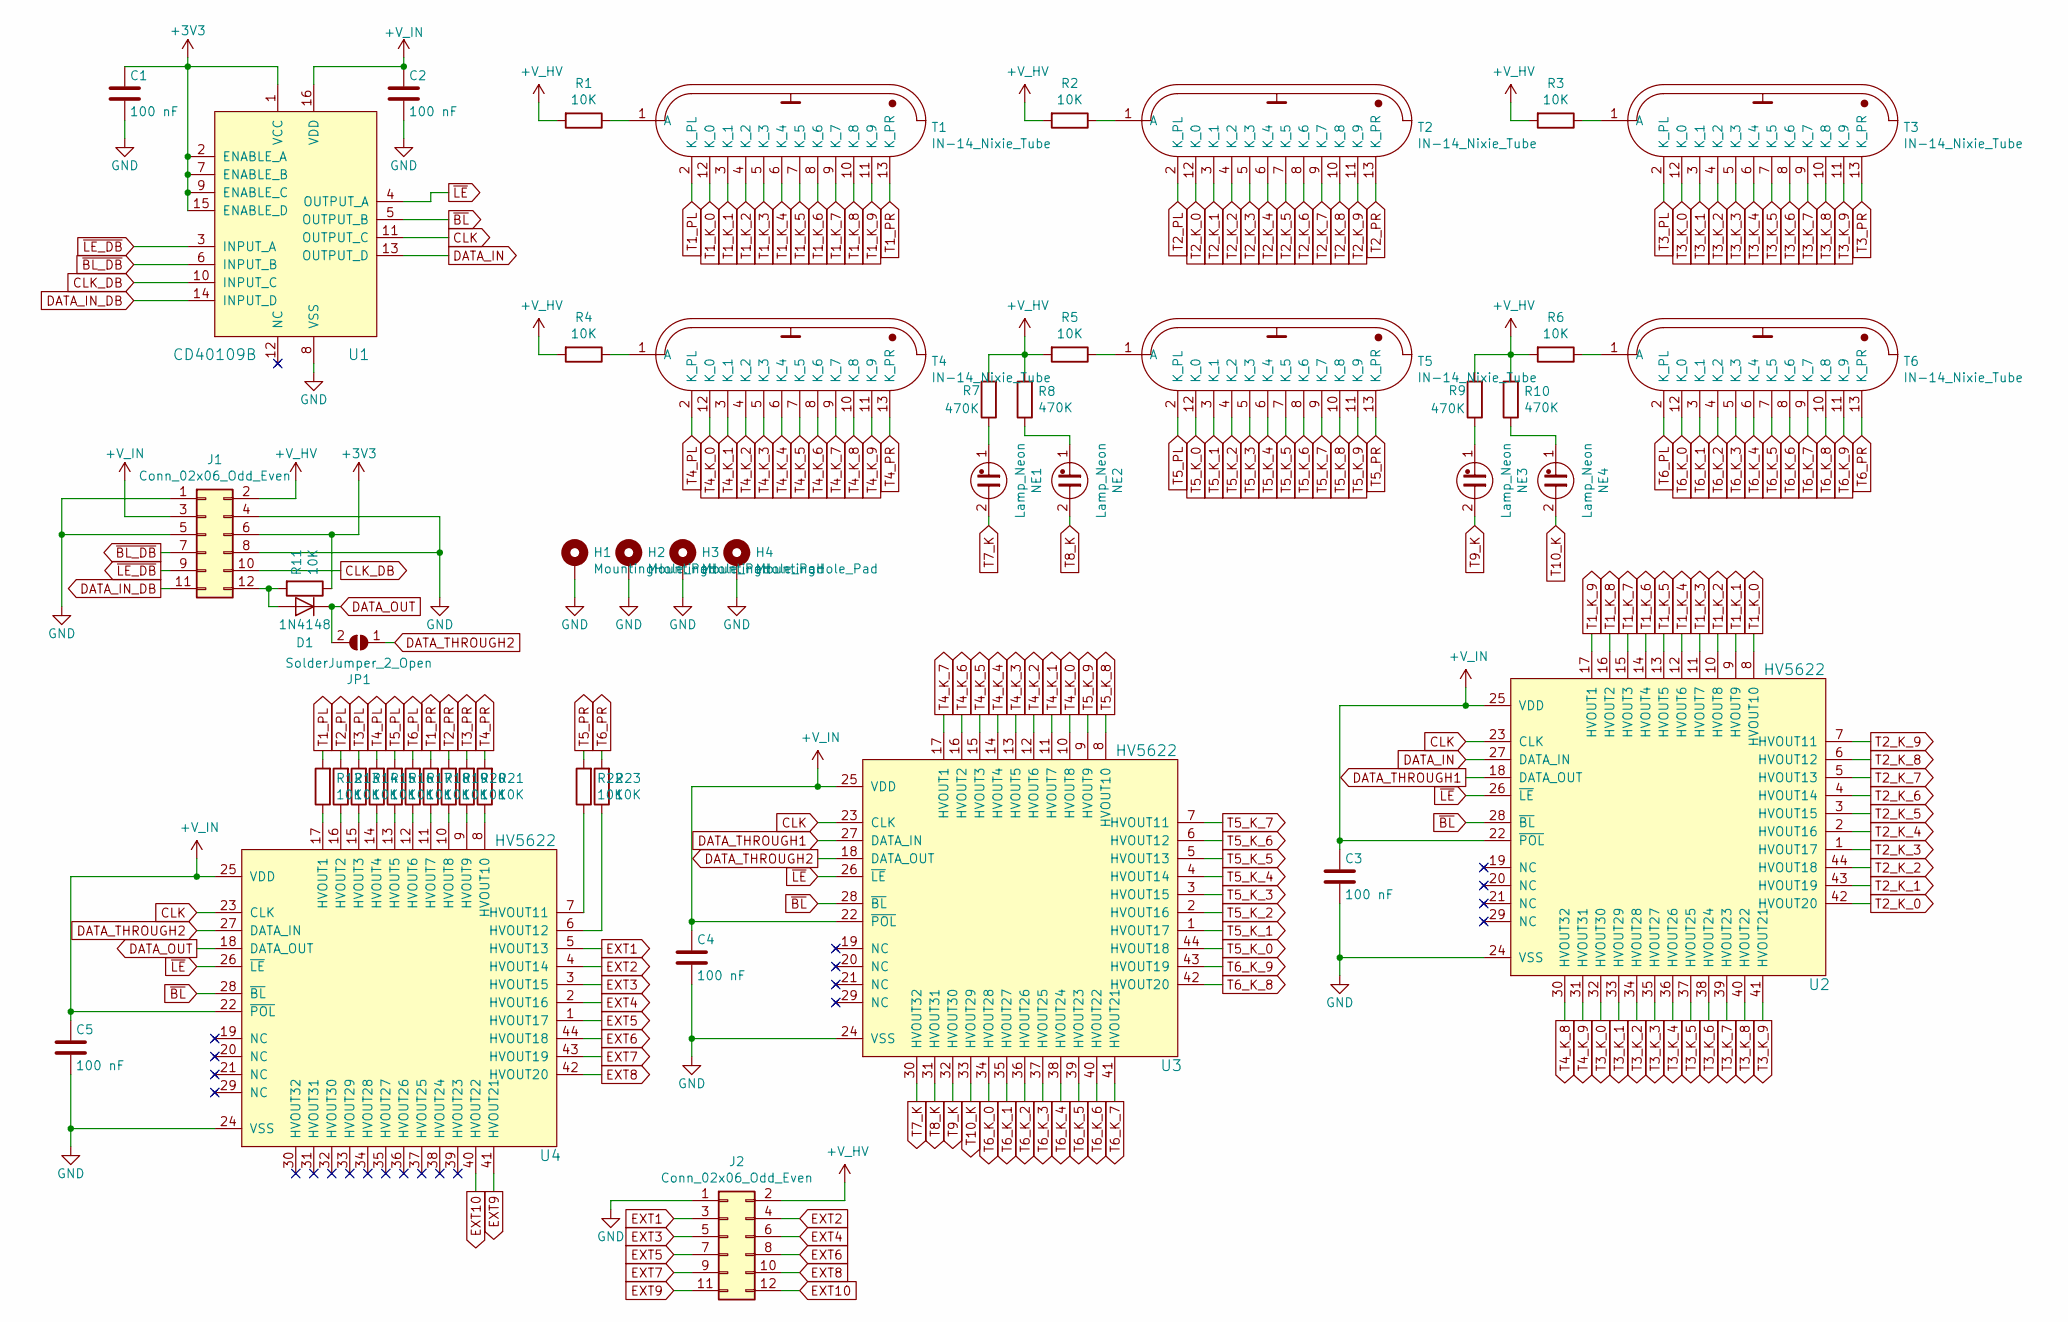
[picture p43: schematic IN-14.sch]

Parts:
C1, C2, C3, C4, C5: 100 nF; C_0805_2012Metric
D1: 1N4148; D_SOD-123
H1, H2, H3, H4: MountingHole_Pad; MountingHole_3.2mm_M3_Pad_Via
J1: Conn_02x06_Odd_Even; PinSocket_2x06_P2.54mm_Vertical
J2: Conn_02x06_Odd_Even; PinHeader_2x06_P2.54mm_Vertical
JP1: SolderJumper_2_Open; SolderJumper-2_P1.3mm_Open_Pad1.0x1.5mm
NE1, NE2, NE3, NE4: Lamp_Neon; PinHeader_1x02_P2.54mm_Vertical
R1, R2, R3, R4, R5, R6: 10K; R_1206_3216Metric
R7, R8, R9, R10: 470K; R_1206_3216Metric
R11, R12, R13, R14, R15, R16, R17, R18, R19, R20, R21, R22, R23: 10K; R_0805_2012Metric
T1, T2, T3, T4, T5, T6: IN-14_Nixie_Tube; Nixie_IN-14
U1: CD40109B; SOIC-16W_5.3x10.2mm_P1.27mm
U2, U3, U4: HV5622; PLCC-44_16.6x16.6mm_P1.27mm

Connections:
+3V3: C1.1, J1.6, R11.1, U1.1 (VCC), U1.2 (ENABLE_A), U1.7 (ENABLE_B), U1.9 (ENABLE_C), U1.15 (ENABLE_D)
+V_HV: J1.2, J2.2, R1.2, R2.2, R3.2, R4.2, R5.2, R6.2, R7.2, R8.2, R9.2, R10.2
+V_IN: C2.1, C3.1, C4.1, C5.1, J1.3, U1.16 (VDD), U2.22 (~POL~), U2.25 (VDD), U3.22 (~POL~), U3.25 (VDD), U4.22 (~POL~), U4.25 (VDD)
CLK: U1.11 (OUTPUT_C), U2.23 (CLK), U3.23 (CLK), U4.23 (CLK)
CLK_DB: J1.10, U1.10 (INPUT_C)
DATA_IN: U1.13 (OUTPUT_D), U2.27 (DATA_IN)
DATA_IN_DB: J1.11, U1.14 (INPUT_D)
DATA_OUT: D1.1 (K), JP1.2 (B), U4.18 (DATA_OUT)
DATA_THROUGH1: U2.18 (DATA_OUT), U3.27 (DATA_IN)
DATA_THROUGH2: JP1.1 (A), U3.18 (DATA_OUT), U4.27 (DATA_IN)
EXT1: J2.3, U4.5 (HVOUT13)
EXT2: J2.4, U4.4 (HVOUT14)
EXT3: J2.5, U4.3 (HVOUT15)
EXT4: J2.6, U4.2 (HVOUT16)
EXT5: J2.7, U4.1 (HVOUT17)
EXT6: J2.8, U4.44 (HVOUT18)
EXT7: J2.9, U4.43 (HVOUT19)
EXT8: J2.10, U4.42 (HVOUT20)
EXT9: J2.11, U4.41 (HVOUT21)
EXT10: J2.12, U4.40 (HVOUT22)
GND: C1.2, C2.2, C3.2, C4.2, C5.2, H1.1, H2.1, H3.1, H4.1, J1.1, J1.4, J1.5, J1.8, J2.1, U1.8 (VSS), U2.24 (VSS), U3.24 (VSS), U4.24 (VSS)
unnamed: D1.2 (A), J1.12, R11.2
unnamed: NE1.1, R7.1
unnamed: NE2.1, R8.1
unnamed: NE3.1, R9.1
unnamed: NE4.1, R10.1
unnamed: R1.1, T1.1 (A)
unnamed: R2.1, T2.1 (A)
unnamed: R3.1, T3.1 (A)
unnamed: R4.1, T4.1 (A)
unnamed: R5.1, T5.1 (A)
unnamed: R6.1, T6.1 (A)
unnamed: R12.1, U4.17 (HVOUT1)
unnamed: R13.1, U4.16 (HVOUT2)
unnamed: R14.1, U4.15 (HVOUT3)
unnamed: R15.1, U4.14 (HVOUT4)
unnamed: R16.1, U4.13 (HVOUT5)
unnamed: R17.1, U4.12 (HVOUT6)
unnamed: R18.1, U4.11 (HVOUT7)
unnamed: R19.1, U4.10 (HVOUT8)
unnamed: R20.1, U4.9 (HVOUT9)
unnamed: R21.1, U4.8 (HVOUT10)
unnamed: R22.1, U4.7 (HVOUT11)
unnamed: R23.1, U4.6 (HVOUT12)
T1_K_0: T1.12 (K_0), U2.8 (HVOUT10)
T1_K_1: T1.3 (K_1), U2.9 (HVOUT9)
T1_K_2: T1.4 (K_2), U2.10 (HVOUT8)
T1_K_3: T1.5 (K_3), U2.11 (HVOUT7)
T1_K_4: T1.6 (K_4), U2.12 (HVOUT6)
T1_K_5: T1.7 (K_5), U2.13 (HVOUT5)
T1_K_6: T1.8 (K_6), U2.14 (HVOUT4)
T1_K_7: T1.9 (K_7), U2.15 (HVOUT3)
T1_K_8: T1.10 (K_8), U2.16 (HVOUT2)
T1_K_9: T1.11 (K_9), U2.17 (HVOUT1)
T1_PL: R12.2, T1.2 (K_PL)
T1_PR: R18.2, T1.13 (K_PR)
T2_K_0: T2.12 (K_0), U2.42 (HVOUT20)
T2_K_1: T2.3 (K_1), U2.43 (HVOUT19)
T2_K_2: T2.4 (K_2), U2.44 (HVOUT18)
T2_K_3: T2.5 (K_3), U2.1 (HVOUT17)
T2_K_4: T2.6 (K_4), U2.2 (HVOUT16)
T2_K_5: T2.7 (K_5), U2.3 (HVOUT15)
T2_K_6: T2.8 (K_6), U2.4 (HVOUT14)
T2_K_7: T2.9 (K_7), U2.5 (HVOUT13)
T2_K_8: T2.10 (K_8), U2.6 (HVOUT12)
T2_K_9: T2.11 (K_9), U2.7 (HVOUT11)
T2_PL: R13.2, T2.2 (K_PL)
T2_PR: R19.2, T2.13 (K_PR)
T3_K_0: T3.12 (K_0), U2.32 (HVOUT30)
T3_K_1: T3.3 (K_1), U2.33 (HVOUT29)
T3_K_2: T3.4 (K_2), U2.34 (HVOUT28)
T3_K_3: T3.5 (K_3), U2.35 (HVOUT27)
T3_K_4: T3.6 (K_4), U2.36 (HVOUT26)
T3_K_5: T3.7 (K_5), U2.37 (HVOUT25)
T3_K_6: T3.8 (K_6), U2.38 (HVOUT24)
T3_K_7: T3.9 (K_7), U2.39 (HVOUT23)
T3_K_8: T3.10 (K_8), U2.40 (HVOUT22)
T3_K_9: T3.11 (K_9), U2.41 (HVOUT21)
T3_PL: R14.2, T3.2 (K_PL)
T3_PR: R20.2, T3.13 (K_PR)
T4_K_0: T4.12 (K_0), U3.10 (HVOUT8)
T4_K_1: T4.3 (K_1), U3.11 (HVOUT7)
T4_K_2: T4.4 (K_2), U3.12 (HVOUT6)
T4_K_3: T4.5 (K_3), U3.13 (HVOUT5)
T4_K_4: T4.6 (K_4), U3.14 (HVOUT4)
T4_K_5: T4.7 (K_5), U3.15 (HVOUT3)
T4_K_6: T4.8 (K_6), U3.16 (HVOUT2)
T4_K_7: T4.9 (K_7), U3.17 (HVOUT1)
T4_K_8: T4.10 (K_8), U2.30 (HVOUT32)
T4_K_9: T4.11 (K_9), U2.31 (HVOUT31)
T4_PL: R15.2, T4.2 (K_PL)
T4_PR: R21.2, T4.13 (K_PR)
T5_K_0: T5.12 (K_0), U3.44 (HVOUT18)
T5_K_1: T5.3 (K_1), U3.1 (HVOUT17)
T5_K_2: T5.4 (K_2), U3.2 (HVOUT16)
T5_K_3: T5.5 (K_3), U3.3 (HVOUT15)
T5_K_4: T5.6 (K_4), U3.4 (HVOUT14)
T5_K_5: T5.7 (K_5), U3.5 (HVOUT13)
T5_K_6: T5.8 (K_6), U3.6 (HVOUT12)
T5_K_7: T5.9 (K_7), U3.7 (HVOUT11)
T5_K_8: T5.10 (K_8), U3.8 (HVOUT10)
T5_K_9: T5.11 (K_9), U3.9 (HVOUT9)
T5_PL: R16.2, T5.2 (K_PL)
T5_PR: R22.2, T5.13 (K_PR)
T6_K_0: T6.12 (K_0), U3.34 (HVOUT28)
T6_K_1: T6.3 (K_1), U3.35 (HVOUT27)
T6_K_2: T6.4 (K_2), U3.36 (HVOUT26)
T6_K_3: T6.5 (K_3), U3.37 (HVOUT25)
T6_K_4: T6.6 (K_4), U3.38 (HVOUT24)
T6_K_5: T6.7 (K_5), U3.39 (HVOUT23)
T6_K_6: T6.8 (K_6), U3.40 (HVOUT22)
T6_K_7: T6.9 (K_7), U3.41 (HVOUT21)
T6_K_8: T6.10 (K_8), U3.42 (HVOUT20)
T6_K_9: T6.11 (K_9), U3.43 (HVOUT19)
T6_PL: R17.2, T6.2 (K_PL)
T6_PR: R23.2, T6.13 (K_PR)
T7_K: NE1.2, U3.30 (HVOUT32)
T8_K: NE2.2, U3.31 (HVOUT31)
T9_K: NE3.2, U3.32 (HVOUT30)
T10_K: NE4.2, U3.33 (HVOUT29)
~BL_DB~: J1.7, U1.6 (INPUT_B)
~BL~: U1.5 (OUTPUT_B), U2.28 (~BL~), U3.28 (~BL~), U4.28 (~BL~)
~LE_DB~: J1.9, U1.3 (INPUT_A)
~LE~: U1.4 (OUTPUT_A), U2.26 (~LE~), U3.26 (~LE~), U4.26 (~LE~)

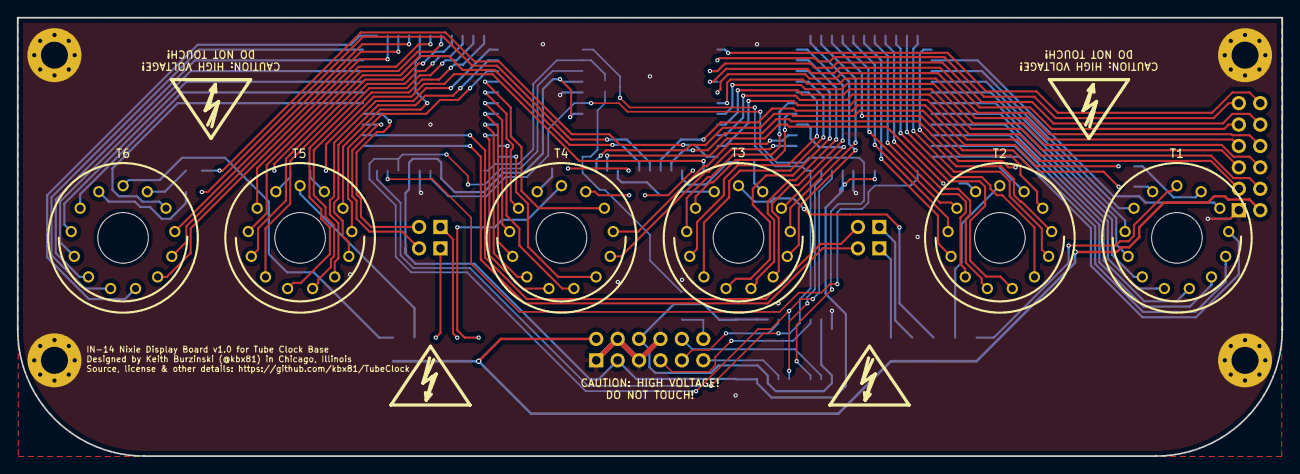
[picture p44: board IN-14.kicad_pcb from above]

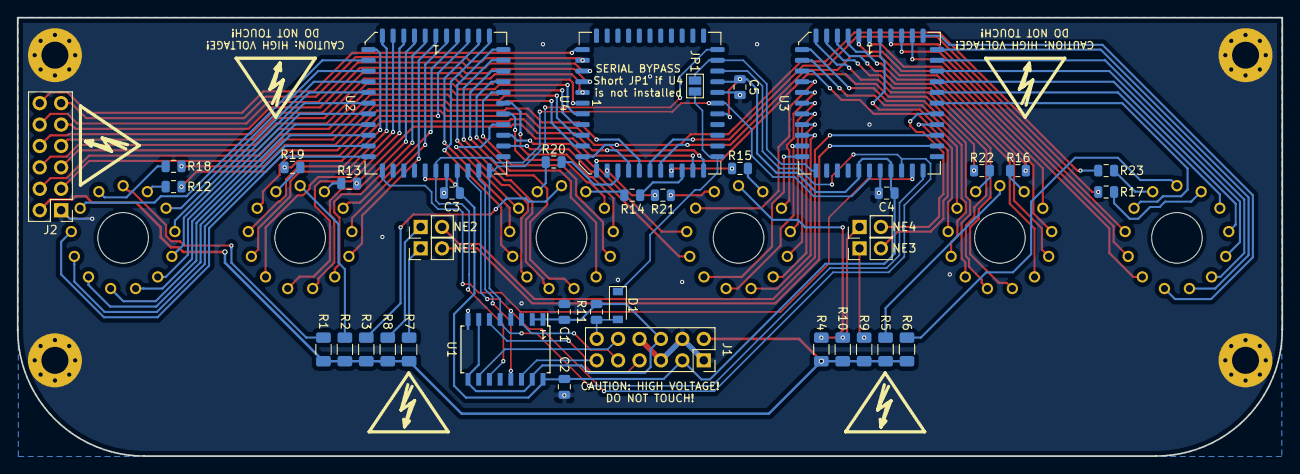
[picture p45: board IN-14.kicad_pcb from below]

Board: 2 copper layers, 150.0 x 52.0 mm, 50 parts (40 on the bottom side), 124 nets.

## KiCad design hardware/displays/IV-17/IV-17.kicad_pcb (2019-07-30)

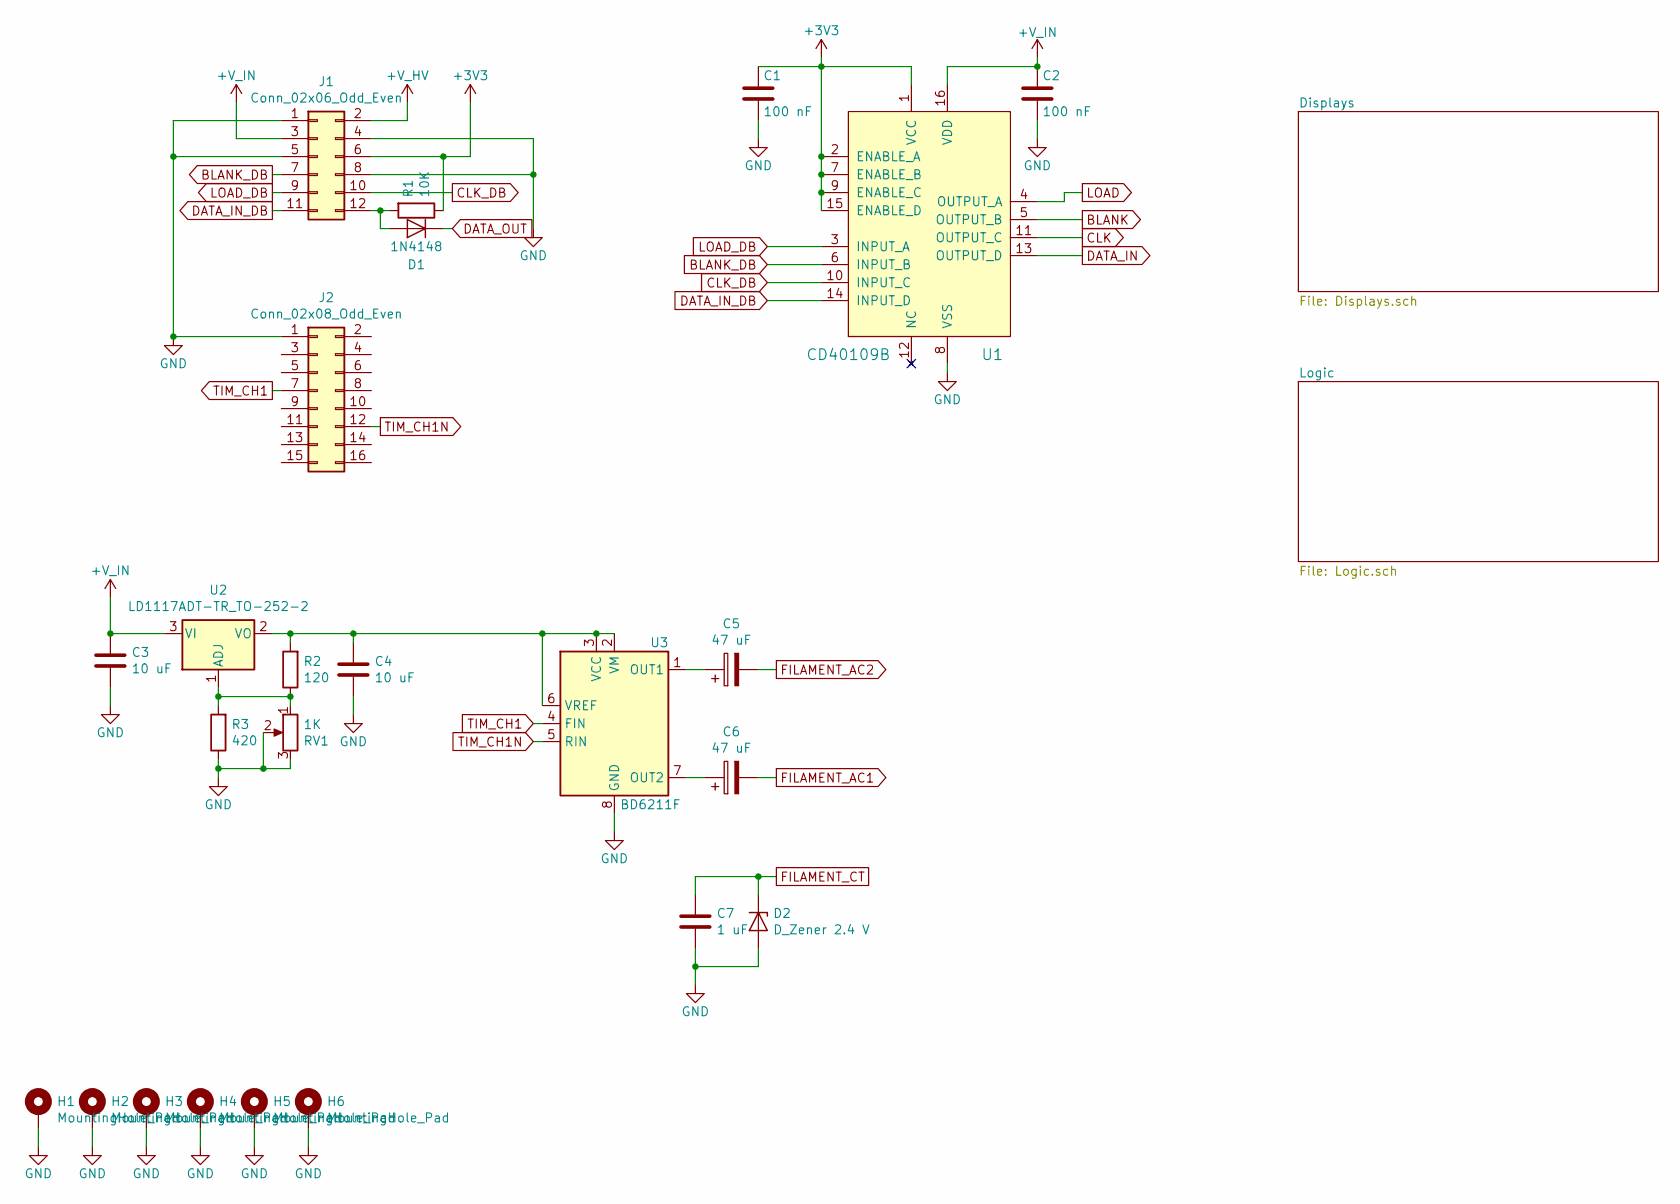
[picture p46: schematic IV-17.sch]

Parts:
C1, C2: 100 nF; C_0805_2012Metric
C3, C4: 10 uF; C_0805_2012Metric
C5, C6: 47 uF; CP_Elec_5x5.8
C7: 1 uF; C_0805_2012Metric
D1: 1N4148; D_SOD-123
D2: D_Zener 2.4 V; D_SOD-123
H1, H2, H3, H4, H5, H6: MountingHole_Pad; MountingHole_3.2mm_M3_Pad_Via
J1: Conn_02x06_Odd_Even; PinSocket_2x06_P2.54mm_Vertical
J2: Conn_02x08_Odd_Even; PinSocket_2x08_P2.54mm_Vertical
R1: 10K; R_0805_2012Metric
R2: 120; R_0805_2012Metric
R3: 420; R_0805_2012Metric
RV1: 1K; Potentiometer_Bourns_3214W_Vertical
U1: CD40109B; SOIC-16W_5.3x10.2mm_P1.27mm
U2: LD1117ADT-TR_TO-252-2; TO-252-2
U3: BD6211F; SSOP-8_3.9x5.05mm_P1.27mm

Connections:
+3V3: C1.1, J1.6, R1.1, U1.1 (VCC), U1.2 (ENABLE_A), U1.7 (ENABLE_B), U1.9 (ENABLE_C), U1.15 (ENABLE_D)
+V_HV: J1.2; also elsewhere on the board
+V_IN: C2.1, C3.1, J1.3, U1.16 (VDD), U2.3 (VI); also elsewhere on the board
BLANK: U1.5 (OUTPUT_B); also elsewhere on the board
BLANK_DB: J1.7, U1.6 (INPUT_B)
CLK: U1.11 (OUTPUT_C); also elsewhere on the board
CLK_DB: J1.10, U1.10 (INPUT_C)
DATA_IN: U1.13 (OUTPUT_D); also elsewhere on the board
DATA_IN_DB: J1.11, U1.14 (INPUT_D)
DATA_OUT: D1.1 (K); also elsewhere on the board
FILAMENT_AC1: C6.2; also elsewhere on the board
FILAMENT_AC2: C5.2; also elsewhere on the board
FILAMENT_CT: C7.1, D2.1 (K); also elsewhere on the board
GND: C1.2, C2.2, C3.2, C4.2, C7.2, D2.2 (A), H1.1, H2.1, H3.1, H4.1, H5.1, H6.1, J1.1, J1.4, J1.5, J1.8, J2.1, R3.1, RV1.2, RV1.3, U1.8 (VSS), U3.8 (GND); also elsewhere on the board
LOAD: U1.4 (OUTPUT_A); also elsewhere on the board
LOAD_DB: J1.9, U1.3 (INPUT_A)
unnamed: C4.1, R2.2, U2.2 (VO), U3.2 (VM), U3.3 (VCC), U3.6 (VREF)
unnamed: C5.1, U3.1 (OUT1)
unnamed: C6.1, U3.7 (OUT2)
unnamed: D1.2 (A), J1.12, R1.2
unnamed: R2.1, R3.2, RV1.1, U2.1 (ADJ)
TIM_CH1: J2.7, U3.4 (FIN)
TIM_CH1N: J2.12, U3.5 (RIN)

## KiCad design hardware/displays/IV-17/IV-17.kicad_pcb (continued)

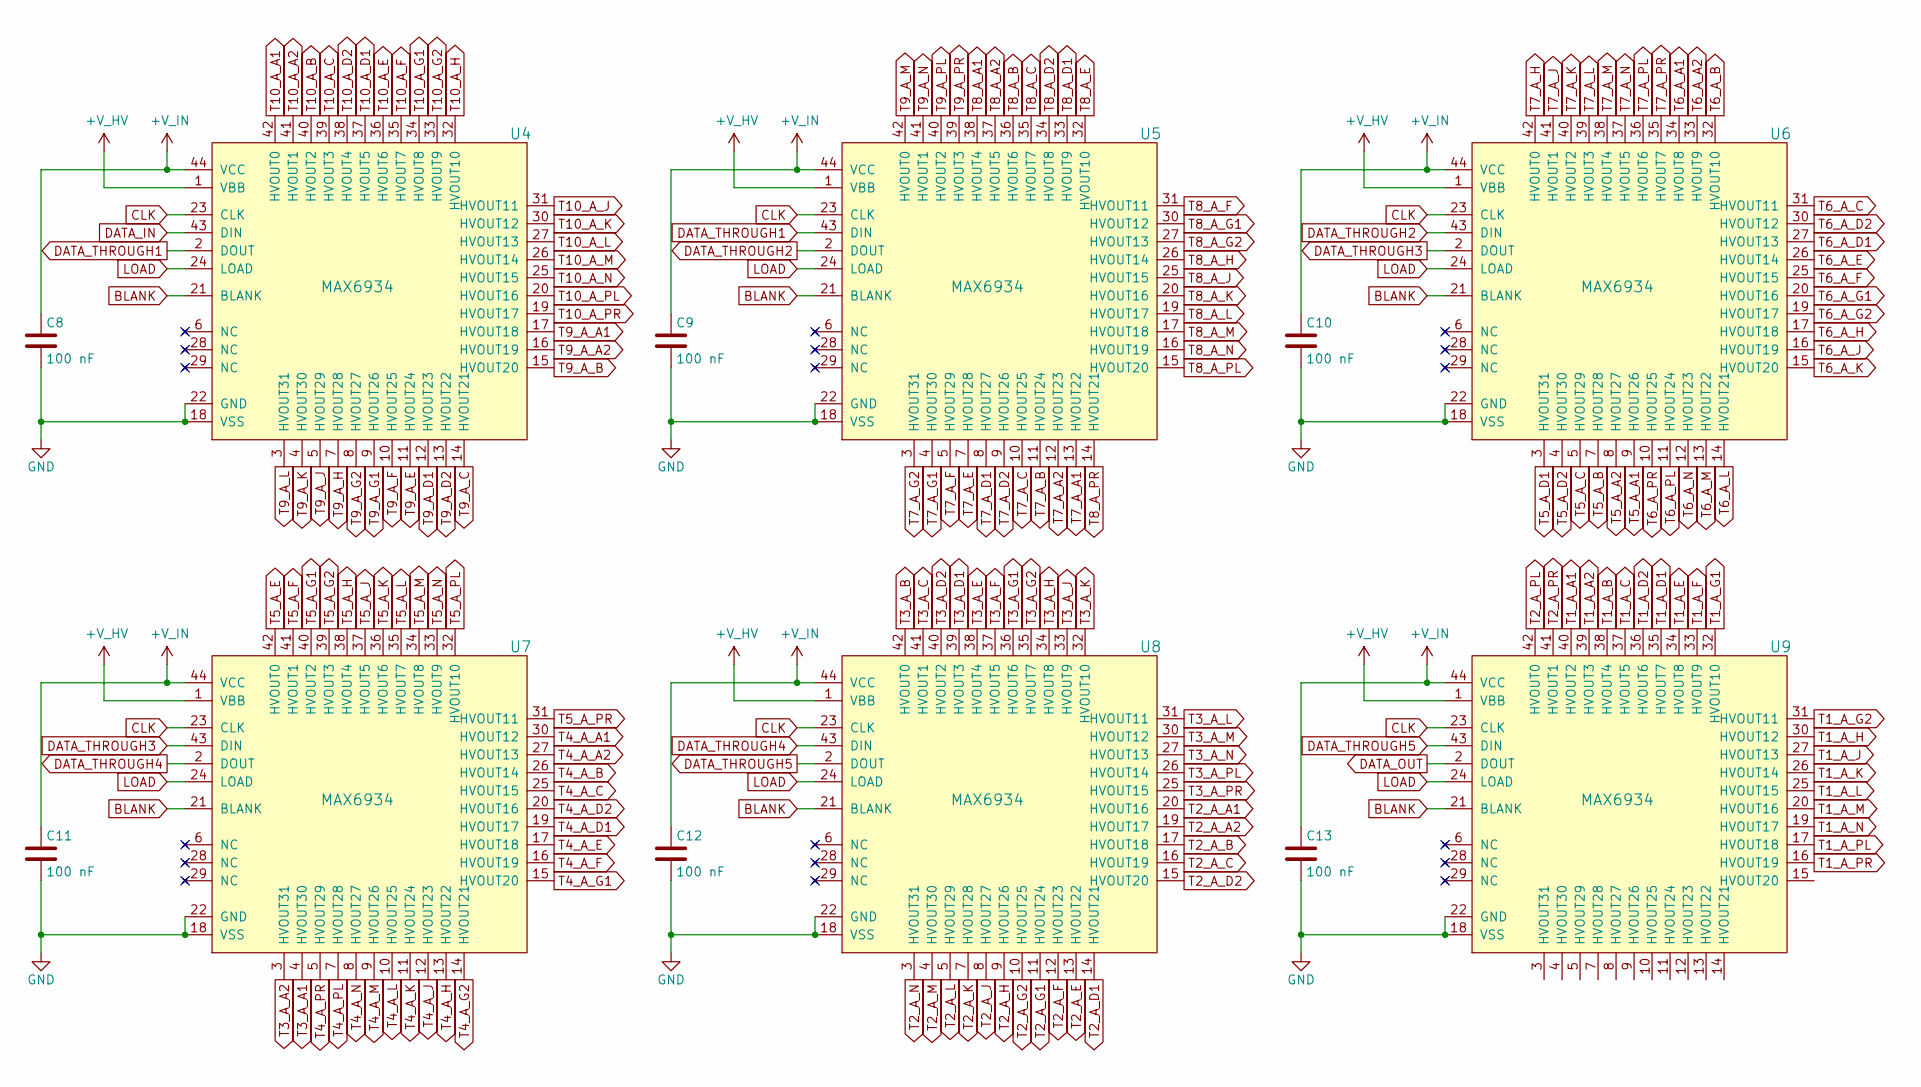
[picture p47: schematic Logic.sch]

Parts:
C8, C9, C10, C11, C12, C13: 100 nF; C_0805_2012Metric
U4, U5, U6, U7, U8, U9: MAX6934; PLCC-44_16.6x16.6mm_P1.27mm

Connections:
+V_HV: U4.1 (VBB), U5.1 (VBB), U6.1 (VBB), U7.1 (VBB), U8.1 (VBB), U9.1 (VBB); also elsewhere on the board
+V_IN: C8.1, C9.1, C10.1, C11.1, C12.1, C13.1, U4.44 (VCC), U5.44 (VCC), U6.44 (VCC), U7.44 (VCC), U8.44 (VCC), U9.44 (VCC); also elsewhere on the board
BLANK: U4.21 (BLANK), U5.21 (BLANK), U6.21 (BLANK), U7.21 (BLANK), U8.21 (BLANK), U9.21 (BLANK); also elsewhere on the board
CLK: U4.23 (CLK), U5.23 (CLK), U6.23 (CLK), U7.23 (CLK), U8.23 (CLK), U9.23 (CLK); also elsewhere on the board
DATA_IN: U4.43 (DIN); also elsewhere on the board
DATA_OUT: U9.2 (DOUT); also elsewhere on the board
DATA_THROUGH1: U4.2 (DOUT), U5.43 (DIN)
DATA_THROUGH2: U5.2 (DOUT), U6.43 (DIN)
DATA_THROUGH3: U6.2 (DOUT), U7.43 (DIN)
DATA_THROUGH4: U7.2 (DOUT), U8.43 (DIN)
DATA_THROUGH5: U8.2 (DOUT), U9.43 (DIN)
GND: C8.2, C9.2, C10.2, C11.2, C12.2, C13.2, U4.18 (VSS), U4.22 (GND), U5.18 (VSS), U5.22 (GND), U6.18 (VSS), U6.22 (GND), U7.18 (VSS), U7.22 (GND), U8.18 (VSS), U8.22 (GND), U9.18 (VSS), U9.22 (GND); also elsewhere on the board
LOAD: U4.24 (LOAD), U5.24 (LOAD), U6.24 (LOAD), U7.24 (LOAD), U8.24 (LOAD), U9.24 (LOAD); also elsewhere on the board
T1_A_A1: U9.40 (HVOUT2); also elsewhere on the board
T1_A_A2: U9.39 (HVOUT3); also elsewhere on the board
T1_A_B: U9.38 (HVOUT4); also elsewhere on the board
T1_A_C: U9.37 (HVOUT5); also elsewhere on the board
T1_A_D1: U9.35 (HVOUT7); also elsewhere on the board
T1_A_D2: U9.36 (HVOUT6); also elsewhere on the board
T1_A_E: U9.34 (HVOUT8); also elsewhere on the board
T1_A_F: U9.33 (HVOUT9); also elsewhere on the board
T1_A_G1: U9.32 (HVOUT10); also elsewhere on the board
T1_A_G2: U9.31 (HVOUT11); also elsewhere on the board
T1_A_H: U9.30 (HVOUT12); also elsewhere on the board
T1_A_J: U9.27 (HVOUT13); also elsewhere on the board
T1_A_K: U9.26 (HVOUT14); also elsewhere on the board
T1_A_L: U9.25 (HVOUT15); also elsewhere on the board
T1_A_M: U9.20 (HVOUT16); also elsewhere on the board
T1_A_N: U9.19 (HVOUT17); also elsewhere on the board
T1_A_PL: U9.17 (HVOUT18); also elsewhere on the board
T1_A_PR: U9.16 (HVOUT19); also elsewhere on the board
T2_A_A1: U8.20 (HVOUT16); also elsewhere on the board
T2_A_A2: U8.19 (HVOUT17); also elsewhere on the board
T2_A_B: U8.17 (HVOUT18); also elsewhere on the board
T2_A_C: U8.16 (HVOUT19); also elsewhere on the board
T2_A_D1: U8.14 (HVOUT21); also elsewhere on the board
T2_A_D2: U8.15 (HVOUT20); also elsewhere on the board
T2_A_E: U8.13 (HVOUT22); also elsewhere on the board
T2_A_F: U8.12 (HVOUT23); also elsewhere on the board
T2_A_G1: U8.11 (HVOUT24); also elsewhere on the board
T2_A_G2: U8.10 (HVOUT25); also elsewhere on the board
T2_A_H: U8.9 (HVOUT26); also elsewhere on the board
T2_A_J: U8.8 (HVOUT27); also elsewhere on the board
T2_A_K: U8.7 (HVOUT28); also elsewhere on the board
T2_A_L: U8.5 (HVOUT29); also elsewhere on the board
T2_A_M: U8.4 (HVOUT30); also elsewhere on the board
T2_A_N: U8.3 (HVOUT31); also elsewhere on the board
T2_A_PL: U9.42 (HVOUT0); also elsewhere on the board
T2_A_PR: U9.41 (HVOUT1); also elsewhere on the board
T3_A_A1: U7.4 (HVOUT30); also elsewhere on the board
T3_A_A2: U7.3 (HVOUT31); also elsewhere on the board
T3_A_B: U8.42 (HVOUT0); also elsewhere on the board
T3_A_C: U8.41 (HVOUT1); also elsewhere on the board
T3_A_D1: U8.39 (HVOUT3); also elsewhere on the board
T3_A_D2: U8.40 (HVOUT2); also elsewhere on the board
T3_A_E: U8.38 (HVOUT4); also elsewhere on the board
T3_A_F: U8.37 (HVOUT5); also elsewhere on the board
T3_A_G1: U8.36 (HVOUT6); also elsewhere on the board
T3_A_G2: U8.35 (HVOUT7); also elsewhere on the board
T3_A_H: U8.34 (HVOUT8); also elsewhere on the board
T3_A_J: U8.33 (HVOUT9); also elsewhere on the board
T3_A_K: U8.32 (HVOUT10); also elsewhere on the board
T3_A_L: U8.31 (HVOUT11); also elsewhere on the board
T3_A_M: U8.30 (HVOUT12); also elsewhere on the board
T3_A_N: U8.27 (HVOUT13); also elsewhere on the board
T3_A_PL: U8.26 (HVOUT14); also elsewhere on the board
T3_A_PR: U8.25 (HVOUT15); also elsewhere on the board
T4_A_A1: U7.30 (HVOUT12); also elsewhere on the board
T4_A_A2: U7.27 (HVOUT13); also elsewhere on the board
T4_A_B: U7.26 (HVOUT14); also elsewhere on the board
T4_A_C: U7.25 (HVOUT15); also elsewhere on the board
T4_A_D1: U7.19 (HVOUT17); also elsewhere on the board
T4_A_D2: U7.20 (HVOUT16); also elsewhere on the board
T4_A_E: U7.17 (HVOUT18); also elsewhere on the board
T4_A_F: U7.16 (HVOUT19); also elsewhere on the board
T4_A_G1: U7.15 (HVOUT20); also elsewhere on the board
T4_A_G2: U7.14 (HVOUT21); also elsewhere on the board
T4_A_H: U7.13 (HVOUT22); also elsewhere on the board
T4_A_J: U7.12 (HVOUT23); also elsewhere on the board
T4_A_K: U7.11 (HVOUT24); also elsewhere on the board
T4_A_L: U7.10 (HVOUT25); also elsewhere on the board
T4_A_M: U7.9 (HVOUT26); also elsewhere on the board
T4_A_N: U7.8 (HVOUT27); also elsewhere on the board
T4_A_PL: U7.7 (HVOUT28); also elsewhere on the board
T4_A_PR: U7.5 (HVOUT29); also elsewhere on the board
T5_A_A1: U6.9 (HVOUT26); also elsewhere on the board
T5_A_A2: U6.8 (HVOUT27); also elsewhere on the board
T5_A_B: U6.7 (HVOUT28); also elsewhere on the board
T5_A_C: U6.5 (HVOUT29); also elsewhere on the board
T5_A_D1: U6.3 (HVOUT31); also elsewhere on the board
T5_A_D2: U6.4 (HVOUT30); also elsewhere on the board
T5_A_E: U7.42 (HVOUT0); also elsewhere on the board
T5_A_F: U7.41 (HVOUT1); also elsewhere on the board
T5_A_G1: U7.40 (HVOUT2); also elsewhere on the board
T5_A_G2: U7.39 (HVOUT3); also elsewhere on the board
T5_A_H: U7.38 (HVOUT4); also elsewhere on the board
T5_A_J: U7.37 (HVOUT5); also elsewhere on the board
T5_A_K: U7.36 (HVOUT6); also elsewhere on the board
T5_A_L: U7.35 (HVOUT7); also elsewhere on the board
T5_A_M: U7.34 (HVOUT8); also elsewhere on the board
T5_A_N: U7.33 (HVOUT9); also elsewhere on the board
T5_A_PL: U7.32 (HVOUT10); also elsewhere on the board
T5_A_PR: U7.31 (HVOUT11); also elsewhere on the board
T6_A_A1: U6.34 (HVOUT8); also elsewhere on the board
T6_A_A2: U6.33 (HVOUT9); also elsewhere on the board
T6_A_B: U6.32 (HVOUT10); also elsewhere on the board
T6_A_C: U6.31 (HVOUT11); also elsewhere on the board
T6_A_D1: U6.27 (HVOUT13); also elsewhere on the board
T6_A_D2: U6.30 (HVOUT12); also elsewhere on the board
T6_A_E: U6.26 (HVOUT14); also elsewhere on the board
T6_A_F: U6.25 (HVOUT15); also elsewhere on the board
T6_A_G1: U6.20 (HVOUT16); also elsewhere on the board
T6_A_G2: U6.19 (HVOUT17); also elsewhere on the board
T6_A_H: U6.17 (HVOUT18); also elsewhere on the board
T6_A_J: U6.16 (HVOUT19); also elsewhere on the board
T6_A_K: U6.15 (HVOUT20); also elsewhere on the board
T6_A_L: U6.14 (HVOUT21); also elsewhere on the board
T6_A_M: U6.13 (HVOUT22); also elsewhere on the board
T6_A_N: U6.12 (HVOUT23); also elsewhere on the board
T6_A_PL: U6.11 (HVOUT24); also elsewhere on the board
T6_A_PR: U6.10 (HVOUT25); also elsewhere on the board
T7_A_A1: U5.13 (HVOUT22); also elsewhere on the board
T7_A_A2: U5.12 (HVOUT23); also elsewhere on the board
T7_A_B: U5.11 (HVOUT24); also elsewhere on the board
T7_A_C: U5.10 (HVOUT25); also elsewhere on the board
T7_A_D1: U5.8 (HVOUT27); also elsewhere on the board
T7_A_D2: U5.9 (HVOUT26); also elsewhere on the board
T7_A_E: U5.7 (HVOUT28); also elsewhere on the board
T7_A_F: U5.5 (HVOUT29); also elsewhere on the board
T7_A_G1: U5.4 (HVOUT30); also elsewhere on the board
T7_A_G2: U5.3 (HVOUT31); also elsewhere on the board
T7_A_H: U6.42 (HVOUT0); also elsewhere on the board
T7_A_J: U6.41 (HVOUT1); also elsewhere on the board
T7_A_K: U6.40 (HVOUT2); also elsewhere on the board
T7_A_L: U6.39 (HVOUT3); also elsewhere on the board
T7_A_M: U6.38 (HVOUT4); also elsewhere on the board
T7_A_N: U6.37 (HVOUT5); also elsewhere on the board
T7_A_PL: U6.36 (HVOUT6); also elsewhere on the board
T7_A_PR: U6.35 (HVOUT7); also elsewhere on the board
T8_A_A1: U5.38 (HVOUT4); also elsewhere on the board
T8_A_A2: U5.37 (HVOUT5); also elsewhere on the board
T8_A_B: U5.36 (HVOUT6); also elsewhere on the board
T8_A_C: U5.35 (HVOUT7); also elsewhere on the board
T8_A_D1: U5.33 (HVOUT9); also elsewhere on the board
T8_A_D2: U5.34 (HVOUT8); also elsewhere on the board
T8_A_E: U5.32 (HVOUT10); also elsewhere on the board
T8_A_F: U5.31 (HVOUT11); also elsewhere on the board
T8_A_G1: U5.30 (HVOUT12); also elsewhere on the board
T8_A_G2: U5.27 (HVOUT13); also elsewhere on the board
T8_A_H: U5.26 (HVOUT14); also elsewhere on the board
T8_A_J: U5.25 (HVOUT15); also elsewhere on the board
T8_A_K: U5.20 (HVOUT16); also elsewhere on the board
T8_A_L: U5.19 (HVOUT17); also elsewhere on the board
T8_A_M: U5.17 (HVOUT18); also elsewhere on the board
T8_A_N: U5.16 (HVOUT19); also elsewhere on the board
T8_A_PL: U5.15 (HVOUT20); also elsewhere on the board
T8_A_PR: U5.14 (HVOUT21); also elsewhere on the board
T9_A_A1: U4.17 (HVOUT18); also elsewhere on the board
T9_A_A2: U4.16 (HVOUT19); also elsewhere on the board
T9_A_B: U4.15 (HVOUT20); also elsewhere on the board
T9_A_C: U4.14 (HVOUT21); also elsewhere on the board
T9_A_D1: U4.12 (HVOUT23); also elsewhere on the board
T9_A_D2: U4.13 (HVOUT22); also elsewhere on the board
T9_A_E: U4.11 (HVOUT24); also elsewhere on the board
T9_A_F: U4.10 (HVOUT25); also elsewhere on the board
T9_A_G1: U4.9 (HVOUT26); also elsewhere on the board
T9_A_G2: U4.8 (HVOUT27); also elsewhere on the board
T9_A_H: U4.7 (HVOUT28); also elsewhere on the board
T9_A_J: U4.5 (HVOUT29); also elsewhere on the board
T9_A_K: U4.4 (HVOUT30); also elsewhere on the board
T9_A_L: U4.3 (HVOUT31); also elsewhere on the board
T9_A_M: U5.42 (HVOUT0); also elsewhere on the board
T9_A_N: U5.41 (HVOUT1); also elsewhere on the board
T9_A_PL: U5.40 (HVOUT2); also elsewhere on the board
T9_A_PR: U5.39 (HVOUT3); also elsewhere on the board
T10_A_A1: U4.42 (HVOUT0); also elsewhere on the board
T10_A_A2: U4.41 (HVOUT1); also elsewhere on the board
T10_A_B: U4.40 (HVOUT2); also elsewhere on the board
T10_A_C: U4.39 (HVOUT3); also elsewhere on the board
T10_A_D1: U4.37 (HVOUT5); also elsewhere on the board
T10_A_D2: U4.38 (HVOUT4); also elsewhere on the board
T10_A_E: U4.36 (HVOUT6); also elsewhere on the board
T10_A_F: U4.35 (HVOUT7); also elsewhere on the board
T10_A_G1: U4.34 (HVOUT8); also elsewhere on the board
T10_A_G2: U4.33 (HVOUT9); also elsewhere on the board
T10_A_H: U4.32 (HVOUT10); also elsewhere on the board
T10_A_J: U4.31 (HVOUT11); also elsewhere on the board
T10_A_K: U4.30 (HVOUT12); also elsewhere on the board
T10_A_L: U4.27 (HVOUT13); also elsewhere on the board
T10_A_M: U4.26 (HVOUT14); also elsewhere on the board
T10_A_N: U4.25 (HVOUT15); also elsewhere on the board
T10_A_PL: U4.20 (HVOUT16); also elsewhere on the board
T10_A_PR: U4.19 (HVOUT17); also elsewhere on the board

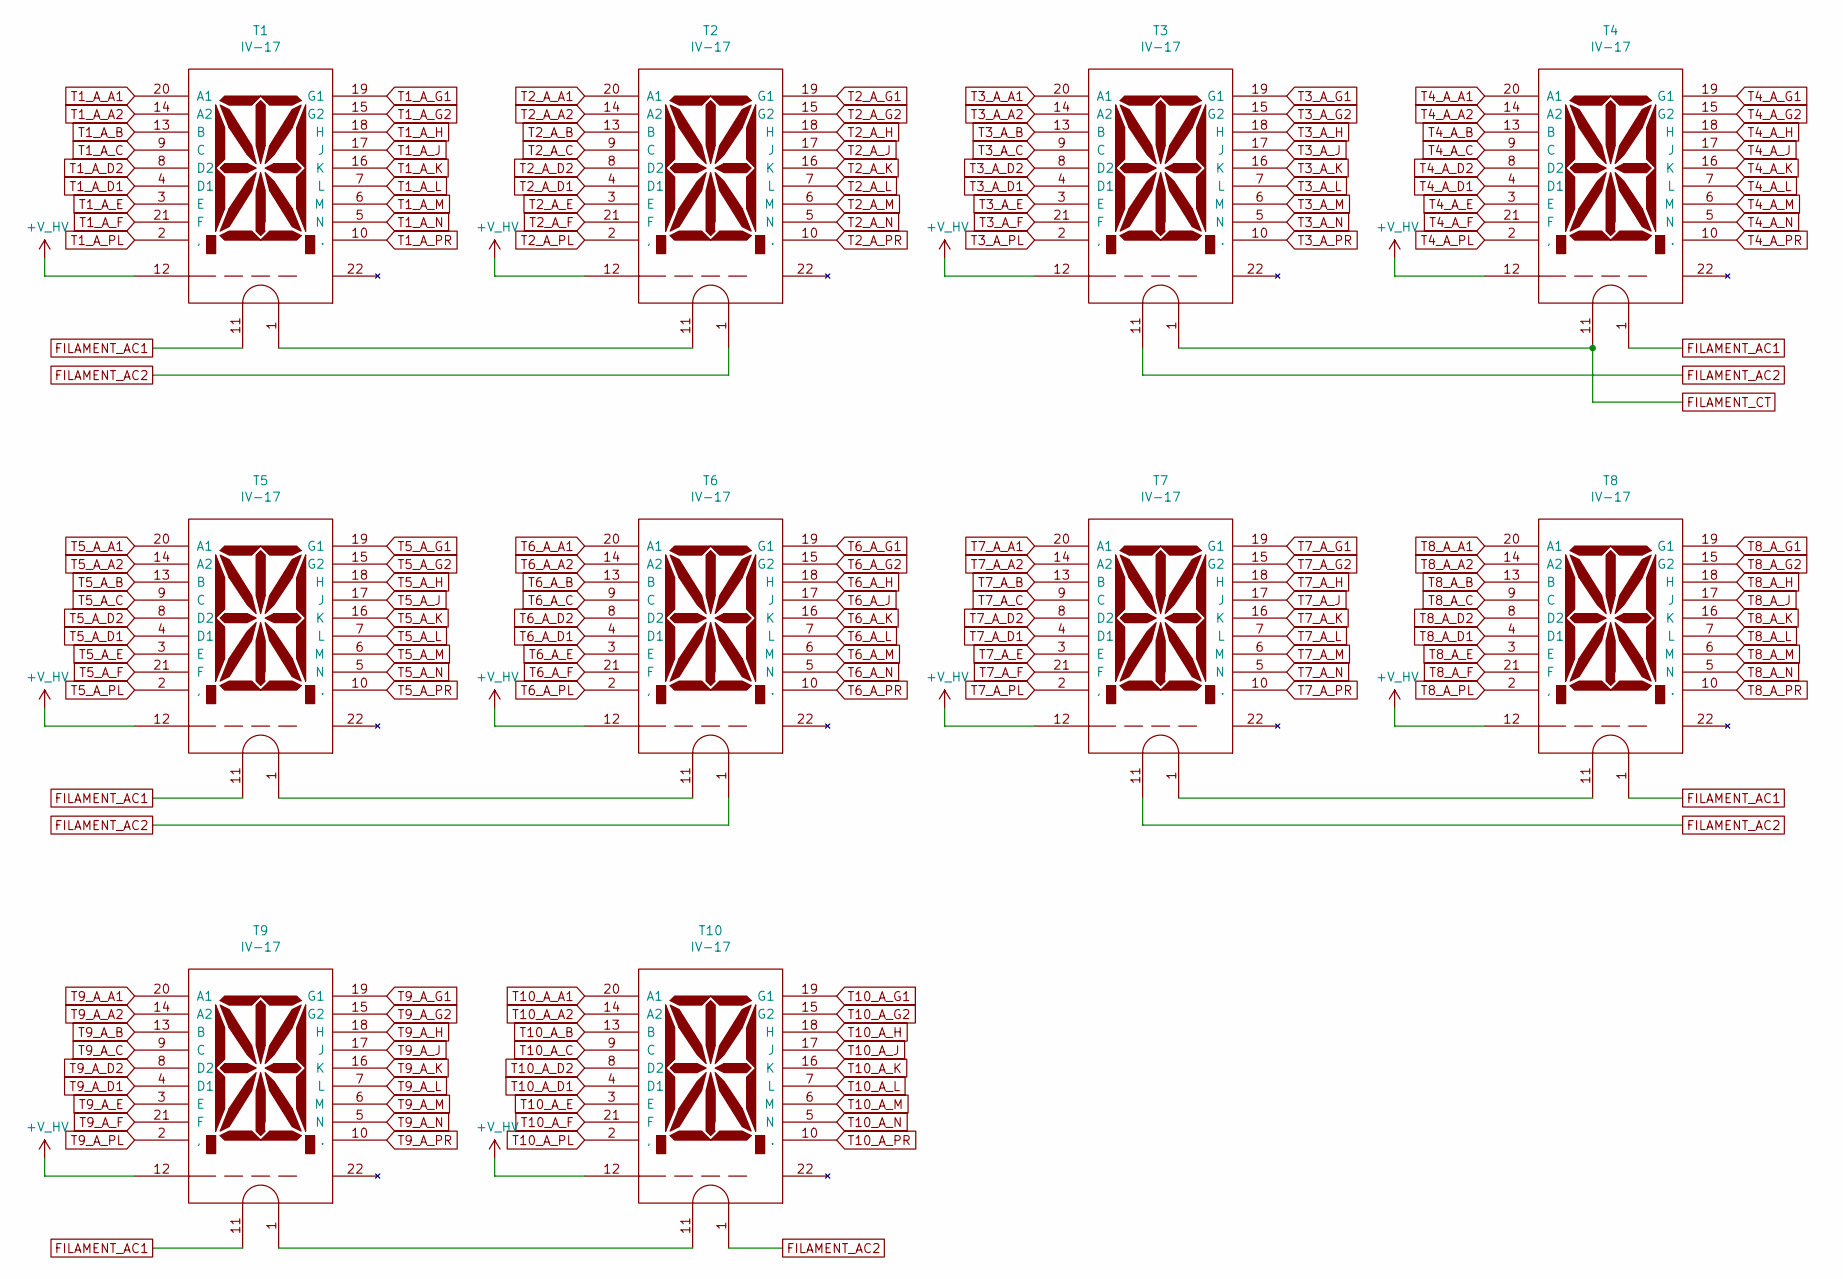
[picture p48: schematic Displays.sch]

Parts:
T1, T2, T3, T4, T5, T6, T7, T8, T9, T10: IV-17

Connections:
+V_HV: T1.12, T2.12, T3.12, T4.12, T5.12, T6.12, T7.12, T8.12, T9.12, T10.12; also elsewhere on the board
FILAMENT_AC1: T1.11, T4.1, T5.11, T8.1, T9.11; also elsewhere on the board
FILAMENT_AC2: T2.1, T3.11, T6.1, T7.11, T10.1; also elsewhere on the board
FILAMENT_CT: T3.1, T4.11; also elsewhere on the board
unnamed: T1.1, T2.11
unnamed: T5.1, T6.11
unnamed: T7.1, T8.11
unnamed: T9.1, T10.11
T1_A_A1: T1.20 (A1); also elsewhere on the board
T1_A_A2: T1.14 (A2); also elsewhere on the board
T1_A_B: T1.13 (B); also elsewhere on the board
T1_A_C: T1.9 (C); also elsewhere on the board
T1_A_D1: T1.4 (D1); also elsewhere on the board
T1_A_D2: T1.8 (D2); also elsewhere on the board
T1_A_E: T1.3 (E); also elsewhere on the board
T1_A_F: T1.21 (F); also elsewhere on the board
T1_A_G1: T1.19 (G1); also elsewhere on the board
T1_A_G2: T1.15 (G2); also elsewhere on the board
T1_A_H: T1.18 (H); also elsewhere on the board
T1_A_J: T1.17 (J); also elsewhere on the board
T1_A_K: T1.16 (K); also elsewhere on the board
T1_A_L: T1.7 (L); also elsewhere on the board
T1_A_M: T1.6 (M); also elsewhere on the board
T1_A_N: T1.5 (N); also elsewhere on the board
T1_A_PL: T1.2 (,); also elsewhere on the board
T1_A_PR: T1.10 (.); also elsewhere on the board
T2_A_A1: T2.20 (A1); also elsewhere on the board
T2_A_A2: T2.14 (A2); also elsewhere on the board
T2_A_B: T2.13 (B); also elsewhere on the board
T2_A_C: T2.9 (C); also elsewhere on the board
T2_A_D1: T2.4 (D1); also elsewhere on the board
T2_A_D2: T2.8 (D2); also elsewhere on the board
T2_A_E: T2.3 (E); also elsewhere on the board
T2_A_F: T2.21 (F); also elsewhere on the board
T2_A_G1: T2.19 (G1); also elsewhere on the board
T2_A_G2: T2.15 (G2); also elsewhere on the board
T2_A_H: T2.18 (H); also elsewhere on the board
T2_A_J: T2.17 (J); also elsewhere on the board
T2_A_K: T2.16 (K); also elsewhere on the board
T2_A_L: T2.7 (L); also elsewhere on the board
T2_A_M: T2.6 (M); also elsewhere on the board
T2_A_N: T2.5 (N); also elsewhere on the board
T2_A_PL: T2.2 (,); also elsewhere on the board
T2_A_PR: T2.10 (.); also elsewhere on the board
T3_A_A1: T3.20 (A1); also elsewhere on the board
T3_A_A2: T3.14 (A2); also elsewhere on the board
T3_A_B: T3.13 (B); also elsewhere on the board
T3_A_C: T3.9 (C); also elsewhere on the board
T3_A_D1: T3.4 (D1); also elsewhere on the board
T3_A_D2: T3.8 (D2); also elsewhere on the board
T3_A_E: T3.3 (E); also elsewhere on the board
T3_A_F: T3.21 (F); also elsewhere on the board
T3_A_G1: T3.19 (G1); also elsewhere on the board
T3_A_G2: T3.15 (G2); also elsewhere on the board
T3_A_H: T3.18 (H); also elsewhere on the board
T3_A_J: T3.17 (J); also elsewhere on the board
T3_A_K: T3.16 (K); also elsewhere on the board
T3_A_L: T3.7 (L); also elsewhere on the board
T3_A_M: T3.6 (M); also elsewhere on the board
T3_A_N: T3.5 (N); also elsewhere on the board
T3_A_PL: T3.2 (,); also elsewhere on the board
T3_A_PR: T3.10 (.); also elsewhere on the board
T4_A_A1: T4.20 (A1); also elsewhere on the board
T4_A_A2: T4.14 (A2); also elsewhere on the board
T4_A_B: T4.13 (B); also elsewhere on the board
T4_A_C: T4.9 (C); also elsewhere on the board
T4_A_D1: T4.4 (D1); also elsewhere on the board
T4_A_D2: T4.8 (D2); also elsewhere on the board
T4_A_E: T4.3 (E); also elsewhere on the board
T4_A_F: T4.21 (F); also elsewhere on the board
T4_A_G1: T4.19 (G1); also elsewhere on the board
T4_A_G2: T4.15 (G2); also elsewhere on the board
T4_A_H: T4.18 (H); also elsewhere on the board
T4_A_J: T4.17 (J); also elsewhere on the board
T4_A_K: T4.16 (K); also elsewhere on the board
T4_A_L: T4.7 (L); also elsewhere on the board
T4_A_M: T4.6 (M); also elsewhere on the board
T4_A_N: T4.5 (N); also elsewhere on the board
T4_A_PL: T4.2 (,); also elsewhere on the board
T4_A_PR: T4.10 (.); also elsewhere on the board
T5_A_A1: T5.20 (A1); also elsewhere on the board
T5_A_A2: T5.14 (A2); also elsewhere on the board
T5_A_B: T5.13 (B); also elsewhere on the board
T5_A_C: T5.9 (C); also elsewhere on the board
T5_A_D1: T5.4 (D1); also elsewhere on the board
T5_A_D2: T5.8 (D2); also elsewhere on the board
T5_A_E: T5.3 (E); also elsewhere on the board
T5_A_F: T5.21 (F); also elsewhere on the board
T5_A_G1: T5.19 (G1); also elsewhere on the board
T5_A_G2: T5.15 (G2); also elsewhere on the board
T5_A_H: T5.18 (H); also elsewhere on the board
T5_A_J: T5.17 (J); also elsewhere on the board
T5_A_K: T5.16 (K); also elsewhere on the board
T5_A_L: T5.7 (L); also elsewhere on the board
T5_A_M: T5.6 (M); also elsewhere on the board
T5_A_N: T5.5 (N); also elsewhere on the board
T5_A_PL: T5.2 (,); also elsewhere on the board
T5_A_PR: T5.10 (.); also elsewhere on the board
T6_A_A1: T6.20 (A1); also elsewhere on the board
T6_A_A2: T6.14 (A2); also elsewhere on the board
T6_A_B: T6.13 (B); also elsewhere on the board
T6_A_C: T6.9 (C); also elsewhere on the board
T6_A_D1: T6.4 (D1); also elsewhere on the board
T6_A_D2: T6.8 (D2); also elsewhere on the board
T6_A_E: T6.3 (E); also elsewhere on the board
T6_A_F: T6.21 (F); also elsewhere on the board
T6_A_G1: T6.19 (G1); also elsewhere on the board
T6_A_G2: T6.15 (G2); also elsewhere on the board
T6_A_H: T6.18 (H); also elsewhere on the board
T6_A_J: T6.17 (J); also elsewhere on the board
T6_A_K: T6.16 (K); also elsewhere on the board
T6_A_L: T6.7 (L); also elsewhere on the board
T6_A_M: T6.6 (M); also elsewhere on the board
T6_A_N: T6.5 (N); also elsewhere on the board
T6_A_PL: T6.2 (,); also elsewhere on the board
T6_A_PR: T6.10 (.); also elsewhere on the board
T7_A_A1: T7.20 (A1); also elsewhere on the board
T7_A_A2: T7.14 (A2); also elsewhere on the board
T7_A_B: T7.13 (B); also elsewhere on the board
T7_A_C: T7.9 (C); also elsewhere on the board
T7_A_D1: T7.4 (D1); also elsewhere on the board
T7_A_D2: T7.8 (D2); also elsewhere on the board
T7_A_E: T7.3 (E); also elsewhere on the board
T7_A_F: T7.21 (F); also elsewhere on the board
T7_A_G1: T7.19 (G1); also elsewhere on the board
T7_A_G2: T7.15 (G2); also elsewhere on the board
T7_A_H: T7.18 (H); also elsewhere on the board
T7_A_J: T7.17 (J); also elsewhere on the board
T7_A_K: T7.16 (K); also elsewhere on the board
T7_A_L: T7.7 (L); also elsewhere on the board
T7_A_M: T7.6 (M); also elsewhere on the board
T7_A_N: T7.5 (N); also elsewhere on the board
T7_A_PL: T7.2 (,); also elsewhere on the board
T7_A_PR: T7.10 (.); also elsewhere on the board
T8_A_A1: T8.20 (A1); also elsewhere on the board
T8_A_A2: T8.14 (A2); also elsewhere on the board
T8_A_B: T8.13 (B); also elsewhere on the board
T8_A_C: T8.9 (C); also elsewhere on the board
T8_A_D1: T8.4 (D1); also elsewhere on the board
T8_A_D2: T8.8 (D2); also elsewhere on the board
T8_A_E: T8.3 (E); also elsewhere on the board
T8_A_F: T8.21 (F); also elsewhere on the board
T8_A_G1: T8.19 (G1); also elsewhere on the board
T8_A_G2: T8.15 (G2); also elsewhere on the board
T8_A_H: T8.18 (H); also elsewhere on the board
T8_A_J: T8.17 (J); also elsewhere on the board
T8_A_K: T8.16 (K); also elsewhere on the board
T8_A_L: T8.7 (L); also elsewhere on the board
T8_A_M: T8.6 (M); also elsewhere on the board
T8_A_N: T8.5 (N); also elsewhere on the board
T8_A_PL: T8.2 (,); also elsewhere on the board
T8_A_PR: T8.10 (.); also elsewhere on the board
T9_A_A1: T9.20 (A1); also elsewhere on the board
T9_A_A2: T9.14 (A2); also elsewhere on the board
T9_A_B: T9.13 (B); also elsewhere on the board
T9_A_C: T9.9 (C); also elsewhere on the board
T9_A_D1: T9.4 (D1); also elsewhere on the board
T9_A_D2: T9.8 (D2); also elsewhere on the board
T9_A_E: T9.3 (E); also elsewhere on the board
T9_A_F: T9.21 (F); also elsewhere on the board
T9_A_G1: T9.19 (G1); also elsewhere on the board
T9_A_G2: T9.15 (G2); also elsewhere on the board
T9_A_H: T9.18 (H); also elsewhere on the board
T9_A_J: T9.17 (J); also elsewhere on the board
T9_A_K: T9.16 (K); also elsewhere on the board
T9_A_L: T9.7 (L); also elsewhere on the board
T9_A_M: T9.6 (M); also elsewhere on the board
T9_A_N: T9.5 (N); also elsewhere on the board
T9_A_PL: T9.2 (,); also elsewhere on the board
T9_A_PR: T9.10 (.); also elsewhere on the board
T10_A_A1: T10.20 (A1); also elsewhere on the board
T10_A_A2: T10.14 (A2); also elsewhere on the board
T10_A_B: T10.13 (B); also elsewhere on the board
T10_A_C: T10.9 (C); also elsewhere on the board
T10_A_D1: T10.4 (D1); also elsewhere on the board
T10_A_D2: T10.8 (D2); also elsewhere on the board
T10_A_E: T10.3 (E); also elsewhere on the board
T10_A_F: T10.21 (F); also elsewhere on the board
T10_A_G1: T10.19 (G1); also elsewhere on the board
T10_A_G2: T10.15 (G2); also elsewhere on the board
T10_A_H: T10.18 (H); also elsewhere on the board
T10_A_J: T10.17 (J); also elsewhere on the board
T10_A_K: T10.16 (K); also elsewhere on the board
T10_A_L: T10.7 (L); also elsewhere on the board
T10_A_M: T10.6 (M); also elsewhere on the board
T10_A_N: T10.5 (N); also elsewhere on the board
T10_A_PL: T10.2 (,); also elsewhere on the board
T10_A_PR: T10.10 (.); also elsewhere on the board



Board: 2 copper layers, 225.0 x 52.0 mm, 46 parts (30 on the bottom side), 212 nets.

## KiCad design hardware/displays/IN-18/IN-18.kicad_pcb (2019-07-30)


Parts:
C1, C2, C3, C4: 100 nF; C_0805_2012Metric
D1: 1N4148; D_SOD-123
H1, H2, H3, H4, H5, H6: MountingHole_Pad; MountingHole_3.2mm_M3_Pad_Via
J1: Conn_02x06_Odd_Even; PinSocket_2x06_P2.54mm_Vertical
NE1, NE2, NE3, NE4: Lamp_Neon; PinSocket_1x02_P2.54mm_Vertical
R1, R2, R3, R4, R5, R6: 2K2; R_1206_3216Metric
R7, R8, R9, R10: 470K; R_1206_3216Metric
R11: 10K; R_0805_2012Metric
T1, T2, T3, T4, T5, T6: IN-18_Nixie_Tube; Nixie_IN-18
U1: CD40109B; SOIC-16W_5.3x10.2mm_P1.27mm
U2, U3: HV5622; PLCC-44_16.6x16.6mm_P1.27mm

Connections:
+3V3: C1.1, J1.6, R11.1, U1.1 (VCC), U1.2 (ENABLE_A), U1.7 (ENABLE_B), U1.9 (ENABLE_C), U1.15 (ENABLE_D)
+V_HV: J1.2, R1.2, R2.2, R3.2, R4.2, R5.2, R6.2, R7.2, R8.2, R9.2, R10.2
+V_IN: C2.1, C3.1, C4.1, J1.3, U1.16 (VDD), U2.22 (~POL~), U2.25 (VDD), U3.22 (~POL~), U3.25 (VDD)
CLK: U1.11 (OUTPUT_C), U2.23 (CLK), U3.23 (CLK)
CLK_DB: J1.10, U1.10 (INPUT_C)
DATA_IN: U1.13 (OUTPUT_D), U2.27 (DATA_IN)
DATA_IN_DB: J1.11, U1.14 (INPUT_D)
DATA_OUT: D1.1 (K), U3.18 (DATA_OUT)
DATA_THROUGH: U2.18 (DATA_OUT), U3.27 (DATA_IN)
GND: C1.2, C2.2, C3.2, C4.2, H1.1, H2.1, H3.1, H4.1, H5.1, H6.1, J1.1, J1.4, J1.5, J1.8, U1.8 (VSS), U2.24 (VSS), U3.24 (VSS)
unnamed: D1.2 (A), J1.12, R11.2
unnamed: NE1.1, R7.1
unnamed: NE2.1, R8.1
unnamed: NE3.1, R9.1
unnamed: NE4.1, R10.1
unnamed: R1.1, T1.4 (A1), T1.12 (A2)
unnamed: R2.1, T2.4 (A1), T2.12 (A2)
unnamed: R3.1, T3.4 (A1), T3.12 (A2)
unnamed: R4.1, T4.4 (A1), T4.12 (A2)
unnamed: R5.1, T5.4 (A1), T5.12 (A2)
unnamed: R6.1, T6.4 (A1), T6.12 (A2)
T1_K_0: T1.13 (K_0), U2.8 (HVOUT10)
T1_K_1: T1.11 (K_1), U2.9 (HVOUT9)
T1_K_2: T1.10 (K_2), U2.10 (HVOUT8)
T1_K_3: T1.7 (K_3), U2.11 (HVOUT7)
T1_K_4: T1.2 (K_4), U2.12 (HVOUT6)
T1_K_5: T1.3 (K_5), U2.13 (HVOUT5)
T1_K_6: T1.5 (K_6), U2.14 (HVOUT4)
T1_K_7: T1.6 (K_7), U2.15 (HVOUT3)
T1_K_8: T1.9 (K_8), U2.16 (HVOUT2)
T1_K_9: T1.14 (K_9), U2.17 (HVOUT1)
T2_K_0: T2.13 (K_0), U2.42 (HVOUT20)
T2_K_1: T2.11 (K_1), U2.43 (HVOUT19)
T2_K_2: T2.10 (K_2), U2.44 (HVOUT18)
T2_K_3: T2.7 (K_3), U2.1 (HVOUT17)
T2_K_4: T2.2 (K_4), U2.2 (HVOUT16)
T2_K_5: T2.3 (K_5), U2.3 (HVOUT15)
T2_K_6: T2.5 (K_6), U2.4 (HVOUT14)
T2_K_7: T2.6 (K_7), U2.5 (HVOUT13)
T2_K_8: T2.9 (K_8), U2.6 (HVOUT12)
T2_K_9: T2.14 (K_9), U2.7 (HVOUT11)
T3_K_0: T3.13 (K_0), U2.32 (HVOUT30)
T3_K_1: T3.11 (K_1), U2.33 (HVOUT29)
T3_K_2: T3.10 (K_2), U2.34 (HVOUT28)
T3_K_3: T3.7 (K_3), U2.35 (HVOUT27)
T3_K_4: T3.2 (K_4), U2.36 (HVOUT26)
T3_K_5: T3.3 (K_5), U2.37 (HVOUT25)
T3_K_6: T3.5 (K_6), U2.38 (HVOUT24)
T3_K_7: T3.6 (K_7), U2.39 (HVOUT23)
T3_K_8: T3.9 (K_8), U2.40 (HVOUT22)
T3_K_9: T3.14 (K_9), U2.41 (HVOUT21)
T4_K_0: T4.13 (K_0), U3.10 (HVOUT8)
T4_K_1: T4.11 (K_1), U3.11 (HVOUT7)
T4_K_2: T4.10 (K_2), U3.12 (HVOUT6)
T4_K_3: T4.7 (K_3), U3.13 (HVOUT5)
T4_K_4: T4.2 (K_4), U3.14 (HVOUT4)
T4_K_5: T4.3 (K_5), U3.15 (HVOUT3)
T4_K_6: T4.5 (K_6), U3.16 (HVOUT2)
T4_K_7: T4.6 (K_7), U3.17 (HVOUT1)
T4_K_8: T4.9 (K_8), U2.30 (HVOUT32)
T4_K_9: T4.14 (K_9), U2.31 (HVOUT31)
T5_K_0: T5.13 (K_0), U3.44 (HVOUT18)
T5_K_1: T5.11 (K_1), U3.1 (HVOUT17)
T5_K_2: T5.10 (K_2), U3.2 (HVOUT16)
T5_K_3: T5.7 (K_3), U3.3 (HVOUT15)
T5_K_4: T5.2 (K_4), U3.4 (HVOUT14)
T5_K_5: T5.3 (K_5), U3.5 (HVOUT13)
T5_K_6: T5.5 (K_6), U3.6 (HVOUT12)
T5_K_7: T5.6 (K_7), U3.7 (HVOUT11)
T5_K_8: T5.9 (K_8), U3.8 (HVOUT10)
T5_K_9: T5.14 (K_9), U3.9 (HVOUT9)
T6_K_0: T6.13 (K_0), U3.34 (HVOUT28)
T6_K_1: T6.11 (K_1), U3.35 (HVOUT27)
T6_K_2: T6.10 (K_2), U3.36 (HVOUT26)
T6_K_3: T6.7 (K_3), U3.37 (HVOUT25)
T6_K_4: T6.2 (K_4), U3.38 (HVOUT24)
T6_K_5: T6.3 (K_5), U3.39 (HVOUT23)
T6_K_6: T6.5 (K_6), U3.40 (HVOUT22)
T6_K_7: T6.6 (K_7), U3.41 (HVOUT21)
T6_K_8: T6.9 (K_8), U3.42 (HVOUT20)
T6_K_9: T6.14 (K_9), U3.43 (HVOUT19)
T7_K: NE1.2, U3.30 (HVOUT32)
T8_K: NE2.2, U3.31 (HVOUT31)
T9_K: NE3.2, U3.32 (HVOUT30)
T10_K: NE4.2, U3.33 (HVOUT29)
~BL_DB~: J1.7, U1.6 (INPUT_B)
~BL~: U1.5 (OUTPUT_B), U2.28 (~BL~), U3.28 (~BL~)
~LE_DB~: J1.9, U1.3 (INPUT_A)
~LE~: U1.4 (OUTPUT_A), U2.26 (~LE~), U3.26 (~LE~)

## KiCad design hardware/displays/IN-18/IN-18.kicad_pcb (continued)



Board: 2 copper layers, 225.0 x 52.0 mm, 36 parts (24 on the bottom side), 89 nets.

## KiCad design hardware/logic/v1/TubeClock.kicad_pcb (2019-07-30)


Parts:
H1, H2, H3, H4: MountingHole_Pad; MountingHole_3.2mm_M3_Pad_Via
SB1: GS3; SolderJumper-3_P1.3mm_Open_Pad1.0x1.5mm

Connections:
/TubeClock-GPS/SQW_OUT_GPS: SB1.3 (G3); also elsewhere on the board
/TubeClock-MCU/SQW_IN: SB1.2 (G2); also elsewhere on the board
/TubeClock-Peripherals/SQW_OUT_RTC: SB1.1 (G1); also elsewhere on the board
GND: H1.1, H2.1, H3.1, H4.1; also elsewhere on the board


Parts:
BT1: CR2032; BatteryHolder_Keystone_3034_1x20mm; Part Number 103
C1: 100 uF; CP_Elec_8x10; Part Number 25SVF100M
C2: 100 uF 35 V; CP_EIA-7343-31_Kemet-D
C3: 4.7 uF; CP_Elec_10x10
C4: 10 uF 25 V; CP_EIA-7343-31_Kemet-D
C5, C6, C8, C11: 100 nF; C_0805_2012Metric
C7: 100 nF 250 V; C_2420_HandSoldering
C9: 10 uF; C_0805_2012Metric
C10: 100 uF; CP_Elec_5x5.3
C12: 470 mF; CP_Radial_D13.0mm_P5.00mm_HD1.5mm; Part Number KR-5R5H474-R
D1: S3A; D_SMC; Part Number S3A
D2: ES2F; D_SMB
D3: BAT64-04; SOT-23
D4: BAT64-02V; D_0603_1608Metric
F1: ~500mA; Fuse_2920_7451Metric; Part Number 2920L185DR
J1: Jack-DC; BarrelJack_Horizontal
L1: 100µH 2A; L_EPCOS_B82479A1_Handsoldering
Q1: IRF644PBF; TO-220-3_Horizontal_TabDown
R1: 100K; R_0805_2012Metric
R2: 1.5M; R_2512_6332Metric
R3: 56Ω 0.5W; R_0805_2012Metric
R4: 10K; R_0805_2012Metric
RSENSE1: .05; R_2010_5025Metric
RV1: 5K; Potentiometer_Bourns_3214W_Vertical
U1: MAX1771; SOIC-8_3.9x4.9mm_P1.27mm
U2: LD1117S33TR; TO-252-2; Part Number LD1117ADT33TR

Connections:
+3V3: C9.1, C10.1, D3.1 (A), R1.1, U2.2 (VO); also elsewhere on the board
+BATT: C11.1, D3.2 (K), D4.1 (K); also elsewhere on the board
+V_HV: C3.1, C7.1, D2.1 (K), R2.1; also elsewhere on the board
+V_IN: C1.1, C2.1, C4.1, C5.1, C8.1, D1.2 (K), L1.1, U1.2 (Vcc), U2.3 (VI); also elsewhere on the board
/TubeClock-MCU/SHUTDOWN: R1.2, U1.4 (SHDN); also elsewhere on the board
GND: BT1.2 (-), C1.2, C2.2, C3.2, C4.2, C5.2, C6.2, C7.2, C8.2, C9.2, C10.2, C11.2, C12.2, J1.2, J1.3, R4.2, RSENSE1.2, U1.6 (AGND), U1.7 (GND), U2.1 (GND); also elsewhere on the board
unnamed: BT1.1 (+), D4.2 (A)
unnamed: C6.1, U1.5 (REF)
unnamed: C12.1, R3.1
unnamed: D1.1 (A), F1.1
unnamed: D2.2 (A), L1.2, Q1.2 (D)
unnamed: D3.3 (common), R3.2
unnamed: F1.2, J1.1
unnamed: Q1.1 (G), U1.1 (EXT)
unnamed: Q1.3 (S), RSENSE1.1, U1.8 (CS)
unnamed: R2.2, RV1.1, U1.3 (FB)
unnamed: R4.1, RV1.2, RV1.3

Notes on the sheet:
Supercapacitor Eaton/PowerStor KR-5R5C474-R
Use anti-surge SMD chip! E.g.: Panasonic ERJ-P6WF56R0V
Note: The physical board layout is critical in order to obtain high efficiency!
High Efficiency (typically 85%) SMPS for Nixie Tubes - 50 mA, 150 V to 220 V Adjustable Boost converter notes: Q1 should be selected for low RDSon, Qg and Coss. Ex.: Vishay IRF644PBF; an IRF740A (note the “A”) will work but is more lossy. R1, C3, C7 must be rated for >220 V. D2 must be an ultra-fas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
DC input jack, fuse, polarity protection
Low-voltage regulation, battery/super-capacitor back-up
Boost converter for high voltage for tubes


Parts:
C13: 10 nF; C_0805_2012Metric
C14: 1 uF; C_0805_2012Metric
C15, C17, C18, C19, C23, C28: 100 nF; C_0805_2012Metric
C16, C20: 4.7 uF; C_0805_2012Metric
C21, C22: 47 nF; C_0805_2012Metric
C24, C25: 10 pF; C_0805_2012Metric
C26, C27: 12.5 pF; C_0805_2012Metric
D5: USBLC6; SOT-23-6
J2: Conn_02x08_Odd_Even; PinHeader_2x08_P2.54mm_Vertical
J3: Conn_02x05_Odd_Even; PinHeader_2x05_P2.54mm_Vertical
P1: STM32_SWD_USART; PinHeader_2x05_P1.27mm_Vertical_SMD; Part Number M50-3600542R
P2: CONN_MICRO_USB_B; USB_Micro-B_Molex-105017-0001
Q2: Q_Photo_NPN; LED_D5.0mm_Clear; Part Number TEPT5600
R5, R6, R8, R9, R11, R12: 1K; R_0805_2012Metric
R7, R13, R14, R15, R16: 10K; R_0805_2012Metric
R10: 1M; R_0805_2012Metric
R17: 68K; R_0805_2012Metric
R18: 47K; R_0805_2012Metric
RV2: 100K; Potentiometer_Vishay_TS53YJ_Vertical; Part Number TC33X-2-104E
SB2, SB3: GS3; SolderJumper-3_P1.3mm_Open_Pad1.0x1.5mm
SB4: GS2; SolderJumper-2_P1.3mm_Open_Pad1.0x1.5mm
SW1, SW2: SW_Push; SW_Push_1P1T_NO_CK_KMR2; Part Number KMR221G LFS
TP1: TouchPad1
TP2: TouchPad2; TouchPad1
TP3: TouchPad3; TouchPad1
TP4: TouchPad4; TouchPad1
TP5: TouchPad5; TouchPad1
TP6: TouchPad6; TouchPad1
U3: STM32F072RBTx; LQFP-64_10x10mm_P0.5mm
U4: TSOP382xx; Vishay_MINICAST-3Pin
Y1: 8 MHz; Crystal_SMD_5032-4Pin_5.0x3.2mm; Part Number ABM3B-8.000MHZ-10-1UT
Y2: 32.768 KHz; Crystal_SMD_3215-2Pin_3.2x1.5mm; Part Number ECX-.327-CDX-1293

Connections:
+3V3: C13.1, C14.1, C15.1, C16.1, C17.1, C18.1, C19.1, C20.1, C28.1, J2.2, J3.2, P1.1 (VCC), Q2.1 (C), R14.1, R15.1, R16.1, SW1.2, U3.13 (VDDA), U3.19 (VDD), U3.32 (VDD), U3.48 (VDDIO2), U3.64 (VDD), U4.3 (Vs); also elsewhere on the board
+BATT: U3.1 (VBAT); also elsewhere on the board
/TubeClock-Display/BLANK: U3.55 (I2S1_CK/SPI1_SCK/TIM2_CH2/TSC_G5_IO1/PB3); also elsewhere on the board
/TubeClock-Display/SPI1_MISO_DISP: U3.56 (I2S1_MCK/SPI1_MISO/TIM17_BKIN/TIM3_CH1/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); also elsewhere on the board
/TubeClock-Display/SPI1_MOSI: J3.3, U3.23 (ADC_IN7/COMP2_OUT/I2S1_SD/SPI1_MOSI/TIM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); also elsewhere on the board
/TubeClock-Display/SPI1_NSS_DISP: U3.51 (PC10/USART3_TX/USART4_TX); also elsewhere on the board
/TubeClock-Display/SPI1_SCK: J3.7, U3.21 (ADC_IN5/CEC/COMP1_INM/COMP2_INM/DAC_OUT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); also elsewhere on the board
/TubeClock-GPS/RESET: C23.1, P1.10 (NRST), R16.2, SW2.2, U3.7 (NRST); also elsewhere on the board
/TubeClock-GPS/USART1_RX: P1.8 (RXD), U3.43 (TIM17_BKIN/TIM1_CH3/TSC_G4_IO2/USART1_R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); also elsewhere on the board
/TubeClock-GPS/USART1_TX: P1.6 (TXD), SB3.2 (G2); also elsewhere on the board
/TubeClock-MCU/BEEP: U3.41 (CRS_SYNC/RCC_MCO/TIM1_CH1/USART1_CK/PA8); also elsewhere on the board
/TubeClock-MCU/LED0: U3.37 (PC6/TIM3_CH1); also elsewhere on the board
/TubeClock-MCU/LED1: U3.38 (PC7/TIM3_CH2); also elsewhere on the board
/TubeClock-MCU/LED2: U3.39 (PC8/TIM3_CH3); also elsewhere on the board
/TubeClock-MCU/OSC32_IN: SB2.3 (G3); also elsewhere on the board
/TubeClock-MCU/SHUTDOWN: U3.20 (ADC_IN4/COMP1_INM/COMP2_INM/DAC_OUT1/I2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); also elsewhere on the board
/TubeClock-MCU/SPI1_MISO: J3.5, U3.22 (ADC_IN6/COMP1_OUT/I2S1_MCK/SPI1_MISO/TI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); also elsewhere on the board
/TubeClock-MCU/SPI1_NSS_RTC: J3.10, U3.52 (PC11/USART3_RX/USART4_RX); also elsewhere on the board
/TubeClock-MCU/SPI1_NSS_TEMP: J3.9, U3.53 (PC12/USART3_CK/USART4_CK); also elsewhere on the board
/TubeClock-MCU/SPI2_MISO: J3.6, U3.10 (PC2/ADC_IN12/I2S2_MCK/SPI2_MISO)
/TubeClock-MCU/SPI2_MOSI: J3.4, U3.11 (PC3/ADC_IN13/I2S2_SD/SPI2_MOSI)
/TubeClock-MCU/SPI2_SCK: J3.8, U3.29 (CEC/I2C2_SCL/I2S2_CK/SPI2_SCK/TIM2_CH3/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)
/TubeClock-MCU/SQW_IN: J2.14, U3.2 (PC13/RTC_OUT_ALARM/RTC_OUT_CALIB/RTC_TA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); also elsewhere on the board
/TubeClock-MCU/USART2_MODE: U3.15 (ADC_IN1/COMP1_INP/TIM15_CH1N/TIM2_CH2/T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); also elsewhere on the board
/TubeClock-MCU/USART2_RX: U3.17 (ADC_IN3/COMP2_INP/TIM15_CH2/TIM2_CH4/TS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); also elsewhere on the board
/TubeClock-MCU/USART2_TX: U3.16 (ADC_IN2/COMP2_INM/COMP2_OUT/SYS_WKUP4/T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); also elsewhere on the board
ADC_IN: Q2.2 (E), R7.1, R10.1, U3.8 (PC0/ADC_IN10)
BOOT0: P1.7 (BOOT0), R13.2, SW1.1, U3.60 (BOOT0)
G3_CS: C21.1, U3.28 (TSC_G3_IO4/PB2)
G3_K1: R5.1, U3.25 (PC5/ADC_IN15/SYS_WKUP5/TSC_G3_IO1/USART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)
G3_K2: R6.1, U3.26 (ADC_IN8/TIM1_CH2N/TIM3_CH3/TSC_G3_IO2/U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)
G3_K3: R8.1, U3.27 (ADC_IN9/TIM14_CH1/TIM1_CH3N/TIM3_CH4/TS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)
G6_CS: C22.1, U3.35 (I2C2_SDA/I2S2_MCK/SPI2_MISO/TIM15_CH1/T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)
G6_K1: R9.1, U3.30 (I2C2_SDA/TIM2_CH4/TSC_G6_IO1/USART3_RX/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)
G6_K2: R11.1, U3.33 (I2S2_WS/SPI2_NSS/TIM15_BKIN/TIM1_BKIN/T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)
G6_K3: R12.1, U3.34 (I2C2_SCL/I2S2_CK/SPI2_SCK/TIM1_CH1N/TSC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)
GND: C13.2, C14.2, C15.2, C16.2, C17.2, C18.2, C19.2, C20.2, C21.2, C22.2, C23.2, C24.2, C25.2, C26.1, C27.2, C28.2, D5.2 (GND), J2.1, J3.1, P1.3 (GND), P1.5 (GND), P2.5 (GND), P2.6 (SHLD), R10.2, R13.1, R17.1, RV2.2, RV2.3, SW2.1, U3.12 (VSSA), U3.18 (VSS), U3.31 (VSS), U3.47 (VSS), U3.63 (VSS), U4.2 (GND); also elsewhere on the board
unnamed: C24.1, U3.5 (PF0/CRS_SYNC/RCC_OSC_IN), Y1.2
unnamed: C25.1, U3.6 (PF1/RCC_OSC_OUT), Y1.1
unnamed: C26.2, U3.4 (PC15/RCC_OSC32_OUT), Y2.1
unnamed: C27.1, SB2.1 (G1), Y2.2
unnamed: D5.4 (I/O2), P2.2 (DN)
unnamed: D5.5 (VBUS), P2.1 (VBUS), R18.1
unnamed: D5.6 (I/O1), P2.3 (DP)
unnamed: R5.2, TP1.1
unnamed: R6.2, TP2.1
unnamed: R7.2, RV2.1
unnamed: R8.2, TP3.1
unnamed: R9.2, TP4.1
unnamed: R11.2, TP5.1
unnamed: R12.2, TP6.1
unnamed: R17.2, R18.2, SB4.2 (G2)
unnamed: SB2.2 (G2), U3.3 (PC14/RCC_OSC32_IN)
STM32_PA0: J2.16, U3.14 (ADC_IN0/COMP1_INM/COMP1_OUT/RTC_TAMP2/S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)
STM32_PA9: J2.4, SB3.3 (G3), SB4.1 (G1), U3.42 (DAC_EXTI9/TIM15_BKIN/TIM1_CH2/TSC_G4_IO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)
STM32_PA15: J2.6, U3.50 (I2S1_WS/SPI1_NSS/TIM2_CH1/TIM2_ETR/USAR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)
STM32_PB5: J2.8, U3.57 (I2C1_SMBA/I2S1_SD/SPI1_MOSI/SYS_WKUP6/T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)
STM32_PB6: J2.3, SB3.1 (G1), U3.58 (I2C1_SCL/TIM16_CH1N/TSC_G5_IO3/USART1_T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)
STM32_PB7: J2.7, U3.59 (I2C1_SDA/TIM17_CH1N/TSC_G5_IO4/USART1_R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)
STM32_PB8: J2.10, U3.61 (CAN_RX/CEC/I2C1_SCL/TIM16_CH1/TSC_SYNC/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)
STM32_PB9: J2.12, U3.62 (CAN_TX/DAC_EXTI9/I2C1_SDA/I2S2_WS/IR_OU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)
STM32_PB15: J2.11, U3.36 (I2S2_SD/RTC_REFIN/SPI2_MOSI/SYS_WKUP7/T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), U4.1 (OUT)
STM32_PC1: J2.13, U3.9 (PC1/ADC_IN11)
STM32_PC4: J2.15, U3.24 (PC4/ADC_IN14/USART3_TX)
STM32_PC9: J2.9, U3.40 (PC9/DAC_EXTI9/TIM3_CH4)
STM32_PD2: J2.5, U3.54 (PD2/TIM3_ETR/USART3_DE/USART3_RTS)
SYS_SWCLK: P1.4 (SWCLK), R15.2, U3.49 (SYS_SWCLK/USART2_TX/PA14)
SYS_SWDIO: P1.2 (SWDIO), R14.2, U3.46 (IR_OUT/SYS_SWDIO/USB_OE/PA13)
USB+: D5.1 (I/O1), U3.45 (CAN_TX/COMP2_OUT/TIM1_ETR/TSC_G4_IO4/US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)
USB-: D5.3 (I/O2), U3.44 (CAN_RX/COMP1_OUT/TIM1_CH4/TSC_G4_IO3/US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)

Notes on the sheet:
Place as close to VDDA as possible
Place as close to VDDIO as possible
Place each as close to VDD/VSS pairs as possible


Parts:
J4: Conn_02x06_Odd_Even; PinHeader_2x06_P2.54mm_Vertical

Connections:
+3V3: J4.6; also elsewhere on the board
+V_HV: J4.2; also elsewhere on the board
+V_IN: J4.3; also elsewhere on the board
/TubeClock-Display/BLANK: J4.7; also elsewhere on the board
/TubeClock-Display/SPI1_MISO_DISP: J4.12; also elsewhere on the board
/TubeClock-Display/SPI1_MOSI: J4.11; also elsewhere on the board
/TubeClock-Display/SPI1_NSS_DISP: J4.9; also elsewhere on the board
/TubeClock-Display/SPI1_SCK: J4.10; also elsewhere on the board
GND: J4.1, J4.4, J4.5, J4.8; also elsewhere on the board


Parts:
BZ1: Buzzer; Buzzer_16x14RM7.6; Part Number TDK SD1614TT-B1
C29, C30, C31, C32: 100 nF; C_0805_2012Metric
D6: 1N4148; D_SOD-123
J5: Conn_01x06; PinHeader_1x06_P2.54mm_Vertical
J6: Conn_02x03_Odd_Even; PinHeader_2x03_P2.54mm_Vertical
LED1: LED_RGB_COMMON_ANODE; LED_D5.0mm-4_RGB
LED2: LED_Dual_AACC; LED_Cree-PLCC4_3.2x2.8mm_CCW; Part Number CMD1522SRUGCTR8
Q3, Q4, Q5, Q6: 2N7002; SOT-23
R19, R20: 10K; R_0805_2012Metric
R21: 120; R_0805_2012Metric
R22: 0; R_0805_2012Metric
R23, R24, R25, R29: 1M; R_0805_2012Metric
R26, R27, R28: 1K; R_0805_2012Metric
SB5, SB6: GS2; SolderJumper-2_P1.3mm_Open_Pad1.0x1.5mm
U5: DS3234; SO-20_12.8x7.5mm_P1.27mm
U6: LM74; SOIC-8_3.9x4.9mm_P1.27mm; Part Number LM74CIMX-3/NOPB
U7: DS1722; SOIC-8_3.9x4.9mm_P1.27mm
U8: MAX485E; SOIC-8_3.9x4.9mm_P1.27mm; Part Number ST1480ACDR

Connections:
+3V3: C29.1, C30.2, C31.1, J5.3, R19.2, R20.2, R23.1, R24.1, R25.1, U5.4 (VCC), U6.8 (V+), U7.1 (VDDD), U7.7 (SERMODE), U7.8 (VDDA), U8.8 (VCC); also elsewhere on the board
+BATT: U5.16 (VBAT); also elsewhere on the board
+V_IN: BZ1.1 (-), D6.1 (K), LED1.2 (COMMON), LED2.1 (A1), LED2.2 (A2); also elsewhere on the board
/TubeClock-Display/SPI1_MOSI: U5.17 (DIN), U7.6 (SDI); also elsewhere on the board
/TubeClock-Display/SPI1_SCK: U5.18 (SCK), U5.20 (SCK), U6.2 (SC), U7.3 (SCLK); also elsewhere on the board
/TubeClock-GPS/RESET: C32.2, SB5.1 (G1); also elsewhere on the board
/TubeClock-GPS/USART1_RX: J5.4; also elsewhere on the board
/TubeClock-GPS/USART1_TX: J5.5; also elsewhere on the board
/TubeClock-MCU/BEEP: Q6.1 (G), R29.1; also elsewhere on the board
/TubeClock-MCU/LED0: Q3.1 (G), R23.2; also elsewhere on the board
/TubeClock-MCU/LED1: Q4.1 (G), R24.2; also elsewhere on the board
/TubeClock-MCU/LED2: Q5.1 (G), R25.2; also elsewhere on the board
/TubeClock-MCU/OSC32_IN: R19.1, U5.3 (32kHz); also elsewhere on the board
/TubeClock-MCU/SPI1_MISO: U5.19 (DOUT), U6.1 (SIO), U7.5 (SDO); also elsewhere on the board
/TubeClock-MCU/SPI1_NSS_RTC: U5.1 (~CS~); also elsewhere on the board
/TubeClock-MCU/SPI1_NSS_TEMP: U6.7 (NCS), U7.2 (CE); also elsewhere on the board
/TubeClock-MCU/USART2_MODE: U8.2 (~RE), U8.3 (DE); also elsewhere on the board
/TubeClock-MCU/USART2_RX: U8.1 (RO); also elsewhere on the board
/TubeClock-MCU/USART2_TX: U8.4 (DI); also elsewhere on the board
/TubeClock-Peripherals/SQW_OUT_RTC: R20.1, U5.5 (~INT~/SQW); also elsewhere on the board
GND: C29.2, C30.1, C31.2, J5.1, Q3.2 (S), Q4.2 (S), Q5.2 (S), Q6.2 (S), R22.2, R29.2, U5.2 (NC(CTG)), U5.7 (NC(CTG)), U5.8 (NC(CTG)), U5.9 (NC(CTG)), U5.10 (NC(CTG)), U5.11 (NC(CTG)), U5.12 (NC(CTG)), U5.13 (NC(CTG)), U5.14 (NC(CTG)), U5.15 (GND), U6.3 (NC), U6.4 (GND), U6.5 (NC), U6.6 (NC), U7.4 (GND), U8.5 (GND); also elsewhere on the board
unnamed: BZ1.2 (+), D6.2 (A), Q6.3 (D)
unnamed: C32.1, J5.6
unnamed: J6.1, J6.2, R22.1
unnamed: J6.3, J6.4, SB6.1 (G1), U8.7 (B)
unnamed: J6.5, J6.6, R21.1, U8.6 (A)
unnamed: LED1.1 (RED), LED2.3 (K1), R26.1
unnamed: LED1.3 (GREEN), LED2.4 (K2), R27.2
unnamed: LED1.4 (BLUE), R28.2
unnamed: Q3.3 (D), R26.2
unnamed: Q4.3 (D), R27.1
unnamed: Q5.3 (D), R28.1
unnamed: R21.2, SB6.2 (G2)
unnamed: SB5.2 (G2), U5.6 (~RST~)

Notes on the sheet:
Install DS1722 *OR* LM74 -- DO NOT INSTALL BOTH
Install LED25 *OR* LED26 DO NOT INSTALL BOTH


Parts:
C33, C43: 1 nF; C_0805_2012Metric
C34, C35, C36: 120 pF; C_0402_1005Metric
C37, C38, C39, C40, C41: 3.9 pF; C_0402_1005Metric
C42: 10 uF; C_0805_2012Metric
FL1: B39162B4327P810; Filter_1411-5_1.4x1.1mm
J7: Conn_01x07; PinSocket_1x07_P2.54mm_Vertical
J8: Conn_Coaxial; U.FL_Molex_MCRF_73412-0110_Vertical
L2: 100 nH; L_0402_1005Metric
L3: 5.6 nH; L_0402_1005Metric
R30, R31: 0; R_0402_1005Metric
R32: 100K; R_0805_2012Metric
R33: 10K; R_0805_2012Metric
SB7, SB8: GS2; SolderJumper-2_P1.3mm_Open_Pad1.0x1.5mm
U9: BGA824N6; TSNP-6-2_1.2x0.8mm
U10: Teseo-LIV3F; LCC-18
U11: TPS22943; SOT-353_SC-70-5

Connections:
+3V3: J7.2, U10.7 (VCC_IO), U10.8 (VCC); also elsewhere on the board
+BATT: J7.7, U10.6 (VBAT); also elsewhere on the board
+V_ANT: C34.1, C43.2, L2.1, U11.1 (VOUT)
+V_RF: C33.1, C42.2, R32.1, U9.2 (VCC), U10.14 (VCC_RF), U11.5 (VIN)
/TubeClock-GPS/RESET: U10.9 (~SYS_RST~); also elsewhere on the board
/TubeClock-GPS/SQW_OUT_GPS: J7.1, U10.4 (PPS); also elsewhere on the board
/TubeClock-GPS/USART1_RX: J7.5, SB7.2 (G2); also elsewhere on the board
/TubeClock-GPS/USART1_TX: J7.4, SB8.2 (G2); also elsewhere on the board
ANT_OFF: R33.1, U9.6 (ENABLE), U10.13 (ANT_OFF), U11.4 (ON)
GND: C33.2, C34.2, C37.1, C38.2, C39.2, C40.2, C41.2, C42.1, C43.1, FL1.2 (GND), FL1.3 (GND), FL1.5 (GND), J7.3, J8.2 (Ext), R33.2, U9.1 (GND), U9.4 (GND_RF), U10.1 (GND), U10.10 (GND_RF), U10.12 (GND_RF), U11.2 (GND); also elsewhere on the board
unnamed: C35.1, C37.2, L3.1
unnamed: C35.2, J8.1 (In), L2.2, R30.2
unnamed: C36.1, R31.2, U10.11 (RF_IN)
unnamed: C36.2, C40.1, C41.1, FL1.4 (OUT)
unnamed: C38.1, C39.1, FL1.1 (IN), U9.3 (RFOUT)
unnamed: L3.2, U9.5 (RFIN)
unnamed: R30.1, R31.1
unnamed: R32.2, U11.3 (~OC~)
unnamed: SB7.1 (G1), U10.2 (TX)
unnamed: SB8.1 (G1), U10.3 (RX)

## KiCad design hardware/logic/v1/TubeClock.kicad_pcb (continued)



Board: 4 copper layers, 150.0 x 70.0 mm, 143 parts (23 on the bottom side), 111 nets.

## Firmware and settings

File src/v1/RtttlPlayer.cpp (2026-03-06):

//
// kbx81's tube clock RTTTL player
// ---------------------------------------------------------------------------
// (c)2025 by kbx81. See LICENSE for details.
//
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
// Parses and plays RTTTL (Ring Tone Text Transfer Language) strings using
// the Hardware tone queue. Adapted from ESPHome's rtttl component.
//
// RTTTL format: "Name:d=<dur>,o=<oct>,b=<bpm>:<notes>"
//   - d: default note duration (1=whole, 2=half, 4=quarter, 8=eighth, 16, 32)
//   - o: default octave (4-7)
//   - b: BPM (beats per minute, quarter notes)
//   - notes: comma-separated, each is [duration][note][#][octave][.]
//     e.g. 8c#5. = dotted eighth C-sharp in octave 5
//
#include <cstdint>
#include <cstring>

#include "Hardware.h"
#include "RtttlPlayer.h"

namespace kbxTubeClock::RtttlPlayer {

// Note frequency table (Hz): index 0 = silence, 1-12 = C4-B4, 13-24 = C5-B5,
// 25-36 = C6-B6, 37-48 = C7-B7. Matches values from the ESPHome RTTTL component
// and the Arduino Tone library.
//
static const uint16_t cNotes[] = {
    1,  // silence (below cToneFrequencyMinimum; Hardware treats as timed silence)
    262,  277,  294,  311,  330,  349,  370,  392,  415,  440,  466,  494,   // C4-B4
    523,  554,  587,  622,  659,  698,  740,  784,  831,  880,  932,  988,   // C5-B5
    1047, 1109, 1175, 1245, 1319, 1397, 1480, 1568, 1661, 1760, 1865, 1976,  // C6-B6
    2093, 2217, 2349, 2489, 2637, 2794, 2960, 3136, 3322, 3520, 3729, 3951   // C7-B7
};

static const uint8_t cNotesCount = sizeof(cNotes) / sizeof(cNotes[0]);

// Maximum RTTTL string length that can be buffered for playback.
// Sized to consume the full SerialRemote payload (254 bytes max) minus the
// 3-byte "CBP" prefix, leaving 251 bytes for the RTTTL string itself.
//
static const uint8_t cRtttlBufferSize = 251;

// Playback buffer
//
static char _rtttl[cRtttlBufferSize + 1];
static uint8_t _length = 0;
static uint8_t _position = 0;  // parse position in _rtttl[]

// Header defaults (parsed from RTTTL header section)
//
static uint8_t _defaultDuration = 4;
static uint8_t _defaultOctave = 6;
static uint16_t _wholenote = 0;  // ms per whole note = 60000*4/bpm

// Next note pre-parsed and ready to feed into the Hardware queue
//
static uint16_t _nextFreq = 0;
static uint16_t _nextDur = 0;
static bool _hasNextNote = false;

// Playback state flags
//
static bool _playing = false;
static bool _finished = false;  // self-clearing, signals one completion event

// --- Read consecutive ASCII digits from _rtttl[_position], return as integer ---
//
static uint8_t _getInteger() {
  uint8_t ret = 0;
  while (_position < _length && _rtttl[_position] >= '0' && _rtttl[_position] <= '9') {
    ret = static_cast<uint8_t>(ret * 10 + (_rtttl[_position++] - '0'));
  }
  return ret;
}

// --- Map an RTTTL note character to a base cNotes[] index ---
// Returns 0 for silence (pause), 1-12 for C-B within one octave.
//
static uint8_t _noteIndex(char c) {
  switch (c) {
    case 'c':
      return 1;  // 'c#' is index 2
    case 'd':
      return 3;  // 'd#' is index 4
    case 'e':
      return 5;
    case 'f':
      return 6;  // 'f#' is index 7
    case 'g':
      return 8;  // 'g#' is index 9
    case 'a':
      return 10;  // 'a#' is index 11
    case 'b':
    case 'h':
      return 12;  // German 'h' = English 'b' natural
    case 'p':
    default:
      return 0;  // pause / silence
  }
}

// --- Advance _position to just past the next occurrence of character c ---
// Returns true if found; leaves _position at end of string if not found.
//
static bool _findChar(char c) {
  while (_position < _length) {
    if (_rtttl[_position++] == c) {
      return true;
    }
  }
  return false;
}

// --- Advance _position to just past the next occurrence of the two-char sequence c0,c1 ---
//
static bool _findStr2(char c0, char c1) {
  while (_position + 1 < _length) {
    if (_rtttl[_position] == c0 && _rtttl[_position + 1] == c1) {
      _position += 2;
      return true;
    }
    _position++;
  }
  return false;
}

// --- Parse the next note from _rtttl[_position], store result in freq/dur ---
// Returns true if a note was successfully parsed; false if end of string.
//
static bool _parseNote(uint16_t &freq, uint16_t &dur) {
  // Skip comma/space separators
  while (_position < _length && (_rtttl[_position] == ',' || _rtttl[_position] == ' ')) {
    _position++;
  }

  if (_position >= _length) {
    return false;
  }

  // Optional duration prefix (e.g. "8" in "8c5")
  uint8_t num = _getInteger();
  uint16_t noteDuration = (num > 0) ? (_wholenote / num) : (_wholenote / _defaultDuration);

  // Note character
  if (_position >= _length) {
    return false;
  }
  uint8_t note = _noteIndex(_rtttl[_position++]);

  // Optional sharp ('#')
  if (_position < _length && _rtttl[_position] == '#') {
    note++;
    _position++;
  }

  // Optional octave digit
  uint8_t scale = _getInteger();
  if (scale == 0) {
    scale = _defaultOctave;
  }

  // Optional dotted note ('.'): extends duration by 50%
  if (_position < _length && _rtttl[_position] == '.') {
    noteDuration += noteDuration / 2;
    _position++;
  }

  // Map note + octave to frequency
  if (note == 0) {
    // Pause: use NOTE_REST value (1 Hz, below cToneFrequencyMinimum).
    // Hardware::tone() clears the PWM output and runs the timer for 'dur' ms.
    freq = cNotes[0];
  } else {
    // Clamp octave to supported range (4-7)
    if (scale < 4) {
      scale = 4;
    }
    if (scale > 7) {
      scale = 7;
    }

    uint8_t idx = static_cast<uint8_t>((scale - 4) * 12 + note);
    freq = (idx < cNotesCount) ? cNotes[idx] : cNotes[0];
  }

  dur = noteDuration;
  return true;
}

void play(const char *rtttl, uint8_t length) {
  if (rtttl == nullptr || length == 0) {
    return;
  }

  // Copy (and truncate) the RTTTL string into the playback buffer
  if (length > cRtttlBufferSize) {
    length = cRtttlBufferSize;
  }
  memcpy(_rtttl, rtttl, length);
  _rtttl[length] = '\0';
  _length = length;
  _position = 0;

  // Defaults (may be overridden by RTTTL header)
  _defaultDuration = 4;
  _defaultOctave = 6;
  int bpm = 63;

  // Skip song name: find first ':'
  if (!_findChar(':')) {
    return;
  }

  // Parse "d=<n>" (default duration)
  if (!_findStr2('d', '=')) {
    return;
  }
  uint8_t num = _getInteger();
  if (num > 0) {
    _defaultDuration = num;
  }

  // Parse "o=<n>" (default octave)
  if (!_findStr2('o', '=')) {
    return;
  }
  num = _getInteger();
  if (num >= 3 && num <= 7) {
    _defaultOctave = num;
  }

  // Parse "b=<n>" (BPM)
  if (!_findStr2('b', '=')) {
    return;
  }
  num = _getInteger();
  if (num > 0) {
    bpm = num;
  }

  // Find second ':' to reach the note sequence
  if (!_findChar(':')) {
    return;
  }

  // BPM is expressed in quarter notes per minute; scale to whole-note duration
  _wholenote = static_cast<uint16_t>(60000UL * 4 / static_cast<uint32_t>(bpm));

  // Pre-parse the first note so loop() can feed it immediately
  _hasNextNote = _parseNote(_nextFreq, _nextDur);
  _playing = _hasNextNote;
  _finished = false;
}

void stop() {
  _playing = false;
  _hasNextNote = false;
}

void loop() {
  if (!_playing) {
    return;
  }

  if (!_hasNextNote) {
    // All notes have been accepted into the Hardware queue; signal completion.
    // The last queued note(s) will continue to play out in hardware.
    _playing = false;
    _finished = true;
    return;
  }

  // Attempt to feed the pre-parsed note into the Hardware tone queue
  Hardware::HwReqAck result = Hardware::tone(_nextFreq, _nextDur);

  if (result == Hardware::HwReqAckError) {
    // Both queue slots are full; try again on the next loop() call
    return;
  }

  // Note was accepted (started immediately or queued) -- advance the parser
  _hasNextNote = _parseNote(_nextFreq, _nextDur);
}

bool isPlaying() { return _playing; }

bool playingFinished() {
  if (_finished) {
    _finished = false;
    return true;
  }
  return false;
}

}  // namespace kbxTubeClock::RtttlPlayer

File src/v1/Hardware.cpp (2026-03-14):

//
// kbx81's tube clock Hardware class
// ---------------------------------------------------------------------------
// (c)2019 by kbx81. See LICENSE for details.
//
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

// #include <cstddef>
#include <cstdint>
// #include <errno.h>
// #include <stdio.h>
// #include <stdlib.h>
// #include <string.h>
#include <libopencm3/cm3/nvic.h>
#include <libopencm3/cm3/scb.h>
#include <libopencm3/cm3/systick.h>
#include <libopencm3/stm32/adc.h>
#include <libopencm3/stm32/crc.h>
#include <libopencm3/stm32/dma.h>
#include <libopencm3/stm32/exti.h>
#include <libopencm3/stm32/flash.h>
#include <libopencm3/stm32/gpio.h>
#include <libopencm3/stm32/i2c.h>
#include <libopencm3/stm32/iwdg.h>
#include <libopencm3/stm32/pwr.h>
#include <libopencm3/stm32/rcc.h>
#include <libopencm3/stm32/rtc.h>
#include <libopencm3/stm32/spi.h>
#include <libopencm3/stm32/syscfg.h>
#include <libopencm3/stm32/timer.h>
#include <libopencm3/stm32/tsc.h>
#include <libopencm3/stm32/usart.h>

#include "Application.h"
#include "DateTime.h"
#include "Display.h"
#include "DisplayManager.h"
#include "Dmx-512-Rx.h"
#include "DS1722.h"
#include "DS3234.h"
#include "GpsReceiver.h"
#include "Hardware.h"
#include "InfraredRemote.h"
#include "LM74.h"
#include "RgbLed.h"
#include "SpiMaster.h"
#include "Usart.h"
#include "UsbSerial.h"

#if HARDWARE_VERSION == 1
#include "Hardware_v1.h"
#else
#error HARDWARE_VERSION must be defined with a value of 1
#endif

namespace kbxTubeClock::Hardware {

// Bootloader flag -- placed in .noinit so it survives a system reset
// but is NOT preserved across power-on resets.
//
static __attribute__((section(".noinit"))) uint32_t _bootloaderMagic;
static constexpr uint32_t cBootloaderMagic = 0xDEADB007u;

// I2C1 state
//
enum I2cState : uint8_t { I2cIdle, I2cBusy };

// SPI interface initialization objects
//
static const SpiMaster::SpiMasterParams _spi1MasterParams = {
    SPI1,               // spi
    DMA1,               // dmaController
    cSpi1RxDmaChannel,  // channelRx
    cSpi1TxDmaChannel   // channelTx
};

// USART interface initialization objects
//
static const Usart::UsartParams _usartParams[cNumberOfUsarts] = {{
                                                                     cGpsUsart,            // USART
                                                                     DMA1,                 // dmaController
                                                                     cUsart1RxDmaChannel,  // channelRx
                                                                     cUsart1TxDmaChannel   // channelTx
                                                                 },
                                                                 {
                                                                     cDmxUsart,            // USART
                                                                     DMA1,                 // dmaController
                                                                     cUsart2RxDmaChannel,  // channelRx
                                                                     cUsart2TxDmaChannel   // channelTx
                                                                 },
                                                                 {
                                                                     cSerialRemoteUsartRx,  // USART
                                                                     0,                     // dmaController (no DMA)
                                                                     0,                     // channelRx (no DMA)
                                                                     0                      // channelTx (no DMA)
                                                                 },
                                                                 {
                                                                     cSerialRemoteUsartTx,  // USART
                                                                     0,                     // dmaController (no DMA)
                                                                     0,                     // channelRx (no DMA)
                                                                     0                      // channelTx (no DMA)
                                                                 }};
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

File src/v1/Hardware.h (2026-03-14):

//
// kbx81's tube clock Hardware class
// ---------------------------------------------------------------------------
// (c)2019 by kbx81. See LICENSE for details.
//
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
#pragma once

#include <cstddef>
#include <cstdint>

#include <libopencm3/stm32/usart.h>

#include "DateTime.h"
#include "Display.h"
#include "RgbLed.h"
#include "SpiMaster.h"
#include "Usart.h"

#ifndef HARDWARE_VERSION
#error HARDWARE_VERSION must be defined with a value of 1
#endif

namespace kbxTubeClock::Hardware {

/// @brief Hardware request return codes
///
enum HwReqAck : uint8_t { HwReqAckOk, HwReqAckBusy, HwReqAckError, HwReqAckQueued };

/// @brief What triggers peripheral refreshes
///
enum PeripheralRefreshTrigger : uint8_t { NoTrigger, PpsExti, SysTick };

/// @brief Result of RTC startup
///
enum RtcStartResult : uint8_t {
  UnknownError,
  Ok,          // Normal startup
  OscStopped,  // Oscillator was stopped, reinitialization occurred (clock will require updating)
  OscTimeout   // Oscillator did not start within the expected time (clock may not function)
};

/// @brief Type of temperature sensor connected, if any
///
enum RtcType : uint8_t { Stm32, DS323x };

/// @brief Type of temperature sensor connected, if any
///
enum TempSensorType : uint8_t { STM32ADC, DS3234, DS1722, LM74, ExternalSerial };

// Number of temperature sensor types
//
static const uint8_t cTempSensorCount = 5;

// DS3234 SRAM layout: Settings struct occupies [0, cOnTimeCounterSramOffset),
// on-time counter occupies [cOnTimeCounterSramOffset, cOnTimeCounterSramOffset + 4).
// Must be >= sizeof(Settings) (132 bytes); enforced by static_assert in Settings.cpp.
//
static const uint8_t cOnTimeCounterSramOffset = 132;

// Sentinel value for undetected/unavailable sensors (Cx10)
//
static const int32_t cTempSentinel = 32767;

// Number of USARTs to configure
//
static const uint8_t cNumberOfUsarts = 4;

// USART default/initial baud rates
//
static const uint32_t cUsart1BaudRate = 115200;
static const uint32_t cUsart2BaudRate = 250000;
static const uint32_t cUsart3BaudRate = 115200;
static const uint32_t cUsart4BaudRate = 115200;

// USART1 data transfer parameters
//
static const uint8_t cUsart1DataBits = 8;                                          // Number of data bits
static const auto cUsart1StopBits = USART_STOPBITS_1;                              // Number of stop bits
static const auto cUsart1Parity = USART_PARITY_NONE;                               // Parity
static const auto cUsart1Mode = USART_MODE_TX_RX;                                  // Mode (Tx, Rx, Tx+Rx)
static const auto cUsart1FlowControl = USART_FLOWCONTROL_NONE;                     // Flow control
static const auto cUsart1AutoBaud = USART_CR2_ABRMOD_FALL_EDGE | USART_CR2_ABREN;  // Enable auto-baud rate detection
static const auto cUsart1DriverEnable = false;  // Enable hardware DE output (for RS-485)
static const bool cUsart1SwapTxRx = false;      // TX/RX pin swap

// USART2 data transfer parameters
//
static const uint8_t cUsart2DataBits = 8;                       // Number of data bits
static const auto cUsart2StopBits = USART_STOPBITS_2;           // Number of stop bits
static const auto cUsart2Parity = USART_PARITY_NONE;            // Parity
static const auto cUsart2Mode = USART_MODE_RX;                  // Mode (Tx, Rx, Tx+Rx)
static const auto cUsart2FlowControl = USART_FLOWCONTROL_NONE;  // Flow control
static const auto cUsart2AutoBaud = 0;                          // Enable auto-baud rate detection
static const auto cUsart2DriverEnable = true;                   // Enable hardware DE output (for RS-485)
static const bool cUsart2SwapTxRx = false;                      // TX/RX pin swap

// USART3 data transfer parameters (serial remote RX, interrupt-driven, no DMA)
//
static const uint8_t cUsart3DataBits = 8;
static const auto cUsart3StopBits = USART_STOPBITS_1;
static const auto cUsart3Parity = USART_PARITY_NONE;
static const auto cUsart3Mode = USART_MODE_RX;
static const auto cUsart3FlowControl = USART_FLOWCONTROL_NONE;
static const auto cUsart3AutoBaud = 0;
static const auto cUsart3DriverEnable = false;
static const bool cUsart3SwapTxRx = true;

// USART4 data transfer parameters (serial remote TX, interrupt-driven, no DMA)
//
static const uint8_t cUsart4DataBits = 8;
static const auto cUsart4StopBits = USART_STOPBITS_1;
static const auto cUsart4Parity = USART_PARITY_NONE;
static const auto cUsart4Mode = USART_MODE_TX;
static const auto cUsart4FlowControl = USART_FLOWCONTROL_NONE;
static const auto cUsart4AutoBaud = 0;
static const auto cUsart4DriverEnable = false;
static const bool cUsart4SwapTxRx = false;

/// @brief Hardware version to build for
///
static const uint32_t cTargetHardwareVersion = HARDWARE_VERSION;

/// @brief Check whether a bootloader reset was requested (reads .noinit magic)
///  Must be called before initialize() — requires no peripheral clocks.
bool isBootloaderFlagSet();
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

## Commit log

2019-07-30 Initial commit. Yay\!
    [Base.dxf, Displays.sch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]
2019-08-02 Updated BoMs with more notes
    [TubeClock-PowerSupply.sch]
2019-08-02 BoM copy updates
2019-08-07 Updated component specs
    [TubeClock-PowerSupply.sch]
2019-09-11 Relaxed SPI clock a lil' bit
2019-10-07 DMX-512 implementation and other fixes/updates
    [DS3234.cpp, Hardware.cpp]
2020-04-11 BoM tweak
2024-12-19 Add Display board for Burroughs B-5991 Nixie Tubes (aka 8422), also supplied by National
    [B5991-B_Cu.gbr, B5991-B_Mask.gbr, B5991-B_Paste.gbr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]
2026-02-22 led, rtttl, fix, preen
    [DisplayManager.cpp, Hardware.cpp, Hardware.h]
2026-02-26 build, keys, ota, timer

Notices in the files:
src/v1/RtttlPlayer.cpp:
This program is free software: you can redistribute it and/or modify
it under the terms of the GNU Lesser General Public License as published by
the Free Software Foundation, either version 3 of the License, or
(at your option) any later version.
